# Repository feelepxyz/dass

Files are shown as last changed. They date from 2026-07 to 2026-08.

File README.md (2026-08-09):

# DASS

## A small outdoor toilet, drawn from a parametric model

[Open the interactive cut guide and model](https://feelep.xyz/dass)

| Attribution | Detail |
| --- | --- |
| Design source | Hannes Söderquist's outdoor toilet design |
| CAD | CadQuery and Python |
| Text-to-CAD reference | [earthtojake/text-to-cad](https://github.com/earthtojake/text-to-cad) |
| Current material | 45 × 45 mm beams and 120 × 23 mm Råspont (matchboard/V-groove cladding) |

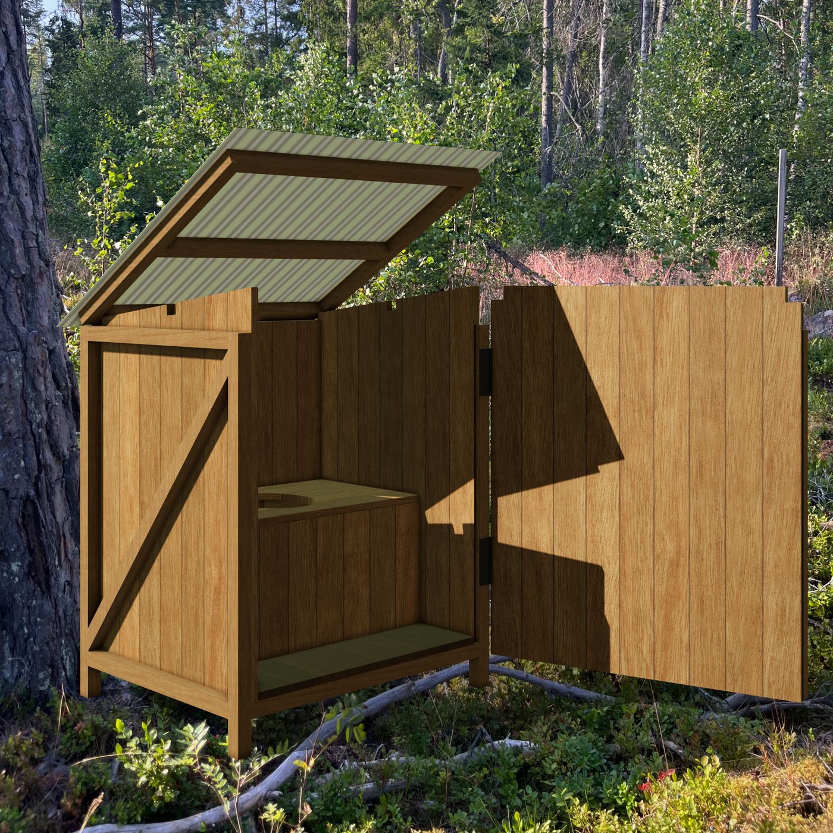
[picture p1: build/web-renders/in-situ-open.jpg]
Open in-situ render


This repository contains the parametric model, the browser cut guide, and the
source material for a small outdoor toilet. The live guide shows the open and
closed model, the unit drawings, and the workshop cut sequence.

## Current release

Version `0.1.8` clears the Hold boxes off the working drawing, so each unit
sheet runs from its general arrangement straight into its first numbered step.
Read the [full changelog](CHANGELOG.md).

## Run the guide

```sh
uv sync
uv run serve-guide
```

This builds the cut schedules, the guide and progress pages, the GLB models the
viewer loads, and the browser assets, then serves them and opens
<http://localhost:8000/cut-guide.html>. It uses HTTP because the guide loads ES
modules, the GLB models, and its textures, which a `file://` page cannot read.
It installs the renderer's Node dependencies the first time, and it moves to the
next free port if 8000 is taken.

Leave it running. When you save a source file it rebuilds the parts of the guide
that read it and the open page reloads itself.

| Option | Effect |
| --- | --- |
| `--port 8080` | Prefer this port instead of 8000 |
| `--renders` | Re-photograph the model first; minutes of headless Chromium |
| `--page how-its-going.html` | Open a different page |
| `--page how-it-started.html` | Open the project history page |
| `--no-open` | Leave the browser alone |

The photorealistic images are the one thing a save does not rebuild. Make them
when the model changes:

```sh
uv run render-photo
```

Each step also runs on its own; `AGENTS.md` lists them.

The deploy command rebuilds the guide and publishes the Worker:

```sh
./scripts/deploy-cut-guide.sh
```

The main Python commands accept parameter overrides. For example:

```sh
uv run dass --set width=1050 --set seat_depth=550
uv run render-photo --views open-hero --skip-build
```

## Git hooks

`prek` checks each commit and runs the tests before each push:

```sh
prek install          # once, after cloning
prek run --all-files  # run every hook now
```

The commit hooks run `ruff format`, `ruff check`, and `ty`, and they cover shell
scripts, file hygiene, and YAML, JSON, and TOML syntax. The push hook runs the
`pytest` suite, which takes about half a minute. They skip `.agents/`, `build/`,
and `.cache/`, which hold vendored and generated files. Bypass them with
`git commit --no-verify` when you must.

GitHub Actions runs the same four checks on every push and pull request, on
Python 3.11 and 3.14.

## Worktrees

`wta <branch>` opens a worktree with the agent and the guide server already
running, from the hooks in `.config/wt.toml`:

```sh
wta fix-seat        # new worktree off the default branch
wt list             # what is checked out where
wt remove           # tear the worktree and its panes down
```

The guide pane runs `serve-guide --no-open`. It takes the next free port, so
several worktrees can serve their own guide at the same time.

## Model

The current design has a 990 × 815 mm outside envelope. It uses 45 × 45 mm
frame stock and 120 × 23 mm interleaved Råspont (matchboard/V-groove cladding). Each board has 110 mm of
effective cover and a 10 mm trim allowance.

The door is nine covers wide. Each side is seven covers deep. The rear wall,
floor, seat top, and seat front use the fitted spans from the frame. The roof
uses a 1050 × 1085 mm metal sheet over a hinged 45 mm timber frame.

The model is the dimensional source of truth. The cut-list generator derives
the piece schedules and the stop-block sequence from that model. It reserves a
kerf for each released piece and keeps equal-length cuts together.

The guide treats the roof, door, side walls, back wall, floor, and seat as
separate units. This keeps the drawings, part codes, and workshop order tied to
the geometry.

## Unit drawings

These images show the guide's line finish. They show the frame and model edges,
without the photoreal material finish or assembly instructions.

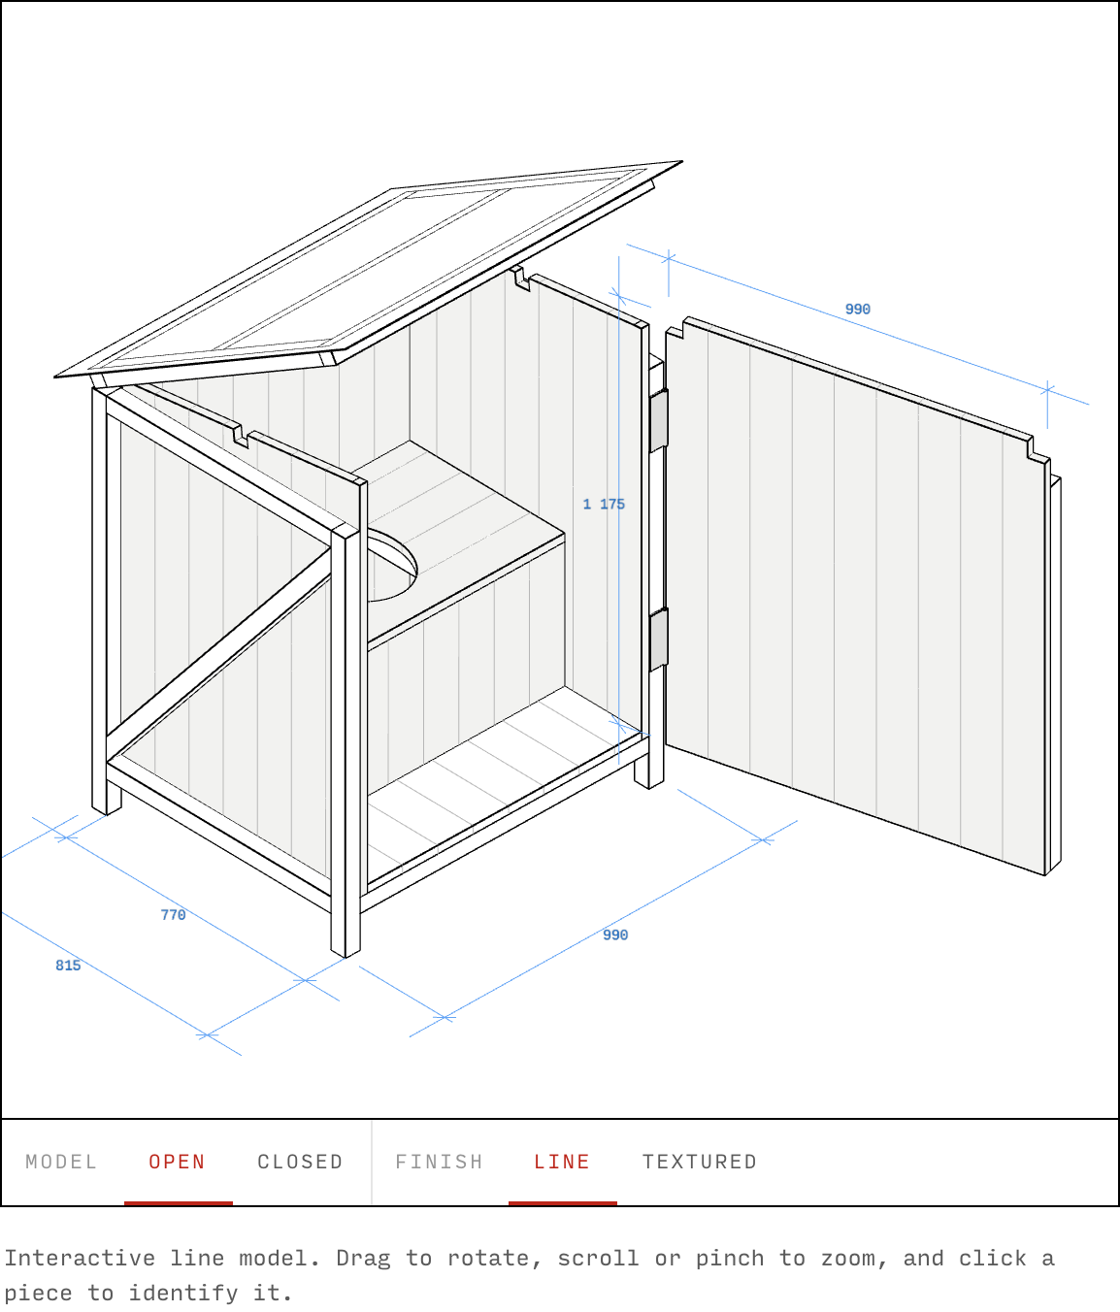
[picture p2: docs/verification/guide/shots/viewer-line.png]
Open frame model


The open frame model shows the roof, door, left and right side units, back wall,
floor deck, and seat box as separate pieces around the same model datum.

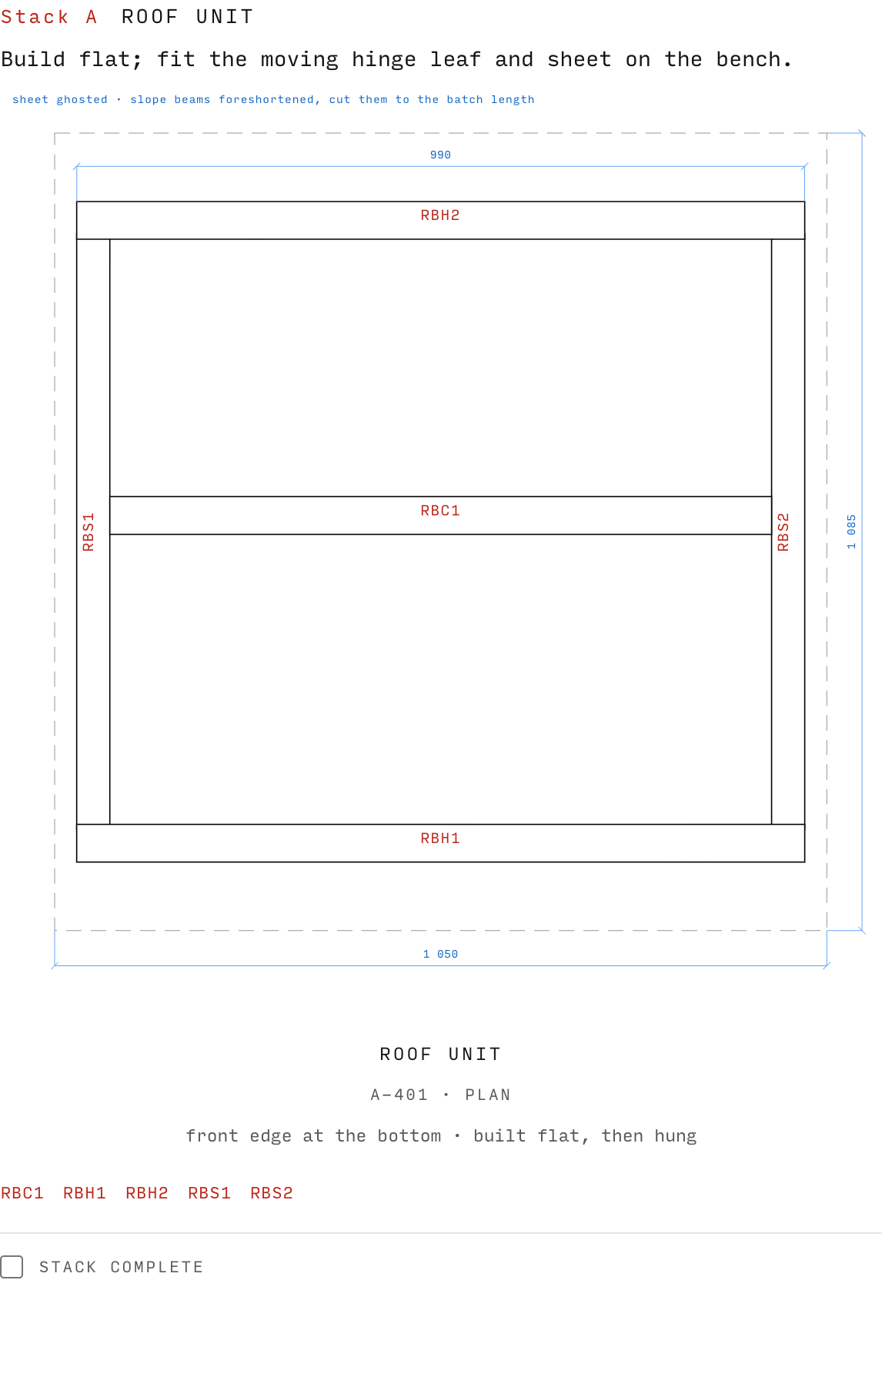
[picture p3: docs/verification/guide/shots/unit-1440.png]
Roof unit drawing


The roof unit is a hinged rectangular frame with two slope beams, two cross
beams, and one middle connector.

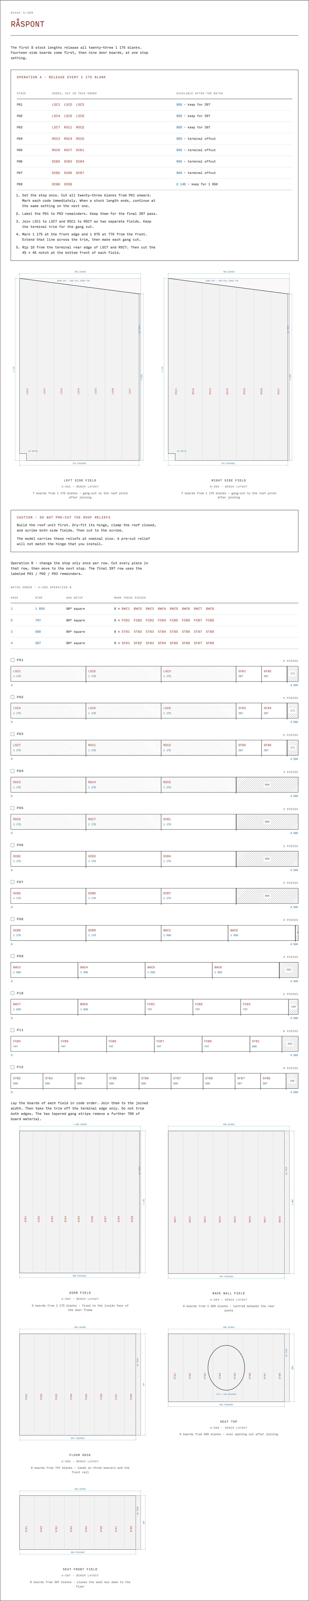
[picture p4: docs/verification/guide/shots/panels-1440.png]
Panel unit drawings


The panel sheet shows the door field, both side fields, the back field, floor
deck, seat top, and seat front. The fields are fitted to their frames in the
CAD model and receive their final trim on the unit.

- Roof: hinged timber frame with a middle connector and metal sheet.
- Door: full-height frame with a diagonal brace and notched top corners.
- Side walls: left and right sloped frames with gang-cut cladding fields.
- Back wall: fitted frame and cladding field between the side skins.
- Floor: front-to-back deck with two edge bearers.
- Seat: box, opening, rails, and supports around the oval seat hole.

## Evolution

The project started with [Hannes Söderquist](https://www.instagram.com/hannes.soderquist/)'s
design for an outdoor toilet. The original drawing uses 50 × 50 mm beams and
120 × 25 mm cladding.

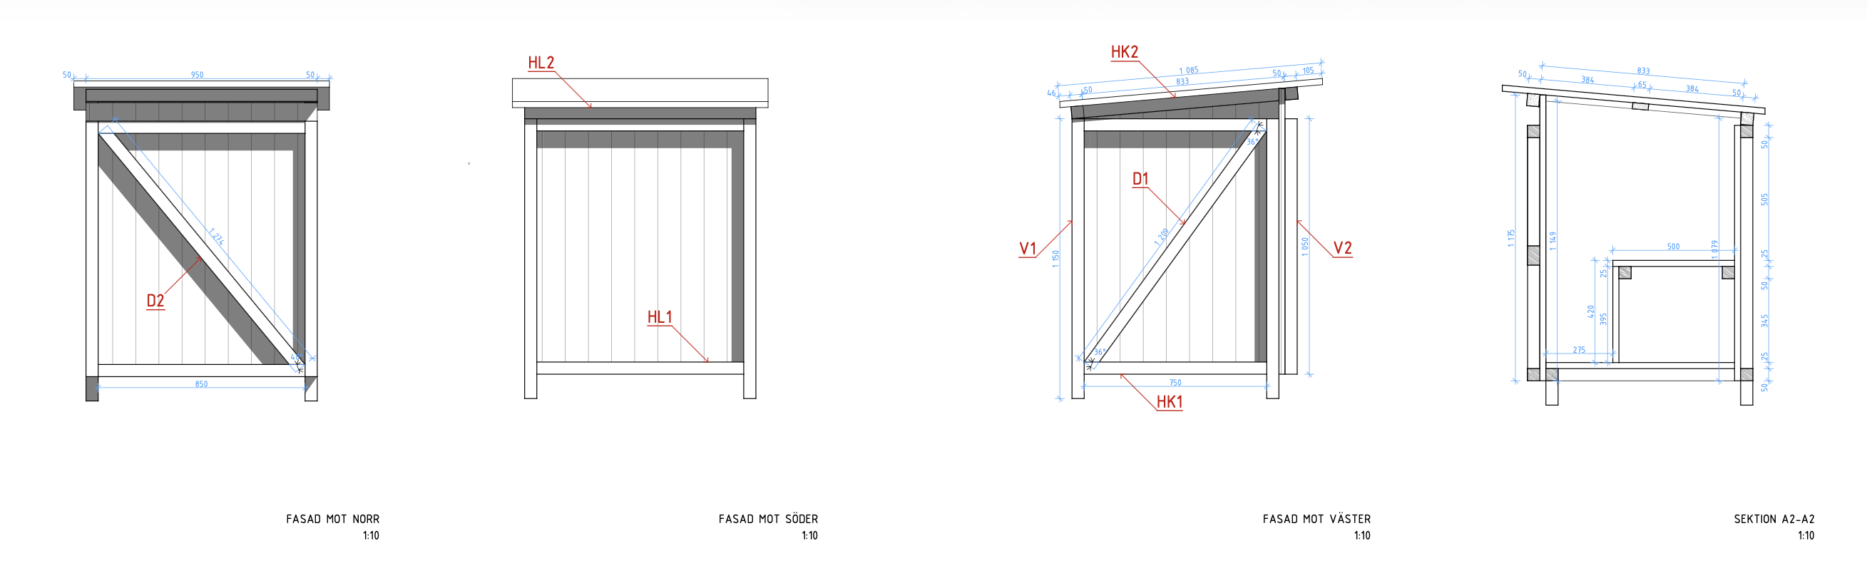
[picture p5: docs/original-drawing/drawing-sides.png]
Original side drawing


I asked Claude and Codex to build a CAD model with CadQuery and build123d. The
first generated versions had several geometry problems and did not match the
source design. I did not edit any of the CAD drawings directly. Instead, I gave
Codex the goal of continuing until the model aligned with the measurements in
the drawing, and supplied measurements from the drawing as model specifications,
such as how long each beam should be. I had to do a lot of nudging to make sure
no material clipped into another part and created impossible cuts.

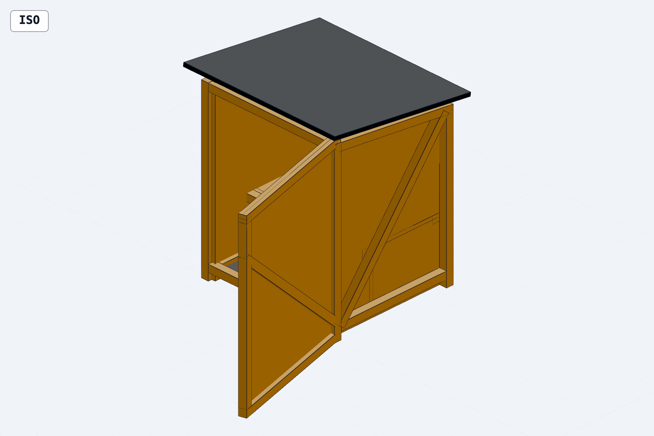
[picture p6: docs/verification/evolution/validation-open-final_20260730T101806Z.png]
Early open-model validation


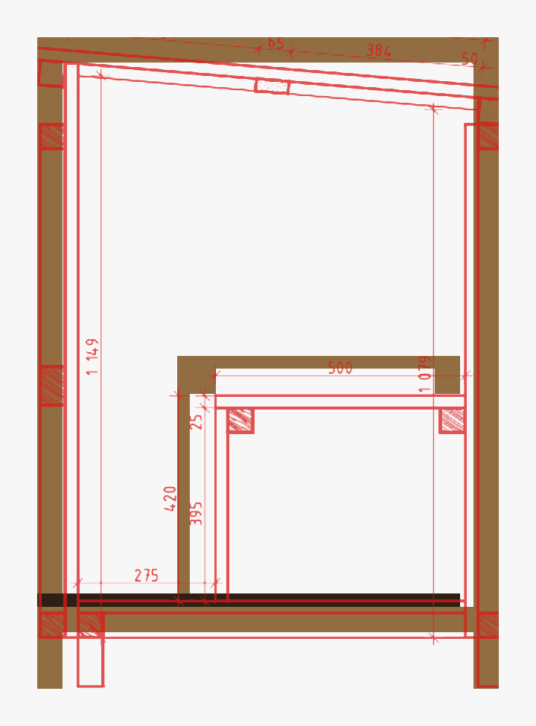
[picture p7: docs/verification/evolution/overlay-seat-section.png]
Seat-section comparison


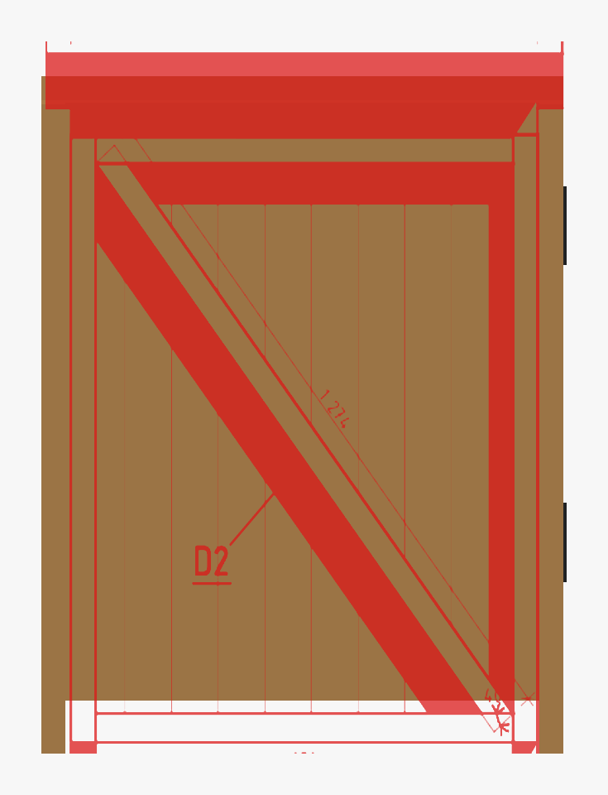
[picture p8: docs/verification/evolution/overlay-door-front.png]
Door-front comparison


One cool side-effect of the CAD model was that Codex could run some basic
structural analysis on the original drawing. It found that the floor boards did
not have enough support, so we added support beams.

The next step was to adapt the design to material available in the local shop:
45 × 45 mm beams and 120 × 23 mm Råspont (matchboard/V-groove cladding). I also changed the shape slightly
so that each interleaved cladding board has at least 10 mm of trim. The board
ends therefore do not leave a lip outside the frame.

From there, the cut schedules follow the material lengths in the shop. The
optimizer groups equal-length cuts so that they can run in sequence with a
stop block on the saw. This uses more material than a fully nested plan, but it
avoids repeated measuring and small length differences between equal pieces.

The same model then generates assembly instructions that treat the door, roof,
side walls, back wall, floor, and seat as individual pieces.

## Assembly hardware

Use these fasteners for the timber assembly:

| Use | Fastener |
| --- | --- |
| Frame beams and braces | 6 × 120 mm sunk wood screws |
| Beam-to-beam support joints, for example floor supports | 6 × 90 mm sunk wood screws |
| Råspont (matchboard/V-groove cladding) to beams | 2.8 × 60 mm nails or 6 × 60 mm sunk wood screws |

Do not use the cladding fasteners for beam joints.

## Geometry notes

The design reconciles the supplied drawing with the material change in a few
important ways:

- The earlier 950 × 850 mm reference envelope becomes 990 × 815 mm outside the
  45 mm frame, so the exposed cladding fields fit 110 mm cover modules.
- The side fields fall 100 mm over 800 mm. The roof falls 125 mm over its clear
  833 mm run. The side fields are relieved around the roof frame after fixing.
- The back field fits between the side skins. The side skins therefore close the
  rear corners instead of leaving a cladding overlap behind them.
- The braces use one angled cut at each end. Their long-point lengths come from
  the exact corner-to-corner geometry. Their mitred ends stop at the inner
  faces of the vertical members, and the fastening audit checks the modeled
  screw paths.
- The floor has two edge bearers. The seat opening has a support bearer on each
  side, between the seat rails.

The tests check the default model, the wider design variant, the 45 × 45 mm
material variant, clearances, hinge movement, brace geometry, board fields, and
cut-plan capacity.

## Web media and renders

Source web media lives in `web/media/`. This includes the Input Mono font, the
wood texture maps, and `background.jpg`, which is the forest clearing used by
the in-situ render.

The photoreal renderer writes its generated images and GLB variants to
`build/renders/`. The web asset step converts those images to the files served
from `build/web-renders/` and stages the browser textures, font, vendor modules,
and model files beside the guide.

The progress page uses the local browser-ready MP4 by default. To use a
Cloudflare Stream upload instead, export the Stream customer code and video UID
before building or deploying:

    DASS_CLOUDFLARE_STREAM_CUSTOMER_CODE=... \
    DASS_CLOUDFLARE_STREAM_VIDEO_ID=... \
    ./scripts/deploy-cut-guide.sh

When both values are set, the page uses Cloudflare's responsive Stream Player
iframe and the local video pair is not staged for deployment.

Use `docs/original-drawing/` for supplied drawings and render targets. Use
`docs/verification/` for retained geometry checks, drawing comparisons, guide
screenshots, inspection records, and evolution images.

## Model changelog

Version 0.1.8 (2026-08-09) takes the Hold boxes off the unit sheets, leaving
each unit's general arrangement and its numbered steps. Read the
[full changelog](CHANGELOG.md) for the dated model history.

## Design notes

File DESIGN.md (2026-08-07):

---
name: DASS Drawing Set
description: A construction drawing set for building the parametric outdoor toilet.
colors:
  sheet: "#ffffff"
  field: "#f2f2f0"
  ink: "#151515"
  line: "#000000"
  timber: "#7f7f7f"
  grey-dark: "#5a5a5a"
  grey-mid: "#959595"
  grey-light: "#b7b7b7"
  grey-pale: "#e6e6e6"
  code: "#bb261a"
  code-deep: "#8f1c13"
  dim: "#63a4f5"
  dim-ink: "#1668c4"
typography:
  lettering:
    fontFamily: "InputMono, ui-monospace, SFMono-Regular, Consolas, monospace"
    fontSize: "0.72rem"
    fontWeight: 400
    lineHeight: 1.2
    letterSpacing: "0.08em"
    textTransform: "uppercase"
  sheet-title:
    fontFamily: "InputMono, ui-monospace, SFMono-Regular, Consolas, monospace"
    fontSize: "clamp(1.5rem, 3.2vw, 2.6rem)"
    fontWeight: 400
    lineHeight: 1.1
    letterSpacing: "0.02em"
    textTransform: "uppercase"
  note:
    fontFamily: "InputMono, ui-monospace, SFMono-Regular, Consolas, monospace"
    fontSize: "0.83rem"
    fontWeight: 400
    lineHeight: 1.65
    letterSpacing: "0"
  caption:
    fontFamily: "InputMono, ui-monospace, SFMono-Regular, Consolas, monospace"
    fontSize: "0.7rem"
    fontWeight: 400
    letterSpacing: "0.14em"
    textTransform: "uppercase"
  fine:
    fontFamily: "InputMono, ui-monospace, SFMono-Regular, Consolas, monospace"
    fontSize: "0.62rem"
    fontWeight: 400
    letterSpacing: "0.14em"
    textTransform: "uppercase"
  mark:
    fontFamily: "InputMono, ui-monospace, SFMono-Regular, Consolas, monospace"
    fontSize: "0.76rem"
    fontWeight: 400
    letterSpacing: "0.06em"
  doc-title:
    fontFamily: "InputMono, ui-monospace, SFMono-Regular, Consolas, monospace"
    fontSize: "clamp(1.7rem, 4.2vw, 3rem)"
    fontWeight: 400
    letterSpacing: "0.01em"
    textTransform: "uppercase"
  drawing-mark:
    fontFamily: "InputMono, ui-monospace, SFMono-Regular, Consolas, monospace"
    fontSize: "16px"
    fontWeight: 400
    letterSpacing: "0.08em"
  drawing-detail:
    fontFamily: "InputMono, ui-monospace, SFMono-Regular, Consolas, monospace"
    fontSize: "13px"
    fontWeight: 400
    letterSpacing: "0.06em"
  drawing-dimension:
    fontFamily: "InputMono, ui-monospace, SFMono-Regular, Consolas, monospace"
    fontSize: "12px"
    fontWeight: 400
    letterSpacing: "0.04em"
strokes:
  hairline: "0.5px"
  object: "0.8px"
  section: "1.4px"
  border: "1px"
spacing:
  tick: "4px"
  unit: "8px"
  field: "20px"
  sheet: "40px"
  gap: "72px"
components:
  code-mark:
    textColor: "{colors.code}"
    textDecoration: "underline"
  dimension:
    lineColor: "{colors.dim}"
    textColor: "{colors.dim-ink}"
---

# Design System: DASS Drawing Set

## Overview

**Creative North Star: "The Drawing Set"**

The guide is a construction drawing set, in the convention of the Swedish
`arbetsritning` that `drawing-sides.png` comes from. White sheets carry thin
black line work, grey cut timber, red part codes on leader lines, and blue
dimension chains. Every figure is a numbered drawing with a centred uppercase
caption beneath it. Tables and stock diagrams are sheet content drawn to the
same line weights, not web components wearing a new skin.

The document does not decorate itself. It has the authority of a drawing that
someone builds from.

## Colors

The sheet is white. Line work and lettering are black. Cut timber reads as flat
grey. Two inks carry meaning and nothing else carries them:

- **Red `#bb261a`** is part codes, and only part codes. A code is red wherever
  it appears: on a leader, in a table, on a stock bar, in the register.
- **Blue** is dimensions and measured detail, and only those. Lines take
  `#63a4f5`, faithful to the reference. Numerals take `#1668c4`.

The blue split is deliberate. The reference blue is a print ink at drawing
scale; at screen text sizes it holds about 2.4:1, so numerals darken to reach
4.5:1 while the lines keep the reference value. Never set body or numeral text
in `#63a4f5`.

Dark red `#8f1c13` sets sheet titles. Greys run `#5a5a5a` `#7f7f7f` `#959595`
`#b7b7b7` `#e6e6e6` for timber fill, hatching, rules, and inactive states.

## Typography

Input Mono Regular is the only face, at one weight. This is correct for the
world: drawing lettering is monoline, and a set has no bold. Hierarchy comes
from size, color, case, letterspacing, and rules.

Uppercase with open tracking carries all lettering: sheet titles, drawing
captions, table headers, codes, dimensions, title blocks, controls, labels.

Instruction prose stays sentence case in the same face. Drawing sets letter
their labels in capitals and set their specification notes in sentence case,
and a workshop instruction has to survive one read with gloves on. Never set a
paragraph in capitals.

The font has 210 glyphs and no `→`. Sequences use `·` between terms.

The page letters at four steps plus two display steps: `0.62rem` fine,
`0.7rem` caption, `0.76rem` mark, `0.83rem` note, then the sheet title and the
document title, both fluid. Mobile shifts the four lettering steps down one
notch by redefining the tokens, never by restyling a rule.

Inside a drawing the steps sit close on purpose — `16px` for a code, `13px` for
a detail note, `12px` for a dimension, all in the plate's 1000-unit space. CAD
lettering is near-uniform by convention; rank inside a drawing comes from ink
colour and from what the text is attached to, not from size. Do not open these
steps up to satisfy a contrast ratio meant for page type.

A step plate carries a fraction of what a general arrangement carries and is
drawn at roughly half its width, so it letters larger inside the same
1000-unit space: `24px` for a code, `23px` for the operation, `17px` for a
dimension, a datum or a detail note, `16px` for a board code, `18px` for the
hardware call. These are the same ranks at the same finished size, not a
second ramp; print raises the code to `27px` so no code on paper prints
smaller than the ones on the general arrangements.

## Layout

One sheet per phase, separated by generous quiet. Each sheet opens with a rule,
its number, its title, and one title block. Drawings sit inside the sheet with
their own caption and drawing number beneath, centred.

Title blocks are per sheet, never per figure. A set repeats its project stamp
once per sheet and numbers the drawings inside it; repeating the stamp under
every figure would print the same four facts sixteen times.

Text never touches a rule. Minimum 20px between any lettering and the line
below it, 40px above a sheet title. More space above a heading than below it.

## Elevation & Depth

The system is flat. There are no shadows, no fills that are not a material, and
no rounded corners. Depth is line weight: hairline for dimensions, thin for
objects, thicker for what the section plane cuts.

## Shapes

Every corner is square. Dashed lines mean an object that belongs to another
drawing, a cut not yet made, or a part travelling to its seat. Cut timber is
solid grey. Joined cladding is a pale tint with its board joints ruled across
it. A field that is present only because this step has not reached it yet is
filled with no edge of its own, so nothing implies a cut that has not happened.

## Line weights

Four tiers, `vector-effect: non-scaling-stroke` throughout:

| Tier | Width | Carries |
|---|---|---|
| Hairline | 0.5px | dimensions, leaders, board joints, hatching |
| Object | 0.8px | member outlines, field edges, blanks |
| Section | 1.4px | the cut plane, gang cuts, openings |
| Border | 1px | sheet rules, table rules, title blocks |

## Components

**Code mark.** Red, uppercase, underlined when it sits on a leader — the
reference underlines every code. Leaders are hairline red with a small dot at
the target.

**Dimension.** Blue chain with tick serifs, the numeral centred and clear of
the line. Values are measured off the model, never typed. Thousands are spaced
(`1 085`), matching the reference.

**Stock bar.** A scaled diagram of one stock length: pieces drawn in place with
their code and length, saw ticks at each cut, the terminal offcut hatched.

**Title block.** One per sheet. Project, sheet number, issue date, units.

**Operation stamp.** One band under every step drawing, ruled off it in plate
space reserved below the dimension gutter so it can never land on a dimension
run. The operation at the left, and the fastener or tool it takes boxed at the
right. It reads before the caption does, which is why it is drawn at all.

**Travel track.** Hairline dashed, with an open arrowhead at the seat, from a
member drawn off its seat to the ghost of where it goes. Only an assembly step
carries one.

**Datum.** A solid triangle whose apex touches the edge a step works from — a
guide edge, a landing mark, a level — with its lettering clear of the geometry.
The edge is named once, on the step that uses it.

**Set-out line.** A cut marked and not yet made: section weight, dashed. It
becomes solid at the step that makes it, and the waste beside it is hatched.

## Do's and Don'ts

### Do:

- **Do** put a dimension on the drawing it belongs to, and write it once.
- **Do** keep red for codes and blue for dimensions, with no exceptions.
- **Do** letter in capitals and write instructions in sentence case.
- **Do** keep every drawing legible in black and white.

### Don't:

- **Don't** print the same number in two places on one sheet.
- **Don't** use a weight axis; the face has one weight and needs none.
- **Don't** add fills, shadows, rounded corners, or accent colors.
- **Don't** put a title block under every figure.

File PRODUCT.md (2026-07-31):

# Product

<!-- impeccable:product-schema 1 -->

## Platform

web

## Users

The primary user is the owner-builder fabricating a small outdoor toilet from
standard timber and Råspont (matchboard/V-groove cladding) stock. The guide is used in a workshop while
measuring, cutting, marking, stacking, and later assembling parts.

## Product Purpose

Turn the parametric CAD model into an exact, printable stock-cut and assembly
guide. Success means every blank can be cut once, marked with a unique short
code, and stacked by build unit. Final cladding edges are cut on the fixed unit.

## Positioning

The guide keeps stock planning, physical cut order, part marking, and
modular construction instructions tied to one parametric dimensional source of
truth.

## Operating Context

- Metric workshop measurements in millimetres.
- 45 × 45 × 4200 mm structural timber.
- 120 × 23 × 4500 mm Råspont (matchboard/V-groove cladding) with 110 mm effective cover.
- 2.8 mm saw kerf.
- All 1175 mm side and door blanks are cut at one stop setting before the
  smaller batches. Side boards are fixed to their frames before their slope
  and terminal edges are cut.
- The final guide must work on screen and as a printed shop-floor packet.

## Capabilities and Constraints

- The CAD `Design` defaults and generated model are the dimensional authority.
- Every timber and cladding piece needs a stable, logical uppercase code.
- Stock plans must include kerf and prove that no stock length is exceeded.
- The cladding plan must fit the available twelve stock lengths; three labeled
  early remainders return only for the final 397 mm batch.
- Roof, door, both side walls, back wall, and floor should be buildable as
  standalone units where the geometry permits. The seat box is installed after
  the shell is assembled.
- The 1050 × 1085 mm metal roof sheet and hardware are identified separately
  from the timber stock optimization.

## Assembly hardware

| Use | Fastener |
| --- | --- |
| Frame beams and braces | 6 × 120 mm sunk wood screws |
| Beam-to-beam support joints, for example floor supports | 6 × 90 mm sunk wood screws |
| Råspont (matchboard/V-groove cladding) to beams | 2.8 × 60 mm nails or 6 × 60 mm sunk wood screws |

## Evidence on Hand

- Parametric CAD source: `src/dass/model.py`.
- Cut-list source and optimizer: `src/dass/cutlists.py`.
- Existing generated STEP, GLB, PNG, and CSV artifacts under `build/`.
- Reconciled source notes and fit rules: `README.md`.
- Reference drawings: `docs/original-drawing/`.

## Product Principles

- Model-derived dimensions beat copied dimensions.
- A cut is not complete until the piece is coded and assigned to a stack.
- The physical cutting sequence matters as much as theoretical nesting.
- Reusable offcuts stay visible and traceable.
- Construction is organized around stable standalone modules.

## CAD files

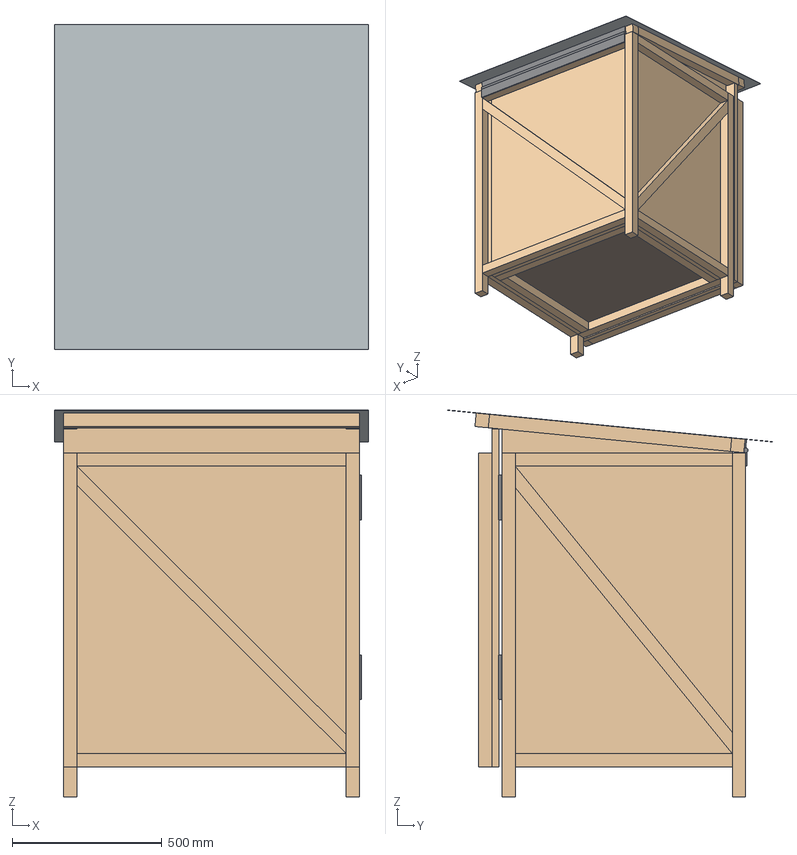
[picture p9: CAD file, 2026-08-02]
build/dass-closed.step
1050.0 x 1085.0 x 1292.9 mm
front_post_left
back_post_left
front_post_right
back_post_right
front_bottom
back_bottom
left_bottom
left_top
right_bottom
right_top
back_top
roof_front
roof_back
roof_left
roof_right
roof_middle
left_wall
right_wall
back_wall
floor
floor_back_support
floor_left_support
floor_right_support
seat_box_support_front
seat_box_support_rear
seat_floor_support
seat_front
seat_top
seat_rail_1
seat_rail_2
seat_support_left
seat_support_right
seat_support_outer_left
seat_support_outer_right
left_brace
right_brace
back_brace
roof
roof_hinge_fixed
roof_hinge_moving
roof_hinge_pin
door_panel
door_left
door_right
door_bottom
door_top
door_brace
hinge_fixed_1
hinge_door_1
door_hinge_1
hinge_fixed_2
hinge_door_2
door_hinge_2

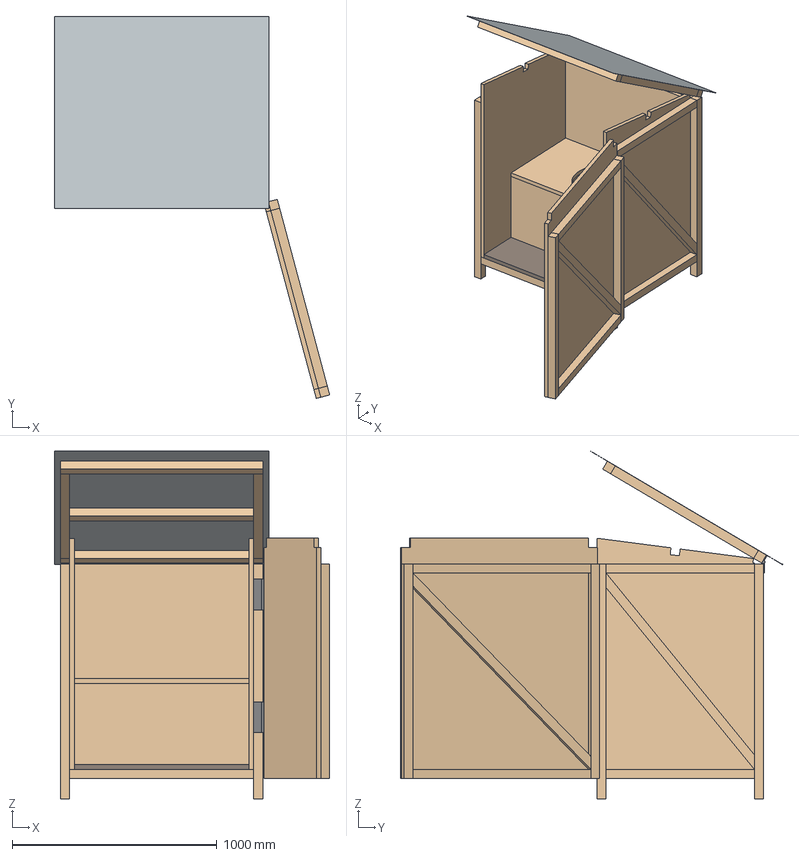
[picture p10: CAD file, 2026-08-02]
build/dass-open.step
1346.7 x 1867.9 x 1701.1 mm
front_post_left
back_post_left
front_post_right
back_post_right
front_bottom
back_bottom
left_bottom
left_top
right_bottom
right_top
back_top
roof_front
roof_back
roof_left
roof_right
roof_middle
left_wall
right_wall
back_wall
floor
floor_back_support
floor_left_support
floor_right_support
seat_box_support_front
seat_box_support_rear
seat_floor_support
seat_front
seat_top
seat_rail_1
seat_rail_2
seat_support_left
seat_support_right
seat_support_outer_left
seat_support_outer_right
left_brace
right_brace
back_brace
roof
roof_hinge_fixed
roof_hinge_moving
roof_hinge_pin
door_panel
door_left
door_right
door_bottom
door_top
door_brace
hinge_fixed_1
hinge_door_1
door_hinge_1
hinge_fixed_2
hinge_door_2
door_hinge_2

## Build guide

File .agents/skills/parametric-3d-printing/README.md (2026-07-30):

# CAD Skill for Claude Code

A [Claude Code](https://docs.anthropic.com/en/docs/claude-code) skill for generating parametric 3D-printable models using [CadQuery](https://cadquery.readthedocs.io/). Describe a physical object, and Claude will write a parametric script, export STL, render previews, and iterate with you until it's right.

<p align="center">
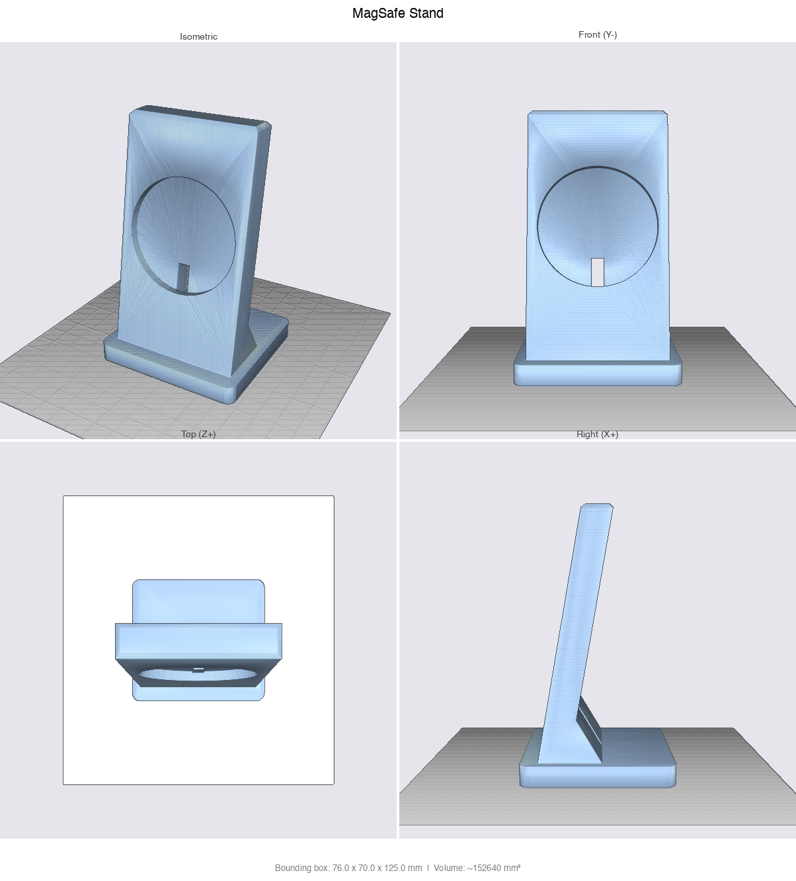
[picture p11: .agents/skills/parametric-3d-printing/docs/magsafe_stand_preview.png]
MagSafe stand preview, 4 views
  
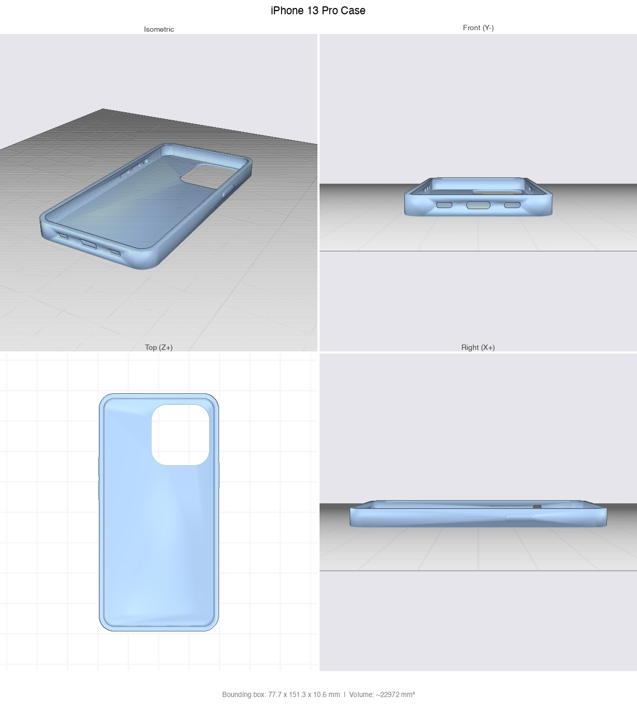
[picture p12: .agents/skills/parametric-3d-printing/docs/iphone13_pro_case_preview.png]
iPhone 13 Pro case preview, 4 views
  
</p>

Read the full write-up: [I Taught Claude to Design 3D-Printable Parts. Here's How](https://medium.com/@nchourrout/i-taught-claude-to-design-3d-printable-parts-heres-how-675f644af78a)

## More examples

Published on [MakerWorld](https://makerworld.com/en/@sercanto).

<p align="center">
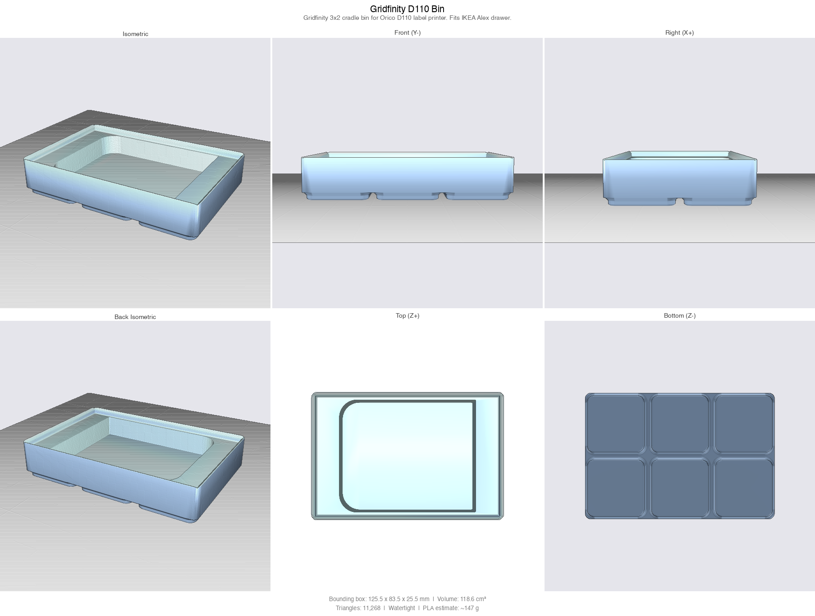
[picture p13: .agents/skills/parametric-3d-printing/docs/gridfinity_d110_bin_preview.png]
Gridfinity 3x2 bin for Orico D110 label printer
  
</p>

<p align="center">
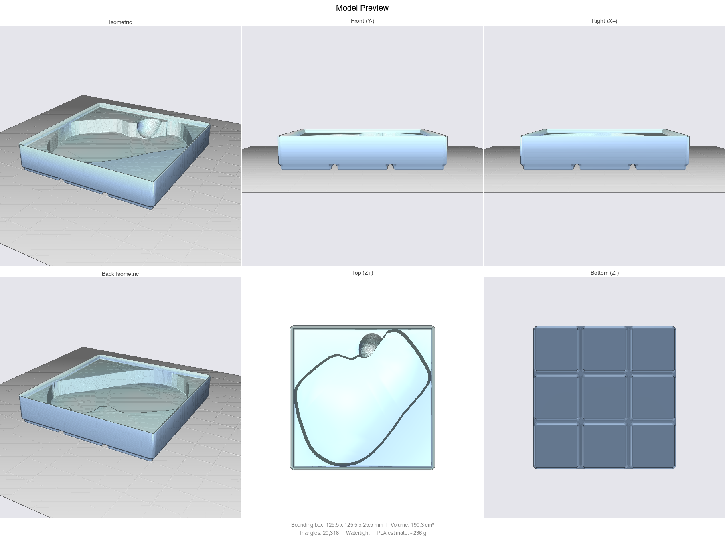
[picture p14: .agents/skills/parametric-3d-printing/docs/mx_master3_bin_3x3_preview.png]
Gridfinity 3x3 bin for Logitech MX Master 3, pocket traced from a 3D scan
  
</p>

The MX Master 3 bin above ([examples/mx_master3_bin_3x3.py](examples/mx_master3_bin_3x3.py), [printed and published on MakerWorld](https://makerworld.com/en/models/3049470-gridfinity-bin-for-logitech-mx-master-3-3x3)) shows the scan-to-pocket pipeline: `outline_from_scan.py` traces the mouse's real footprint from a 3D scan, the outline is rotated to the angle that minimizes its bounding square so the bin fits a 3x3 grid instead of 4x3, and a tilted thumb scoop ramps under the thumb rest to lift the mouse out.

<p align="center">
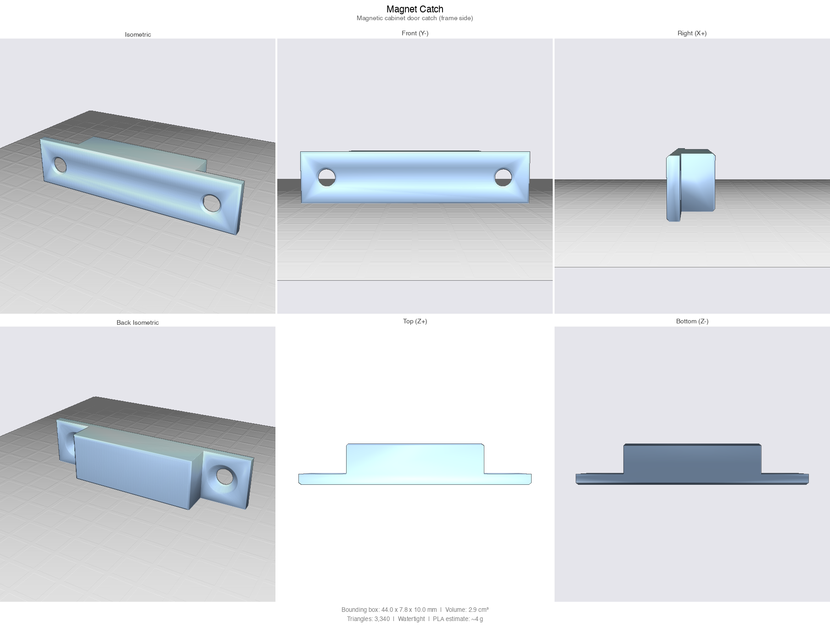
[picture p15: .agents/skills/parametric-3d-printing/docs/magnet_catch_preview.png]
Magnetic door catch (frame side)
  
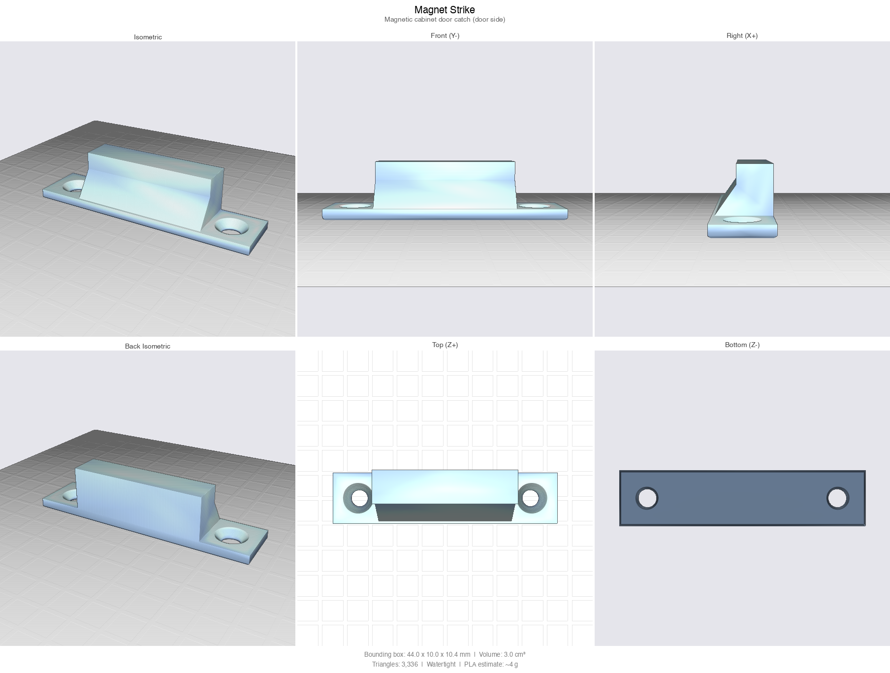
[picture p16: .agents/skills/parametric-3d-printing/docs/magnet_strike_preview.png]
Magnetic door catch (door side)
  
</p>

## Installation

```bash
mkdir -p ~/.claude/skills
git clone https://github.com/flowful-ai/cad-skill ~/.claude/skills/parametric-3d-printing
```

## Usage

Once installed, the skill activates in two ways inside Claude Code:

- **Auto-trigger.** Describe a part you want to print ("design a wall mount for an Arduino Uno", "I need a snap-fit lid for this box") and Claude picks up the skill from its trigger keywords (3D print, STL, CadQuery, enclosure, bracket, and so on).
- **Explicit slash command.** Type `/parametric-3d-printing` to invoke it directly, useful when your request does not contain the obvious keywords.

Claude will then walk you through requirements, build the model in phases (base shape, features, finish), and deliver an STL plus a rendered preview.

## Dependencies

Requires **Python 3.10-3.12** (CadQuery's OCC kernel does not have wheels for 3.13+):

```bash
python3.12 -m venv .venv && source .venv/bin/activate
pip install -r requirements.txt
```

## Files

| File | Purpose |
|---|---|
| `SKILL.md` | Skill definition and workflow instructions for Claude |
| `gridfinity.py` | Tested Gridfinity bin generator (base profile, stacking lip, magnets, compartments, custom pockets). Vendored next to generated scripts. |
| `outline_from_scan.py` | Extracts a pocket outline from a 3D scan of an object (align, scale, slice, union), ready for `add_polygon_pocket`. |
| `examples/` | Model scripts built on the gridfinity module (D110 cradle, MX Master 3 diagonal bin). |
| `preview.py` | Headless STL to 6-view PNG renderer (trimesh + pyrender). Use `--strict` to fail on non-watertight meshes. |
| `run_cadquery_model.py` | Subprocess wrapper that runs a CadQuery script, captures errors, optionally renders the preview, and emits a JSON result so Claude can self-correct in a loop. |
| `mesh_io.py` | STL loading with validation (no pyrender dependency). Used by the wrapper and converter. |
| `stl_to_3mf.py` | Standalone STL to 3MF converter for Bambu Studio / PrusaSlicer. |
| `design-review.md` | Visual inspection checklist and printability analysis |
| `requirements.txt` | Pinned dependency versions |

## License

The skill and scripts are licensed under the [PolyForm Noncommercial License 1.0.0](LICENSE). Free to use, modify, and distribute for noncommercial purposes.

---

Created by [Nicolas Chourrout](https://github.com/nchourrout) from [Flowful.ai](https://flowful.ai)

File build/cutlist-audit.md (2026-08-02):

# Cut-list audit

| Part | reconciled cut list | reconciled drawing | generated CAD | Result |
|---|---|---|---|---|
| V1 | 4 × 1150 | 4 × 1150 | 4 parts: 1150.0, 1150.0, 1150.0, 1150.0 | match |
| V2 | 2 × 1050 | 2 × 1050 | 2 parts: 1050.0, 1050.0 | match |
| D1 | 2 × 1209 | 2 × 1209 | 2 parts: 1203.0, 1203.0 | ERROR |
| D2 | 1 × 1274.8 | 1 × 1274.8 | 2 parts: 1315.9, 1315.9 | ERROR |
| HK1 | 4 × 750 | 4 × 750 | 4 parts: 725.0, 725.0, 725.0, 725.0 | ERROR |
| HK2 | 2 × 833 | 2 × 833 | 2 parts: 812.7, 812.7 | ERROR |
| HL1 | 5 × 850 | 5 × 850 | 4 parts: 852.0, 852.0, 900.0, 900.0 | ERROR |
| HL2 | 2 × 950 | 2 × 950 | 4 parts: 900.0, 900.0, 990.0, 990.0 | ERROR |

## Notes

- The source image specifies 50×50 stock for every row.
- User reconciliation assigns V1 to four structural uprights, V2 to two door uprights, and D2 to the single door diagonal.
- The image specifies −36° cuts at both D1 ends and −40° cuts at both D2 ends.
- CAD quantities are derived from the model, not copied from either reference table.
- Exact 850 × 950 mm door opening geometry gives D2 = 1274.8 mm and a 41.8° cut.

## Errors

- D1: image=2 × 1209, drawing=2 × 1209, CAD=2 parts: 1203.0, 1203.0
- D2: image=1 × 1274.8, drawing=1 × 1274.8, CAD=2 parts: 1315.9, 1315.9
- HK1: image=4 × 750, drawing=4 × 750, CAD=4 parts: 725.0, 725.0, 725.0, 725.0
- HK2: image=2 × 833, drawing=2 × 833, CAD=2 parts: 812.7, 812.7
- HL1: image=5 × 850, drawing=5 × 850, CAD=4 parts: 852.0, 852.0, 900.0, 900.0
- HL2: image=2 × 950, drawing=2 × 950, CAD=4 parts: 900.0, 900.0, 990.0, 990.0

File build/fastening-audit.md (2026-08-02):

# Frame fastening audit

This is a beam screw-layout and collision check, not a structural screw-sizing calculation.
Cladding is excluded because its fasteners are listed separately.

## Assembly hardware

| Use | Fastener |
|---|---|
| Frame beams and braces | 6 × 120 mm sunk wood screws |
| Beam-to-beam support joints, for example floor supports | 6 × 90 mm sunk wood screws |
| Råspont (matchboard/V-groove cladding) to beams | 2.8 × 60 mm nails or 6 × 60 mm sunk wood screws |

- Beam-to-beam connections: 53
- Nominal screw marks: 82
- Screw-mark overlaps: 0
- Screw-path collisions: 0
- Result: PASS

## Angle checks

| Check | Use | Drawing guide | Model guide | Run × rise |
|---|---|---:|---:|---:|
| SIDE-PITCH | finished side-frame pitch | 7.4° | 7.4° | 770 × 100 mm |
| ROOF-PITCH | finished roof-beam pitch | 8.8° | 8.8° | 803 × 125 mm |
| D1 | side diagonal saw cut | 36.0° | 34.9° | 725 × 960 mm |
| D2 | back and door diagonal saw cut | 40.0° | 41.2° | 900 × 960 mm |

## Screw marks

| Mark | From beam | Into beam | Face | Source station | Target station / end | Lane / position |
|---|---|---|---|---:|---:|---:|
| F01-1 | LSV1 (front_post_left) | FBH1 (front_bottom) | front | 45.0 mm | 122.5 mm | 12.0 mm |
| F01-2 | LSV1 (front_post_left) | FBH1 (front_bottom) | front | 45.0 mm | 122.5 mm | 33.0 mm |
| F02-1 | RSV1 (front_post_right) | FBH1 (front_bottom) | front | 45.0 mm | 122.5 mm | 12.0 mm |
| F02-2 | RSV1 (front_post_right) | FBH1 (front_bottom) | front | 45.0 mm | 122.5 mm | 33.0 mm |
| F03-1 | LSV2 (back_post_left) | BWH1 (back_bottom) | rear | 45.0 mm | 122.5 mm | 12.0 mm |
| F03-2 | LSV2 (back_post_left) | BWH1 (back_bottom) | rear | 45.0 mm | 122.5 mm | 33.0 mm |
| F04-1 | RSV2 (back_post_right) | BWH1 (back_bottom) | rear | 45.0 mm | 122.5 mm | 12.0 mm |
| F04-2 | RSV2 (back_post_right) | BWH1 (back_bottom) | rear | 45.0 mm | 122.5 mm | 33.0 mm |
| F05-1 | LSV2 (back_post_left) | BWH2 (back_top) | rear | 45.0 mm | 1127.5 mm | 12.0 mm |
| F05-2 | LSV2 (back_post_left) | BWH2 (back_top) | rear | 45.0 mm | 1127.5 mm | 33.0 mm |
| F06-1 | RSV2 (back_post_right) | BWH2 (back_top) | rear | 45.0 mm | 1127.5 mm | 12.0 mm |
| F06-2 | RSV2 (back_post_right) | BWH2 (back_top) | rear | 45.0 mm | 1127.5 mm | 33.0 mm |
| F07-1 | LSV1 (front_post_left) | LSH1 (left_bottom) | side | 45.0 mm | 122.5 mm | 12.0 mm |
| F07-2 | LSV1 (front_post_left) | LSH1 (left_bottom) | side | 45.0 mm | 122.5 mm | 33.0 mm |
| F08-1 | LSV2 (back_post_left) | LSH1 (left_bottom) | side | 45.0 mm | 122.5 mm | 12.0 mm |
| F08-2 | LSV2 (back_post_left) | LSH1 (left_bottom) | side | 45.0 mm | 122.5 mm | 33.0 mm |
| F09-1 | LSV1 (front_post_left) | LSH2 (left_top) | side | 45.0 mm | 1127.5 mm | 12.0 mm |
| F09-2 | LSV1 (front_post_left) | LSH2 (left_top) | side | 45.0 mm | 1127.5 mm | 33.0 mm |
| F10-1 | LSV2 (back_post_left) | LSH2 (left_top) | side | 45.0 mm | 1127.5 mm | 12.0 mm |
| F10-2 | LSV2 (back_post_left) | LSH2 (left_top) | side | 45.0 mm | 1127.5 mm | 33.0 mm |
| F11-1 | RSV1 (front_post_right) | RSH1 (right_bottom) | side | 45.0 mm | 122.5 mm | 12.0 mm |
| F11-2 | RSV1 (front_post_right) | RSH1 (right_bottom) | side | 45.0 mm | 122.5 mm | 33.0 mm |
| F12-1 | RSV2 (back_post_right) | RSH1 (right_bottom) | side | 45.0 mm | 122.5 mm | 12.0 mm |
| F12-2 | RSV2 (back_post_right) | RSH1 (right_bottom) | side | 45.0 mm | 122.5 mm | 33.0 mm |
| F13-1 | RSV1 (front_post_right) | RSH2 (right_top) | side | 45.0 mm | 1127.5 mm | 12.0 mm |
| F13-2 | RSV1 (front_post_right) | RSH2 (right_top) | side | 45.0 mm | 1127.5 mm | 33.0 mm |
| F14-1 | RSV2 (back_post_right) | RSH2 (right_top) | side | 45.0 mm | 1127.5 mm | 12.0 mm |
| F14-2 | RSV2 (back_post_right) | RSH2 (right_top) | side | 45.0 mm | 1127.5 mm | 33.0 mm |
| F15-1 | LSV1 (front_post_left) | LSD1 (left_brace) | side | 45.0 mm | 1105.0 mm | 12.0 mm |
| F15-2 | LSV1 (front_post_left) | LSD1 (left_brace) | side | 45.0 mm | 1105.0 mm | 33.0 mm |
| F16-1 | LSV2 (back_post_left) | LSD1 (left_brace) | side | 45.0 mm | 145.0 mm | 12.0 mm |
| F16-2 | LSV2 (back_post_left) | LSD1 (left_brace) | side | 45.0 mm | 145.0 mm | 33.0 mm |
| F17-1 | RSV1 (front_post_right) | RSD1 (right_brace) | side | 45.0 mm | 1105.0 mm | 12.0 mm |
| F17-2 | RSV1 (front_post_right) | RSD1 (right_brace) | side | 45.0 mm | 1105.0 mm | 33.0 mm |
| F18-1 | RSV2 (back_post_right) | RSD1 (right_brace) | side | 45.0 mm | 145.0 mm | 12.0 mm |
| F18-2 | RSV2 (back_post_right) | RSD1 (right_brace) | side | 45.0 mm | 145.0 mm | 33.0 mm |
| F19-1 | LSV2 (back_post_left) | BWD1 (back_brace) | rear | 45.0 mm | 145.0 mm | 12.0 mm |
| F19-2 | LSV2 (back_post_left) | BWD1 (back_brace) | rear | 45.0 mm | 145.0 mm | 33.0 mm |
| F20-1 | RSV2 (back_post_right) | BWD1 (back_brace) | rear | 45.0 mm | 1105.0 mm | 12.0 mm |
| F20-2 | RSV2 (back_post_right) | BWD1 (back_brace) | rear | 45.0 mm | 1105.0 mm | 33.0 mm |
| F21-1 | FBB1 (floor_back_support) | BWH1 (back_bottom) | inside-back | 45.0 mm | 168.0 mm | 22.5 mm |
| F21-2 | FBB1 (floor_back_support) | BWH1 (back_bottom) | inside-back | 45.0 mm | 822.0 mm | 22.5 mm |
| F22-1 | FBS2 (floor_right_support) | RSH1 (right_bottom) | inside-side | 45.0 mm | 145.0 mm | 22.5 mm |
| F22-2 | FBS2 (floor_right_support) | RSH1 (right_bottom) | inside-side | 45.0 mm | 602.0 mm | 22.5 mm |
| F23-1 | FBS1 (floor_left_support) | LSH1 (left_bottom) | inside-side | 45.0 mm | 145.0 mm | 22.5 mm |
| F23-2 | FBS1 (floor_left_support) | LSH1 (left_bottom) | inside-side | 45.0 mm | 602.0 mm | 22.5 mm |
| F24-1 | LSH1 (left_bottom) | FBH1 (front_bottom) | outside-side | 45.0 mm | beam end centre | beam centre |
| F25-1 | RSH1 (right_bottom) | FBH1 (front_bottom) | outside-side | 45.0 mm | beam end centre | beam centre |
| F26-1 | RBH1 (roof_front) | RBS1 (roof_left) | slope-front | 45.0 mm | beam end centre | beam centre |
| F27-1 | RBH1 (roof_front) | RBS2 (roof_right) | slope-front | 45.0 mm | beam end centre | beam centre |
| F28-1 | RBH2 (roof_back) | RBS1 (roof_left) | slope-rear | 45.0 mm | beam end centre | beam centre |
| F29-1 | RBH2 (roof_back) | RBS2 (roof_right) | slope-rear | 45.0 mm | beam end centre | beam centre |
| F30-1 | RBS1 (roof_left) | RBC1 (roof_middle) | slope-middle | 45.0 mm | beam end centre | beam centre |
| F31-1 | RBS2 (roof_right) | RBC1 (roof_middle) | slope-middle | 45.0 mm | beam end centre | beam centre |
| F32-1 | FBB1 (floor_back_support) | FBS2 (floor_right_support) | top | 45.0 mm | beam end centre | beam centre |
| F33-1 | FBB1 (floor_back_support) | FBS1 (floor_left_support) | top | 45.0 mm | beam end centre | beam centre |
| F34-1 | SBH2 (seat_rail_2) | SBS1 (seat_support_left) | underside | 45.0 mm | beam end centre | beam centre |
| F35-1 | SBH2 (seat_rail_2) | SBS2 (seat_support_right) | underside | 45.0 mm | beam end centre | beam centre |
| F36-1 | SBH1 (seat_rail_1) | SBS1 (seat_support_left) | underside | 45.0 mm | beam end centre | beam centre |
| F37-1 | SBH1 (seat_rail_1) | SBS2 (seat_support_right) | underside | 45.0 mm | beam end centre | beam centre |
| F38-1 | SBH1 (seat_rail_1) | SBS3 (seat_support_outer_left) | underside | 45.0 mm | beam end centre | beam centre |
| F39-1 | SBH2 (seat_rail_2) | SBS3 (seat_support_outer_left) | underside | 45.0 mm | beam end centre | beam centre |
| F40-1 | SBH1 (seat_rail_1) | SBS4 (seat_support_outer_right) | underside | 45.0 mm | beam end centre | beam centre |
| F41-1 | SBH2 (seat_rail_2) | SBS4 (seat_support_outer_right) | underside | 45.0 mm | beam end centre | beam centre |
| F42-1 | left_wall (left_wall) | SBB1 (seat_box_support_front) | outside-side | 45.0 mm | beam end centre | beam centre |
| F43-1 | right_wall (right_wall) | SBB1 (seat_box_support_front) | outside-side | 45.0 mm | beam end centre | beam centre |
| F44-1 | left_wall (left_wall) | SBB2 (seat_box_support_rear) | outside-side | 45.0 mm | beam end centre | beam centre |
| F45-1 | right_wall (right_wall) | SBB2 (seat_box_support_rear) | outside-side | 45.0 mm | beam end centre | beam centre |
| F46-1 | left_wall (left_wall) | SBF1 (seat_floor_support) | outside-side | 45.0 mm | beam end centre | beam centre |
| F47-1 | right_wall (right_wall) | SBF1 (seat_floor_support) | outside-side | 45.0 mm | beam end centre | beam centre |
| F48-1 | DBV1 (door_left) | DBH1 (door_bottom) | door | 45.0 mm | 122.5 mm | 12.0 mm |
| F48-2 | DBV1 (door_left) | DBH1 (door_bottom) | door | 45.0 mm | 122.5 mm | 33.0 mm |
| F49-1 | DBV2 (door_right) | DBH1 (door_bottom) | door | 45.0 mm | 122.5 mm | 12.0 mm |
| F49-2 | DBV2 (door_right) | DBH1 (door_bottom) | door | 45.0 mm | 122.5 mm | 33.0 mm |
| F50-1 | DBV1 (door_left) | DBH2 (door_top) | door | 45.0 mm | 1127.5 mm | 12.0 mm |
| F50-2 | DBV1 (door_left) | DBH2 (door_top) | door | 45.0 mm | 1127.5 mm | 33.0 mm |
| F51-1 | DBV2 (door_right) | DBH2 (door_top) | door | 45.0 mm | 1127.5 mm | 12.0 mm |
| F51-2 | DBV2 (door_right) | DBH2 (door_top) | door | 45.0 mm | 1127.5 mm | 33.0 mm |
| F52-1 | DBV1 (door_left) | DBD1 (door_brace) | door | 45.0 mm | 1105.0 mm | 12.0 mm |
| F52-2 | DBV1 (door_left) | DBD1 (door_brace) | door | 45.0 mm | 1105.0 mm | 33.0 mm |
| F53-1 | DBV2 (door_right) | DBD1 (door_brace) | door | 45.0 mm | 145.0 mm | 12.0 mm |
| F53-2 | DBV2 (door_right) | DBD1 (door_brace) | door | 45.0 mm | 145.0 mm | 33.0 mm |

## Workshop notes

- Fit every diagonal corner to corner and trim its ends flush with the receiving member faces.
- Drive the 6 × 120 mm diagonal screws from the vertical members at a slight angle.
- Measure the finished frame before final fastening and use the measured angle for the scribe.
- Do not use the cladding fastener pattern for beam screws.
- Measure the finished frame side and roof pitch with a bevel gauge; record the actual value before final screws.

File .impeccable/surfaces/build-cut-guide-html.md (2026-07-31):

---
version: 1
slug: "build-cut-guide-html"
primary_target: "build/cut-guide.html"
related_targets: ["src/dass/build_guide.py","web/render/materials.mjs"]
---

Scope: `build/cut-guide.html` and `build/how-its-going.html`, an offline screen
and print drawing set plus its companion field-notes page, generated by
`src/dass/build_guide.py`.

Mode: Operate first, Read second. The owner-builder must cut, mark, stack, and
assemble without returning to the CAD model.

Audience and task: one workshop user working in millimetres with 45 x 45 x 4200
framing, 120 x 23 x 4500 raspont, and a 2.8 mm kerf.

Proof and content: model-derived part dimensions, exact stock-count proof,
unique part codes, stock diagrams, and numbered unit drawings. The header
contains the renders and model. Each cladded unit shows its on-frame trim and
assembly steps. Sheets run A-200 timber, A-300 raspont, and A-400 units. The
companion page carries supplied workshop photos in build order, beginning with
the saw setup for beam cuts.

Direction: the Swedish construction drawing set that `docs/original-drawing/drawing-sides.png` comes
from, pinned by the user. White sheets on a grey ground, Input Mono at one
weight, four black line weights, red for part codes, blue for dimensions,
hatching for material the section plane cuts. Every figure is a numbered
drawing captioned beneath it; the title block appears once, on the masthead.
The memorable moment is the single-stop 1175 mm batch. The side fields are
fixed before their gang cut, terminal trim, and 45 mm notch.

Each number is written once in a table and once on the drawing it belongs to.
There is no part register: the stock bars carry the codes in cut order, the unit
drawings carry them on the geometry, and the model names any piece on click.

The model viewer opens line-shaded to match the sheets, with a TEXTURED toggle
that lazily loads the real timber. Both finishes run the same pipeline as the
photoreal renderer, shared through `web/render/materials.mjs`.

Constraints: every detail survives black-and-white printing; no required
information is hover-only; individual stock bars and wide tables may scroll
sideways but the document never does, at any width. The field-notes page keeps
the same drawing-set layout, omits the masthead metadata table, and serves
responsive optimized copies of its photos.

Unresolved: roof relief notches are deliberately scribed from the real completed
roof unit during dry fit instead of factory-cut from nominal CAD dimensions.

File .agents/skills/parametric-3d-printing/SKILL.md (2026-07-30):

---
name: parametric-3d-printing
description: "Use this skill when the user wants to design a 3D-printable physical object they intend to manufacture. Triggers: any mention of '3D print', 'STL', 'parametric model', 'Gridfinity', 'enclosure', 'bracket', 'mount', 'case', 'housing', 'CadQuery', 'OpenSCAD', or a specific FDM printer (Bambu Lab, Prusa, Ender); questions about print-friendly design, snap-fits, tolerances, or wall thickness; and requests for functional parts like Arduino enclosures, cable organizers, wall mounts, adapters, or mechanical components. Also fires when the user describes a real physical object to make, provided the goal is to manufacture it. Do NOT use for: 3D rendering, animation, game assets, digital-only art, photogrammetry, sculpting, editing an existing STL file the user already has, or any 3D work that is not heading toward a printer."
---

# Parametric 3D Printing with CadQuery

## Overview

This skill generates parametric 3D models using **CadQuery** (Python) and exports them as STL files ready for slicing. CadQuery is preferred because it installs via pip, has a Pythonic API, and handles complex geometry (fillets, chamfers, booleans, assemblies) better than alternatives.

## Setup

```bash
# CadQuery requires Python 3.10-3.12 (OCC kernel lacks 3.13+ wheels)
python3.12 -m venv .venv && source .venv/bin/activate

# Install CadQuery and preview dependencies
pip install cadquery trimesh pyrender Pillow numpy lxml
```

CadQuery uses the OpenCASCADE kernel under the hood. trimesh, pyrender, Pillow, and numpy are used for the preview-analyze-iterate loop; lxml is required by the 3MF writer (`stl_to_3mf.py`). No display server is needed; everything renders headlessly via pyrender's offscreen backend.

**If CadQuery fails to install** (OCC kernel build errors), try:
```bash
# Option 1: Use conda (CadQuery's officially recommended method)
conda install -c cadquery -c conda-forge cadquery

# Option 2: Use the pre-built wheels
pip install cadquery --find-links https://github.com/CadQuery/CadQuery/releases
```

## Real-World Dimension Research

When designing objects that interface with real products (phones, chargers, PCBs, connectors, etc.), **use web search to find accurate dimensions** before writing any geometry code. Don't guess or use approximate values. Even 1-2mm off can make a part unusable.

**What to research:**
- Connector/port dimensions (USB-C: 8.4 x 2.6mm opening, Lightning, barrel jacks)
- Device dimensions (phone width/thickness, PCB footprints, charger puck diameters)
- Mounting hole patterns and screw sizes (M2.5, M3, etc.)
- Standard component specs (MagSafe puck: 56mm diameter, 5.6mm thick)
- Cable bend radii and strain relief requirements

**How to use it:**
1. Search for "[product] dimensions mm" or "[component] datasheet"
2. Cross-reference at least 2 sources when precision matters
3. Add the sourced dimensions as comments in the PARAMETERS section:
   ```python
   # MagSafe puck dimensions (source: Apple spec + iFixit teardown)
   puck_diameter = 56.0    # mm
   puck_thickness = 5.6    # mm
   ```
4. When in doubt, add 0.3-0.5mm clearance to external dimensions

This is especially important for: phone cases/stands, charger mounts, PCB enclosures, cable management, adapter fittings, and anything that clips onto or wraps around an existing product.

## Core Workflow

1. **Gather requirements** (see Requirements Gathering below)
2. **Research dimensions** of any real-world products involved (see above)
3. **Phase 1, Base shape**: Build outer shell, preview, get user feedback
4. **Phase 2, Features**: Add functional details, preview, get user feedback
5. **Phase 3, Final delivery**: Fillets, cleanup, final preview + STL + print recommendations
6. **Offer parameter tweaks** after delivery

This is a **collaborative, show-as-you-go** process. Do NOT disappear and come back with a finished model. Show the user your progress at each phase and incorporate their feedback before moving on.

## Requirements Gathering

Before writing any code, walk through these topics with the user **conversationally**. Don't dump all questions at once. Ask the most important ones first, then follow up based on answers. Use reasonable defaults when the user doesn't specify.

**What is it?**
Object type, purpose, what it holds/protects/attaches to. Get a clear mental model of the object before anything else.

**Critical dimensions**
Must-fit measurements, like PCB size, phone width, screw spacing, diameter of the thing it wraps around, etc. These are non-negotiable and drive everything else.

**Mounting & attachment**
How does it connect to things? Screws (what size?), snap-fit, adhesive tape, magnets, freestanding on a desk? This affects wall thickness, boss placement, and overall structure.

**Printer & material**
What printer do they have? (Bambu, Prusa, Ender, etc.) Nozzle size? Material (PLA, PETG, TPU)? This directly affects tolerances, minimum feature sizes, and design constraints. Defaults: 0.4mm nozzle, PLA, 0.2mm layer height.

**Functional needs**
Ventilation/airflow, water resistance, cable routing, access panels, visibility windows, stacking, weight limits. Ask only what's relevant to the object.

**Aesthetic preferences**
Rounded vs sharp edges, minimal vs industrial look, color considerations (affects visibility of layer lines). Ask briefly. Most users care more about function than form.

Start with the first two (what + dimensions), then ask about mounting and material if relevant. Only ask about aesthetics if the user seems to care or if it affects structural choices.

## Progressive Preview Workflow

Build the model in phases. At each phase, export an STL, render a preview, self-review it, then **show it to the user and ask for feedback** before proceeding. This catches problems early and keeps the user involved.

### Preview recipe (use at every phase)

**One-shot (run script + render + parse result as JSON):**
```bash
python3 run_cadquery_model.py model.py --preview --strict
```
This executes `model.py`, finds the STL it wrote, renders the multi-view preview, and emits a JSON result with `success`, `stdout`, `stderr`, `stl`, `preview`, and `watertight`. With `--strict`, a non-watertight mesh is a hard failure. Use this as the default loop: if `success` is false, read the `stderr` field to fix the CadQuery script, then re-run.

**Rendering only (when the STL already exists):**
```bash
python3 preview.py model.stl preview.png --views multi
```

Then view the preview image, self-review it against the checklist in `design-review.md`, and fix any issues you spot **before** showing it to the user.

---

### Phase 1: Base Shape

Build the basic outer form: overall dimensions, shell/walls, bottom plate. No cutouts, no fillets, no details yet.

1. Write the script with parameters and basic geometry
2. Export STL and render preview
3. Self-review: Does the shape and size look right? Is the bottom flat for printing?
4. **Show the preview to the user**: "Here's the basic shape. Does this look right before I add details?" Include key dimensions.
5. Wait for feedback. If the user wants changes, iterate here before moving on.

### Phase 2: Features

Add functional details: holes, cutouts, mounting bosses, cable slots, ventilation, snap-fits, internal structures.

1. Add features to the script
2. Export STL and render preview
3. Self-review: Are all features visible? Do booleans look clean? Are holes in the right positions?
4. **Show the preview to the user**: "I've added [list features]. Anything to change before I finalize?"
5. Wait for feedback. Iterate if needed.

### Phase 3: Final Delivery

Apply finishing touches: fillets, chamfers, edge cleanup. Do a full printability review.

1. Add fillets/chamfers (largest radius first, apply after shell)
2. Export final STL and render preview
3. **Full self-review** using the complete checklist from `design-review.md`: visual inspection, dimensional verification, printability analysis
4. Fix any issues found, re-export if needed
5. **Deliver to the user**: final STL + preview image + print recommendations (orientation, supports, infill, material notes)

---

**Important:** Do NOT skip phases or combine them unless the model is very simple (e.g., a flat bracket with two holes). For anything with enclosed geometry, multiple features, or tight tolerances, follow all three phases.

Read `design-review.md` for the full visual inspection checklist, dimensional verification code, and printability analysis helpers.

### Print Recommendations (final delivery)

When you deliver the final STL, always include a one-line slicer recipe plus a short rationale. Bambu Studio, PrusaSlicer, and OrcaSlicer already set sensible defaults from their filament + process presets, so **do not restate every slicer option**. Only tell the user what matters for *this* model: material, layer height, walls, infill, supports, and orientation. Tweak from the baseline below only when the model needs it.

**Baseline recipe (0.4mm nozzle, typical FDM):**
> PLA, 0.2mm layer, 2 walls, 15% gyroid infill, no supports, orientation: flat side on bed.

**When to deviate from the baseline:**
- **Load-bearing brackets / hooks / hinges**: bump infill to 25-40%, 3-4 walls, consider PETG over PLA for toughness.
- **Thin decorative walls or vases**: 0 infill, vase mode or 1 wall.
- **Tall narrow parts**: add a brim for bed adhesion.
- **Flexible parts (gaskets, grips)**: TPU 95A, 0.2mm layer, slower speed, no supports.
- **Functional overhangs the geometry can't avoid**: tree supports, or call them out so the user knows.
- **Outdoor / hot environments**: PETG or ASA, not PLA.
- **Food / skin contact**: call out that FDM parts are not food-safe and recommend a food-safe coating.

**Format at delivery time:**
```
Print settings: PLA, 0.2mm layer, 2 walls, 15% gyroid infill, no supports.
Orientation: place flat back side on the bed (front face up).
Why: the case has no overhangs above 45°, and 15% infill is plenty for a
TPU-adjacent protective shell.
```

Keep it to ~3 lines. Never dump every slicer setting; the slicer already knows.

## Script Template

ALWAYS structure scripts like this:

```python
import cadquery as cq

# ============================================================
# PARAMETERS - Edit these to customize the model
# ============================================================
# Overall dimensions
width = 60.0        # mm - outer width
depth = 40.0        # mm - outer depth  
height = 25.0       # mm - outer height

# Wall and structural
wall = 2.0          # mm - wall thickness (min 1.2 for FDM)
corner_r = 2.0      # mm - corner fillet radius

# Tolerances
fit_clearance = 0.3 # mm - clearance for press-fit (adjust per printer)

# ============================================================
# MODEL
# ============================================================
result = (
    cq.Workplane("XY")
    .box(width, depth, height, centered=(True, True, False))
    # ... build geometry using parameters above (bottom at Z=0)
)

# ============================================================
# EXPORT
# ============================================================
# Use tolerance=0.01, angularTolerance=0.1 for consistent tessellation
# across models. Defaults give coarser, wildly variable STL sizes.
cq.exporters.export(result, "output.stl",
                    tolerance=0.01, angularTolerance=0.1)
print(f"Exported: {width}x{depth}x{height}mm")
```

## Key Rules

### Parameters First
- ALL dimensions go in the PARAMETERS section at the top
- Use descriptive names: `screw_hole_d`, not `d1`
- Add units in comments (always mm)
- Group related parameters with blank lines and section comments

### Print-Friendly Defaults
Key FDM design defaults:

| Property | Minimum | Recommended |
|---|---|---|
| Wall thickness | 1.2mm | 2.0mm |
| Layer height | 0.08mm | 0.2mm |
| Hole clearance | 0.2mm | 0.3mm |
| Press-fit interference | 0.1mm | 0.15mm |
| Min feature size | 0.4mm (nozzle) | 0.8mm |
| Fillet radius (bottom) | 0.5mm | 1.0mm |
| Bridge span | - | < 20mm unsupported |
| Overhang angle | - | < 45 degrees from vertical |

**Material-specific adjustments:** TPU needs larger clearances (~0.5mm) due to flex. PETG is stickier, so add +0.1mm to fit clearances. ABS shrinks ~0.5-0.7%, so scale critical dimensions up slightly. When in doubt, print a small test piece first.

### Orientation Awareness
- Design with print orientation in mind
- Flat bottom surfaces print best
- Avoid supports when possible by designing around overhangs
- Add chamfers to bottom edges instead of fillets (fillets need supports)
- Comment the intended print orientation in the script

### CadQuery Patterns

Common patterns to know:

**Hollow enclosure (boolean subtraction, preferred):**
```python
outer = (
    cq.Workplane("XY")
    .box(width, depth, height, centered=(True, True, False))
    .edges("|Z").fillet(corner_r)
)
inner = (
    cq.Workplane("XY")
    .workplane(offset=floor_t)
    .box(width - 2*wall, depth - 2*wall, height, centered=(True, True, False))
    .edges("|Z").fillet(max(0.1, corner_r - wall))
)
result = outer.cut(inner)
```

**Screw boss:**
```python
.pushPoints([(x, y)])
.circle(boss_od / 2).extrude(boss_h)
.pushPoints([(x, y)])
.hole(screw_d + fit_clearance)
```

**Snap-fit clip:**
```python
# Cantilever beam with overhang hook
.workplane(offset=wall)
.moveTo(x, y).rect(clip_w, clip_l).extrude(clip_h)
# Add hook at tip with a small overhang (< 45 deg)
```

**Ventilation grid:**
```python
.pushPoints(vent_positions)
.slot2D(slot_l, slot_w).cutThruAll()
```

Other patterns: mounting brackets, cable routing channels, text/labels (`.text()`), multi-part assemblies with alignment pins.

### Common Pitfalls

- **Hollowing: prefer boolean subtraction over `.shell()`**. `.shell()` is fragile. It fails on tapered bodies, lofted shapes, unions of multiple primitives, and anything with many fillets. The reliable pattern is:
  ```python
  outer = cq.Workplane("XY").box(w, d, h, centered=(True, True, False)).edges("|Z").fillet(corner_r)
  inner = (
      cq.Workplane("XY")
      .workplane(offset=floor_t)
      .box(w - 2*wall, d - 2*wall, h, centered=(True, True, False))
      .edges("|Z").fillet(max(0.1, corner_r - wall))
  )
  result = outer.cut(inner)
  ```
  Only reach for `.shell()` when the body is a single simple primitive (one `.box()` or `.cylinder()`) with a uniform wall thickness on all sides. If in doubt, use boolean subtraction.
- **Build order: fillet → cut, not cut → fillet**. Apply fillets while the geometry is still a clean primitive. Once you have cut holes/slots/pockets into a body, filleting the resulting edges often fails or produces bad geometry. Same rule for chamfers.
- **Fillet failures**: Apply fillets from largest to smallest radius. **Do not wrap fillets in `try/except` to silently shrink the radius.** A fillet failure means the geometry or the radius is wrong; find the root cause (too-large radius, wall thinner than radius, adjacent faces that the fillet would degenerate) and fix that.
- **Zero-thickness geometry**: Ensure boolean operations don't create infinitely thin walls. Add a small epsilon (0.01mm) when cutting bodies that are meant to pass just through a surface.
- **Coordinate system**: CadQuery centers geometry at origin by default. Use `centered=(True, True, False)` on `.box()` to place the bottom at Z=0 so `.faces("<Z")` is always the print bed.
- **Hole direction**: `.hole()` cuts through the entire part by default. Use `.cboreHole()` or `.cskHole()` for counterbore/countersink.
- **Taper direction**: In `.extrude(taper=angle)`, a **positive** taper angle narrows the shape (draft inward), **negative** flares it outward. This is opposite to what many people expect.
- **Loft is fragile**: `.loft()` fails on many cross-section combinations. Prefer `.extrude(taper=angle)` when transitioning between a shape and a scaled version of itself. Only use `.loft()` when you need to transition between genuinely different profiles (e.g., circle to rectangle).
- **Export errors / non-watertight STL**: If export fails or the preview reports a non-watertight mesh, the geometry is invalid (usually self-intersecting booleans or zero-thickness faces). Fix the cause, don't paper over it. Run `python3 preview.py model.stl --strict` to fail loudly on non-watertight output.

## Export

```python
# STL (for slicing) - always set tolerance + angularTolerance for
# consistent tessellation. Defaults produce variable file sizes and
# over-tessellated glyphs on text features.
cq.exporters.export(result, "model.stl",
                    tolerance=0.01, angularTolerance=0.1)

# STEP (for further CAD editing)
cq.exporters.export(result, "model.step")
```

Always export STL for printing. Optionally export STEP if the user might want to edit in Fusion 360 or similar.

## Multi-Part Models

For models with multiple parts (e.g., enclosure + lid):

```python
# Export each part separately
cq.exporters.export(body, "enclosure_body.stl")
cq.exporters.export(lid, "enclosure_lid.stl")
```

Name files descriptively so the user knows which part is which.

## Gridfinity Bins

For any Gridfinity request (bins, inserts, cradles for the 42mm modular grid system), **use the bundled `gridfinity.py` module; never hand-roll the base profile**. The module is tested, spec-compatible (base profile, stacking lip, 6x2mm magnet bores, M3 screw holes on the 26mm square), and validates parameters with actionable errors.

**Workflow:**
1. Copy `gridfinity.py` from this skill's directory next to the model script (it is a vendored module; generated scripts must stay runnable standalone).
2. Build with the `GridfinityBin` API:

```python
import cadquery as cq
from gridfinity import GridfinityBin

bin = GridfinityBin(grid_x=3, grid_y=2, height_units=3,
                    stacking_lip=True, magnets=False)
bin.add_pocket(length=88.6, width=72.6, corner_r=(12.0, 1.0))  # cradle
# or: bin.add_compartments(cols=3, rows=2, scoop_r=6, label_tab=True)
# or: bin.add_polygon_pocket(points, depth=15, clearance=0.3)
# or: bin.add_cylinder_pocket(diameter=22, center=(42, 27),  # finger well; overlapping pockets merge
#         tilt=35, tilt_dir=(-1, 0), round_bottom=True)      # smooth angled thumb scoop
# or: bin.add_finger_notch(side="+Y", width=20, offset=40)   # offset slides it along the wall
result = bin.build()
cq.exporters.export(result, "my_bin.stl", tolerance=0.01, angularTolerance=0.1)
print(bin.summary())
```

**Cheat sheet:**
- Spec constants: grid pitch 42mm, height unit 7mm. Every derived number (footprint, lip height, floor Z, usable cavity depth) is exposed on the builder: `bin.outer_w`, `bin.outer_d`, `bin.total_h`, `bin.floor_z`, `bin.max_depth`, and `bin.summary()` prints them all. Read those instead of recomputing.
- Sizing an object pocket: add 0.3mm per side fit clearance, plus ~1mm per side if the object must drop in and out easily.
- Pocket matching a real object's shape: `outline_from_scan.py` extracts the max cross-section outline from an STL scan of the object (align, scale to spec dims, slice, union), ready for `add_polygon_pocket`.
- Height choice: whatever holds the contents; the contents may protrude above the rim (see `examples/gridfinity_d110_bin.py`).
- `magnets=True` needs a magnetic baseplate; skip it for drawer bins.

The builder raises `GridfinityError` with a specific message when a pocket is too big, a wall too thin, or the floor too shallow for screws (a few checks fire in the `add_*` calls, the rest in `build()`). Fix the parameters; do not bypass the validation.

If the user asks for something the module does not cover (baseplates, odd lips), fall back to custom geometry but keep the spec constants from `gridfinity.py` as the source of truth. When delivering a release, ship `gridfinity.py` alongside the model script.

## Parameter Adjustment Offer

After delivering the final model, **always present the key parameters as a summary table** and offer to tweak them. This lets the user fine-tune without re-explaining the whole design.

Example:
```
Here's your final model! Current parameters:

| Parameter       | Value  |
|----------------|--------|
| Width          | 90 mm  |
| Depth          | 65 mm  |
| Height         | 30 mm  |
| Wall thickness | 4 mm   |
| Cable slot     | 18 mm  |
| Corner radius  | 3 mm   |
| Fit clearance  | 0.3 mm |

Want me to adjust anything? Just say e.g. "make it 5mm taller" or "wider cable slot."
```

Only include parameters the user would plausibly want to change. Skip internal constants like `eps` or `nozzle_d`. Group them logically (dimensions first, then structural, then tolerances).

## Output Checklist

Before delivering a model, verify:
- [ ] All dimensions are parameterized (no magic numbers in geometry code)
- [ ] Wall thickness >= 1.2mm
- [ ] Designed for printability (minimal overhangs/supports)
- [ ] Print orientation noted in comments
- [ ] STL exported and file size is reasonable (not 0 bytes)
- [ ] Clear parameter names with units
- [ ] Script runs without errors
- [ ] **Multi-view preview generated and visually inspected**
- [ ] **Preview shows correct shape, features, and proportions**
- [ ] **Bounding box dimensions match requirements**
- [ ] Both STL and preview PNG delivered to user

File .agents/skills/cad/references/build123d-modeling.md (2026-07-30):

# build123d modeling patterns

Read this file when writing or repairing build123d Python source.

## Modeling objective

Create a valid STEP-ready BREP model, not a visual mesh. Prefer closed solids, explicit labels, and stable parametric dimensions. Define `gen_step()` returning the STEP-ready shape or labeled compound; the CLI owns output paths (see `step-generation.md`).

## Design strategy

Decide how the part is constructed before writing geometry code:

- **Choose the construction that makes the spec's dimensions direct parameters.** Profile-driven shapes get one closed sketch plus `extrude`/`revolve`/`sweep`/`loft`; block-and-feature parts get a base solid plus subtractive features. Prefer whichever construction lets the user's controlling dimensions appear as named parameters instead of derived values.
- **Decide part vs assembly before modeling.** Bodies that are separately manufactured, purchased, or movable belong in a labeled assembly (see `positioning.md`); monolithic manufacturing intent gets a single fused solid. Avoid unlabeled compounds of solids — multi-body output without occurrence labels loses traceability in inspection and viewer review.
- **Pick the origin and orientation from the functional datum before sculpting.** Model on the mating interface, mounting plane, or symmetry axis; see `positioning.md` for part-type origin defaults.
- **Order operations so fragile steps come last and failures localize.** Base solid → major additions → subtractive features → shell → through-wall holes → fillets and chamfers last. Fillets are the most failure-prone operation and every boolean invalidates selectors, so postpone them. Structure the source so each feature is a named step — a per-feature function or a distinct intermediate variable — so a failed operation points at exactly one feature and a parameter change touches one obvious place.
- **Overshoot boolean tools.** Extend cutting tools past the faces they enter and exit; for through-cuts, go roughly 1 mm beyond both faces. Coincident or coplanar tool/target faces are a classic kernel failure. Cut repeated or patterned features in one combined operation.
- **Sanity-check proportions before generating.** Compare the expected bounding box against the real-world object, wall thickness against overall size, and feature positions against edges and neighboring features. Order-of-magnitude and collision errors pass geometric validation but fail visual review.

## Topology stack

Think in this order:

```text
Vertex → Edge → Wire → Face → Shell → Solid → Compound
```

For assemblies, use these repo topology terms consistently:

- **Occurrence**: a placed node in the assembly tree. An occurrence has a parent, transform, path, and user-facing role such as `lid` or `m3_screw:front_left`.
- **Shape**: an exported geometry/body inside an occurrence. Shape rows own topology; faces and edges belong to a shape, and the shape belongs to an occurrence.
- **Face/edge**: selectable topology owned by a shape. Do not assume arbitrary faces or edges have persistent intent labels; inspect them by occurrence, shape, ordinal, surface/curve type, and measured geometry.

When inspecting topology, follow `assembly occurrence -> shape/body -> faces -> edges`. Every face/edge row should be traceable through both `occurrenceId` and `shapeId`.

For normal STEP output, return one of:

- a valid `Solid`
- a compound of valid solids
- a labeled assembly compound

Avoid returning loose wires, open faces, or construction surfaces unless the user explicitly requested them.

## Parameters first

Put meaningful dimensions in named variables:

```python
width = 80.0
depth = 50.0
thickness = 6.0
hole_diameter = 4.5
hole_offset_x = 30.0
hole_offset_y = 17.5
```

Avoid burying important numbers inside geometry calls.

## Coordinate system

Declare or comment the convention:

```text
Origin: center of primary part or chosen mating datum
XY: main base/sketch plane
+Z: up/extrusion direction
```

Use `Location`, `Plane`, and `Axis` intentionally. For positioning-sensitive tasks and source-level assembly relationships, read `positioning.md`.

## Builder contexts

Use the context that matches the geometry:

```python
with BuildLine() as path:
    ...

with BuildSketch() as profile:
    ...

with BuildPart() as part:
    ...
```

Typical flow:

```text
curves/paths → sketches/profiles → solids/features → labels → STEP
```

## Selection practices

Avoid fragile topology order when possible. Select by:

- axis or normal
- location or bounding position
- plane grouping
- feature intent
- stable construction plane
- inspected local selector ref for downstream validation

For source operations, prefer robust selectors such as top/bottom by axis or position rather than arbitrary list indexes.

## Assemblies and positioning

For assemblies, keep this file focused on BREP modeling patterns and labels. Use `positioning.md` as the single source of truth for:

- part-local coordinate conventions
- when to use `cadpy.assembly.AssemblyHelper`, build123d joints, or explicit `Location` transforms
- `connect_to()` behavior
- CLI `inspect align` as read-only selector-pair alignment validation
- frame, measure, and positioning report expectations

## Labels and assemblies

Label every exported part and assembly child with native build123d labels. Prefer concise intent labels through `cadpy.assembly` helpers:

```python
from cadpy.assembly import AssemblyHelper, label_shape

asm = AssemblyHelper("electronics_enclosure")
base = asm.add(make_base(), "base")
lid = asm.add(make_lid(), "lid")

boss = label_shape(Cylinder(radius=3.0, height=12.0), "m3_boss", "front_left")
```

Do not prefix labels with topology categories like assembly, component, feature, datum, mate, or hardware. The assembly tree and topology inspection already expose those structural categories. Use labels for the intent topology cannot reliably infer: role, placement, interface, repetition, or mating purpose. Feature labels survive STEP export best when the feature remains a labeled child shape in a `Compound`; boolean-subtracted or fused feature history should be represented by source parameters, named datums, and validation refs instead of assumed persistent feature labels.

Label for inspection:

- Label the root assembly.
- Label every exported part, subassembly/module, and repeated component occurrence.
- Use occurrence labels for assembly role and placement, especially repeated parts: `m3_screw:front_left`, `m3_screw:rear_right`.
- Use shape labels for retained exported geometry/body roles where useful.
- Use feature/datum labels only when that geometry remains exported as a child shape.
- Use named mate datums for source-level positioning intent, then validate the exported STEP topology and occurrence frames.

Occurrence and shape labels are exported through STEP names and surfaced in `STEP_topology` when available. The viewer uses occurrence labels for assembly/tree references and shape labels for shape references. Faces and edges inherit their context from `occurrenceId` and `shapeId`; do not promise persistent face/edge intent labels unless explicit tested support exists.

For repeated parts, keep occurrence labels, transforms, or joint connections explicit and inspect frames/positioning after generation.

## Common failure modes

- Fillet radius larger than local edge geometry.
- Open sketch profile produces invalid or missing face.
- Face selector changes after a boolean or fillet.
- Part origin is arbitrary and later alignment checks become ambiguous.
- Source-level joints are treated as if they were persistent STEP constraints rather than one-time source placement operations.
- Joint labels are missing, duplicated, or attached to the wrong local datum.
- `.connect_to()` fixes the wrong side of the relationship, moving the part intended to remain fixed.

Use `repair-loop.md` when generation or validation fails.

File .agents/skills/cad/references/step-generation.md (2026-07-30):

# STEP generation

Read this file when generating or regenerating STEP/STP artifacts from build123d Python source or from direct STEP/STP targets.

## Tool

The launcher lives in the CAD skill directory:

```bash
python scripts/step [--kind {part|assembly}] targets... [flags]
```

Use explicit target paths only; target paths resolve from the command cwd unless absolute. Do not rely on directory-wide generation.

Plain generated Python targets write sibling `.step` outputs. Use `-o`/`--output` only with one plain generated Python target, or use `SOURCE.py=OUTPUT.step` positional pairs for per-target custom outputs. Paired output paths resolve from the command cwd and are valid only for generated Python sources, not direct STEP/STP inputs. Do not put output paths in the `gen_step()` return value; the CLI owns output paths.

## Generated Python source

This is the default path when designing from scratch or modifying a generated model. Generated build123d sources define:

```python
def gen_step():
    ...
    return step_ready_shape_or_labeled_compound
```

Generated Python targets infer their kind from the source metadata and `gen_step()` return value; pass the source path directly:

```bash
python scripts/step path/to/part.py
python scripts/step path/to/part.py -o path/to/custom.step
python scripts/step path/to/a.py=out/a.step path/to/b.py=out/b.step
python scripts/step path/to/assembly.py
```

Passing a generated assembly `.step` directly treats it as imported native STEP and loses source-level assembly composition; pass the `.py` assembly source. For generated build123d assemblies, prefer `cadpy.assembly.AssemblyHelper` in the Python source so native labels, named mate frames, and source-level relationships are preserved before STEP export (see `positioning.md`).

## Direct STEP/STP imports

Use a direct STEP/STP target when no generator exists (imported or downloaded STEP) or the user explicitly identifies a STEP/STP file as the target. The GLB/topology artifacts are then generated from the STEP file itself:

```bash
python scripts/step --kind part path/to/imported.step
```

Direct targets support the same mesh sidecar flags as generator targets; read `supported-exports.md` for STL and 3MF sidecars.

## Viewer artifacts

Every `scripts/step` run also writes hidden adjacent GLB/topology artifacts as part of the normal build. They power CAD Viewer review, `$cad-viewer` workflows, and `scripts/inspect` refs, and are not optional in the STEP workflow.

## After generation

- Confirm the process succeeded and the STEP file exists and is non-empty.
- Run the baseline inspection and any spec-driven checks per `inspection-and-validation.md`:

```bash
python scripts/inspect refs path/to/model.step --facts --planes --positioning
```

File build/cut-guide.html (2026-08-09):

WORKING DRAWING

# Can AI build a toilet yet?

An experiment in re-drawing a technical drawing as an editable parametric CAD model with Claude and Codex.

Project

DASS

Issue

2026-07-30

Architect

@hannes.soderquist (https://www.instagram.com/hannes.soderquist/)

Code

@feelepxyz (https://x.com/feelepxyz)

Source

GitHub (https://github.com/feelepxyz/dass)

Units

Millimetres

Kerf

2.8 mm per cut

Sheets

A-200 to A-400



In situOpenClosed

The finished building rendered in the drawing-set palette

Loading the model…

Model Open Closed Finish Line Textured

Interactive line model. Drag to rotate, scroll or pinch to zoom, and click a piece to identify it.The finished building.

Sheet A-200

## Structural timber

### Material

Frame timber, 45 × 45 × 4 200 mm. Quantity: 9 lengths.

The 9 beam stock lengths below are named B01 to B09. Each cut diagram shows the marked beam pieces cut from that length.

Cut every piece at one stop setting before you change the stop. A batch that reaches the end of a stock length continues on the next length.

These sheets are exact only for this material size. One 2.8 mm kerf is used for every piece.

If your material ends are rough, shave a small amount off from each piece first.

B01 3 pieces

BWD11 315.9 mm

DBD11 315.9 mm

LSD11 203 mm

356.8 mm

B02 3 pieces

RSD11 203 mm

LSV11 150 mm

LSV21 150 mm

688.6 mm

B03 3 pieces

RSV11 150 mm

RSV21 150 mm

DBV11 050 mm

841.6 mm

B04 4 pieces

DBV21 050 mm

RBH1990 mm

RBH2990 mm

BWH1900 mm

258.8 mm

B05 4 pieces

BWH2900 mm

DBH1900 mm

DBH2900 mm

FBH1900 mm

588.8 mm

B06 4 pieces

RBC1900 mm

FBB1854 mm

SBB1854 mm

SBB2854 mm

726.8 mm

B07 5 pieces

SBF1854 mm

SBH1852 mm

SBH2852 mm

RBS1812.7 mm

RBS2812.7 mm

2.7 mm

B08 5 pieces

LSH1725 mm

LSH2725 mm

RSH1725 mm

RSH2725 mm

FBS1657 mm

629 mm

B09 5 pieces

FBS2657 mm

SBS1387 mm

SBS2387 mm

SBS3387 mm

SBS4387 mm

1 981 mm

Sheet A-300

## Råspont (matchboard/V-groove cladding)

### Material

Råspont (matchboard/V-groove cladding), 120 × 23 × 4 500 mm. Quantity: 12 lengths.

The 12 cladding stock lengths below are named P01 to P12. Each cut diagram shows the marked boards cut from that length.

The first 8 stock lengths release all twenty-three 1 175 blanks. Label the P01 to P03 remainders. Keep them for the final 397 pass. Fourteen side boards come next, then nine door boards, at one stop setting.

These sheets are exact only for this material size. One 2.8 mm kerf is used for every piece.

If your material ends are rough, shave a small amount off from each piece first.

P01 5 pieces

LSC11 175 mm

LSC21 175 mm

LSC31 175 mm

SFB1397 mm

SFB2397 mm

167 mm

P02 5 pieces

LSC41 175 mm

LSC51 175 mm

LSC61 175 mm

SFB3397 mm

SFB4397 mm

167 mm

P03 5 pieces

LSC71 175 mm

RSC11 175 mm

RSC21 175 mm

SFB5397 mm

SFB6397 mm

167 mm

P04 3 pieces

RSC31 175 mm

RSC41 175 mm

RSC51 175 mm

966.6 mm

P05 3 pieces

RSC61 175 mm

RSC71 175 mm

DCB11 175 mm

966.6 mm

P06 3 pieces

DCB21 175 mm

DCB31 175 mm

DCB41 175 mm

966.6 mm

P07 3 pieces

DCB51 175 mm

DCB61 175 mm

DCB71 175 mm

966.6 mm

P08 4 pieces

DCB81 175 mm

DCB91 175 mm

BWC11 050 mm

BWC21 050 mm

38.8 mm

P09 4 pieces

BWC31 050 mm

BWC41 050 mm

BWC51 050 mm

BWC61 050 mm

288.8 mm

P10 5 pieces

BWC71 050 mm

BWC81 050 mm

STB1852 mm

STB2852 mm

SFB7397 mm

285 mm

P11 6 pieces

STB3852 mm

STB4852 mm

STB5852 mm

FCB1747 mm

FCB2747 mm

SFB8397 mm

36.2 mm

P12 6 pieces

FCB3747 mm

FCB4747 mm

FCB5747 mm

FCB6747 mm

FCB7747 mm

FCB8747 mm

1.2 mm

Gaps between boards change the joined width. Fix each board to its unit frame before you mark any final edge. Use the frame edge to set the circular-saw guide. Cut only after the boards are fixed. Sheet A-400 shows each estimated overhang and cut line.

Sheet A-400

## Unit drawings and assembly

Each unit opens with its general arrangement, dimensioned and coded off the model, then builds through its own numbered steps. A step draws one operation: work already done ghosts back, work this step touches goes solid, and the band under the drawing names the operation before the caption is read.

Black screw paths are measured 120 mm screws: each starts on the source beam and finishes in the centre of the receiving section. Diagonal paths follow the diagonal beam from its mitred end.

### Assembly hardware

Use these fasteners for the timber assembly.

Use | Fastener
Frame beams and braces | 6 × 120 mm sunk wood screws
Beam-to-beam support joints, for example floor supports | 6 × 90 mm sunk wood screws
Råspont (matchboard/V-groove cladding) to beams | 2.8 × 60 mm nails or 6 × 60 mm sunk wood screws

Stack A

### Roof unit

0 / 3

1. 1Lay the five roof beamsA-401.1
  Done
2. 2Screw the frame cornersA-401.2Match the frame diagonals before you drive a screw.
  Done
3. 3Centre the metal sheetA-401.3
  Done

Stack B

### Door unit

0 / 5

FrameCladding

DOOR UNITA-402 · FRONT ELEVATIONseen from outside the door · hatched edge is the estimated on-frame trim

1. 1Build the frame and fit DBD1A-402.1
  Done
2. 2Screw the door frameA-402.2Match the frame diagonals before you drive a screw.
  Done
3. 3Fix DCB1 to DCB9 on the inside faceA-402.3
  Done
4. 4Trim the right overhangA-402.4
  Done
5. 5Cut the two top reliefsA-402.5
  Done

Stack C

### Left side

0 / 7

FrameCladding

LEFT SIDE UNITA-403 · LEFT ELEVATIONfront edge to the right · 100 fall over 770 · 45 × 45 bottom-front notch

1. 1Build the side frameA-403.1
  Done
2. 2Screw the side frameA-403.2Match the frame diagonals before you drive a screw.
  Done
3. 3Fix LSC1 to LSC7, front to rearA-403.3
  Done
4. 4Mark the slope at front and rearA-403.4
  Done
5. 5One gang cut along the markA-403.5
  Done
6. 6Trim the rear overhangA-403.6
  Done
7. 7Cut the bottom-front notchA-403.7
  Done

Stack D

### Right side

0 / 7

FrameCladding

RIGHT SIDE UNITA-404 · RIGHT ELEVATIONfront edge to the left · 100 fall over 770 · 45 × 45 bottom-front notch

1. 1Build the side frameA-404.1
  Done
2. 2Screw the side frameA-404.2Match the frame diagonals before you drive a screw.
  Done
3. 3Fix RSC1 to RSC7, front to rearA-404.3
  Done
4. 4Mark the slope at front and rearA-404.4
  Done
5. 5One gang cut along the markA-404.5
  Done
6. 6Trim the rear overhangA-404.6
  Done
7. 7Cut the bottom-front notchA-404.7
  Done

Stack E

### Back unit

0 / 5

FrameCladding

1. 1Build the bare back frameA-405.1Hold it square while you clad it. Nothing screws it until the posts do.
  Done
2. 2Fix BWC1 to BWC8 to the landing marksA-405.2Clad and trim the back flat. Fitted first, the side skins foul this overhang.
  Done
3. 3Trim the right overhangA-405.3
  Done
4. 4Set it between the two side unitsA-405.4
  Done
5. 5Screw the rear posts into BWH1 and BWH2A-405.5
  Done

Stack F

### Shell joint

0 / 2

1. 1Fit FBB1, FBS1, FBS2 and FBH1A-406.1
  Done
2. 2Screw all four beams to the shellA-406.2
  Done

Stack G

### Floor deck

0 / 2

1. 1Trim the right overhangA-407.1
  Done
2. 2Fix FCB1 to FCB8 to the bearersA-407.2
  Done

Stack H

### Seat box

0 / 5

FrameCladding

1. 1Build the removable seat boxA-408.1
  Done
2. 2Screw the box frameA-408.2Match the frame diagonals before you drive a screw.
  Done
3. 3Fix STB1 to STB5 across the topA-408.3
  Done
4. 4Trim the front overhangA-408.4
  Done
5. 5Cut the seat openingA-408.5
  Done

Stack I

### Seat box supports

0 / 3

Right sideLeft side

1. 1Set both beam tops above the deckA-409.1
  Done
2. 2Drive one screw from each sideA-409.2
  Done
3. 3Lower the box onto SBB1 and SBB2A-409.3
  Done

Stack J

### Seat front cladding

0 / 3

1. 1Lay SFB1 to SFB8 in orderA-410.1
  Done
2. 2Trim the field to the opening widthA-410.2
  Done
3. 3Screw every board to SBF1 and SBB1A-410.3
  Done

The checks are saved in this browser. Print removes the controls and keeps every code and dimension.

Clear all checks

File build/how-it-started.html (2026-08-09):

PROJECT NOTES

# Can AI build a toilet yet?

Project notes 01

## How it started

I wanted to build a compact outdoor toilet for caravan living in the woods. My friend Hannes Söderquist (https://www.instagram.com/hannes.soderquist/) had drawings for one, but the original design uses 50 × 50 mm beams and 120 × 25 mm cladding, sizes that did not match the stock in the local shop.

Original side drawing

Original side drawing

I first asked Codex to copy the technical drawing into an editable, programmable parametric CAD model using CadQuery and related tools. All CAD edits were done from prompts only. The first generated versions had several geometry problems and did not match the source design, so I had to do a lot of nudging to keep material from clipping into other parts and creating impossible cuts.

Early open-model validation

Early open-model validation

Seat-section comparison

Seat-section comparison

Door-front comparison

Door-front comparison

I then had Codex and Claude add specifications from the technical drawing and make comparison cut lists from the dimensions it specified. We kept going until the editable model matched the drawing. This was less like asking for a finished model and more like correcting a transcription until the geometry, dimensions, and cut schedules agreed.

One cool side-effect of the CAD model was that Codex could run some basic structural analysis on the original drawing. It found that the floor boards did not have enough support, so we added support beams.

Once the model matched the drawing, I asked it to change the beam and cladding dimensions to the material available in the local shop: 45 × 45 mm beams and 120 × 23 mm Råspont (matchboard/V-groove cladding). I checked the shop supply and had it create detailed cut lists from the available stock. I also changed the shape slightly so that each interleaved cladding board has at least 10 mm of trim. The board ends therefore do not leave a lip outside the frame.

From there, the cut schedules follow the material lengths in the shop. The optimizer groups equal-length cuts so that they can run in sequence with a stop block on the saw. This uses more material than a fully nested plan, but it avoids repeated measuring and small length differences between equal pieces.

The same model then generates assembly instructions that treat the door, roof, side walls, back wall, floor, and seat as individual pieces.

The working drawing contains the detailed drawings and cut lists for the current material sizes.

A fastening review then found a join the drawings did not make explicit. A 120 mm screw from a vertical member into a rail can occupy the same corner as a screw driven from that rail into a diagonal. The door, side, and back diagonals now run corner to corner, with mitred ends stopped at the inner faces of the vertical members. The fastening audit models both screw paths and keeps this clearance as a regression check.

The starting point is recorded beside the working drawing and the field notes.

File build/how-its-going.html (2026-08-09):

FIELD NOTES

# Can AI build a toilet yet?

Field notes 01

## How it's going

Model 0.1.8 · the unit sheets carry their drawings and nothing else.

### Model changelog

- 2026-08-09 · 0.1.8 The unit sheets drop their Hold boxes, so a unit's general arrangement runs straight into its first numbered step.
- 2026-08-08 · 0.1.7 Both finishes are projected in parallel at the unit sheets' elevation, timber is white throughout, the linework is drawn at its stated weights and cut around a heavier silhouette, and the ground, side wall, and door carry dimensions measured off the model.
- 2026-08-07 · 0.1.5 Each unit builds through a numbered sequence of single-operation drawings, with the back panel clad and trimmed flat before it is set between the sides and the floor deck cut before it is fixed.
- 2026-08-02 · 0.1.4 Terminal-board cladding fixings are centred after trimming, and edge fixings clear the modeled beam-screw paths.
- 2026-08-02 · 0.1.3 The interactive line, textured, fallback, and print views share the in-situ render's perspective, scale, and position.
- 2026-08-02 · 0.1.2 Stack H carries all eight beam screws, and Stack J plus the final open SVG use the same model-aligned isometric projection.
- 2026-08-02 · 0.1.1 Seat-top boards run across the removable box, with outer supports and two additional frame screws, to improve integrity around the opening.
- 2026-08-02 · 0.1.1 The seat box is removable at 852 mm, with fixed shell supports, so the box remains serviceable while its front and rear edges stay supported.
- 2026-07-31 · 0.1.1 Diagonal brace ends and screw paths avoid the frame corners, so the fastening audit can report clear nominal paths.
- 2026-07-31 · 0.1.0 The model gained fastening and angle checks, so workshop assembly can be checked against the measured frame.

Saw setup for beam cuts

01 · Saw setup for beam cuts Set the stop before the first beam batch. The 45 × 45 stock stays on one setting while the blanks are cut to length.

Beam cuts

02 · Beam cuts Mark each piece as it leaves the saw. The cut parts are now ready to move into their lettered unit stacks.

Sorted beam cuts

03 · Sorted beam cuts The cut beams are grouped by mark before they move into their assembly stacks.

Download the workshop video

Workshop clip · Cutting the cladding batch A field recording from the first cladding-cutting session.

Assembling frames

04 · Assembling frames A clamp holds a frame joint square while the next frame is assembled.

Side panel assembled

05 · Side panel assembled A braced side panel, marked and ready to join to the rest of the shell.

Assembling the side

06 · Assembling the side The side frame and cladding come together around the diagonal brace.

Sides standing

07 · Sides standing Both side panels are standing while the floor frame is prepared below them.

Sides and floor

08 · Sides and floor The side panels meet the floor frame and the shell starts to read as one unit.

Shell assembled

09 · Shell assembled Sides, back, floor, and seat are joined and standing on site, with the roof still to go on.

Roof sheets laid on

10 · Roof sheets laid on The door is hung and the corrugated sheets rest on the rafters, weighted down until they are fixed.

Seat test

11 · Seat test The first sit-down proves the seat height and the depth of the shell against the drawing.

Progress follows the drawing. More field notes will be added as the build moves on.

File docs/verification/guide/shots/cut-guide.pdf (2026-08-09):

W O R K I N G D R A W I N G

# CAN AI BUILD A TOILET YET?

An experiment in re-drawing a technical drawing as an editable
parametric CAD model with Claude and Codex.
PROJECT | DASS
ISSUE | 2026-07-30
ARCHITECT | @HANNES.SODERQUIST (https://www.instagram.com/hannes.soderquist/)
CODE | @FEELEPXYZ (https://x.com/feelepxyz)
SOURCE | GITHUB (https://github.com/feelepxyz/dass)
UNITS | MILLIMETRES
KERF | 2.8 MM PER CUT
SHEETS | A-200 TO A-400

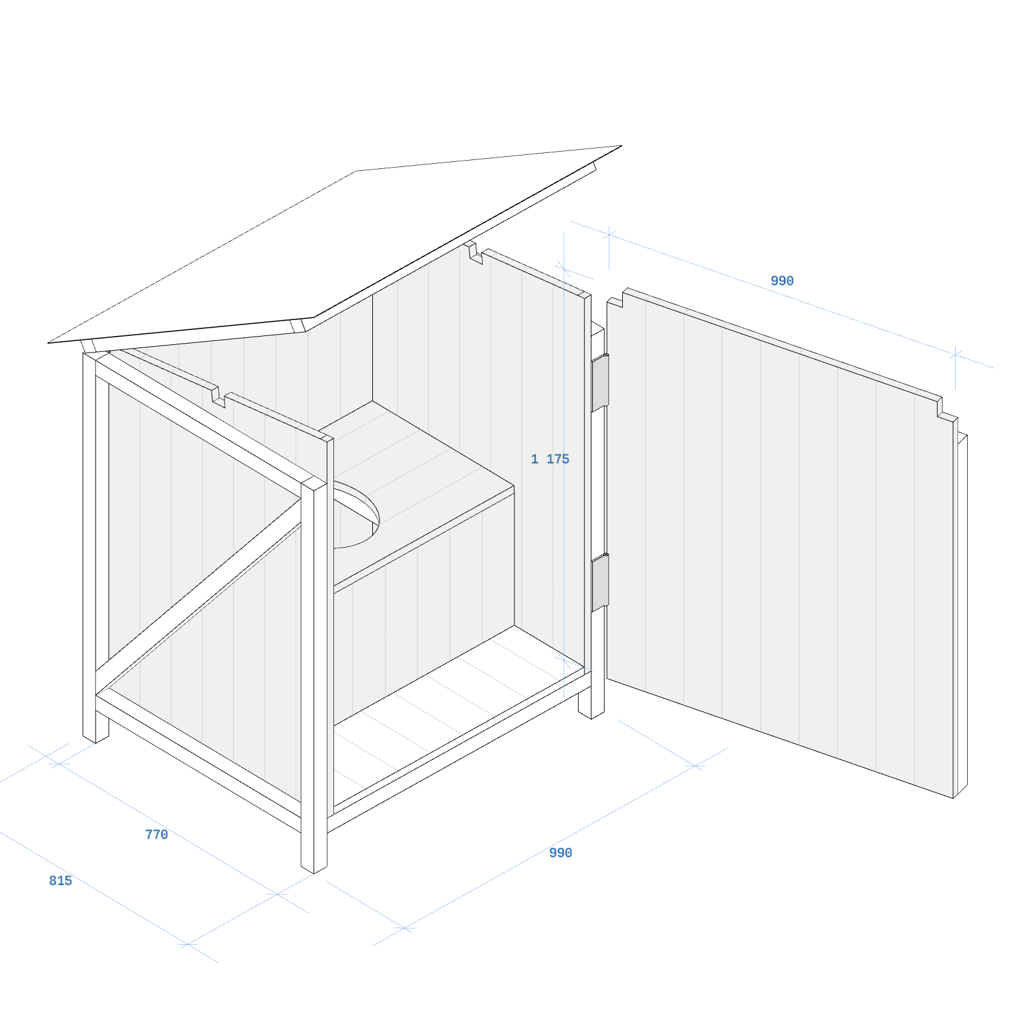
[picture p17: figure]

The finished building.

# STRUCTURAL TIMBER

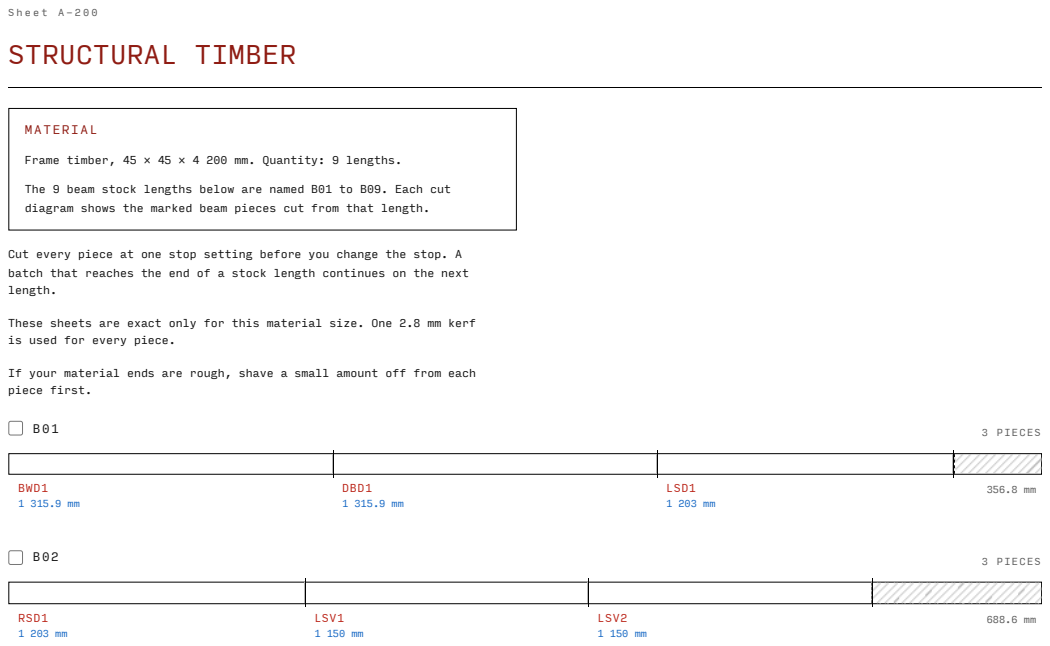
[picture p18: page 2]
MATERIAL; 3 PIECES; BWD1 1 315.9 mm; DBD1 1 315.9 mm; LSD1 1 203 mm; RSD1 1 203 mm; LSV1 1 150 mm; LSV2 1 150 mm

Frame timber, 45 × 45 × 4 200 mm. Quantity: 9 lengths.

The 9 beam stock lengths below are named B01 to B09. Each cut
diagram shows the marked beam pieces cut from that length.

Cut every piece at one stop setting before you change the stop. A
batch that reaches the end of a stock length continues on the next
length.

These sheets are exact only for this material size. One 2.8 mm kerf
is used for every piece.

If your material ends are rough, shave a small amount off from each
piece first.

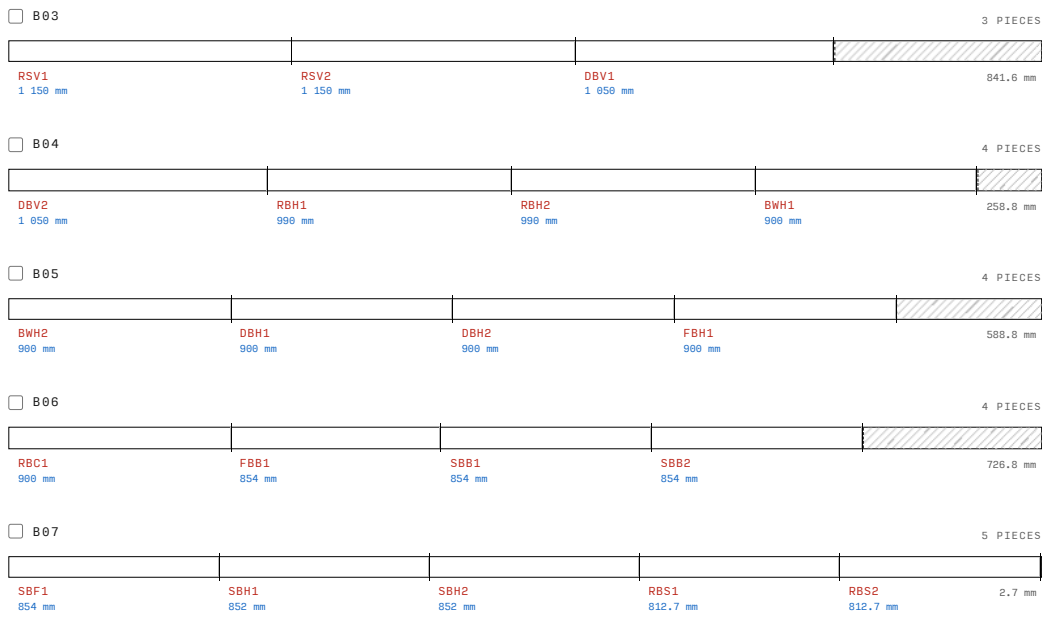
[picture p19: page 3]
3 PIECES; 4 PIECES; 5 PIECES; RSV1 1 150 mm; RSV2 1 150 mm; DBV1 1 050 mm; DBV2 1 050 mm; RBH1 990 mm; RBH2 990 mm; BWH1 900 mm; BWH2 900 mm; DBH1 900 mm; DBH2 900 mm; FBH1 900 mm; RBC1 900 mm; FBB1 854 mm; SBB1 854 mm; SBB2 854 mm; SBF1 854 mm; SBH1 852 mm; SBH2 852 mm; RBS1 812.7 mm; RBS2 812.7 mm

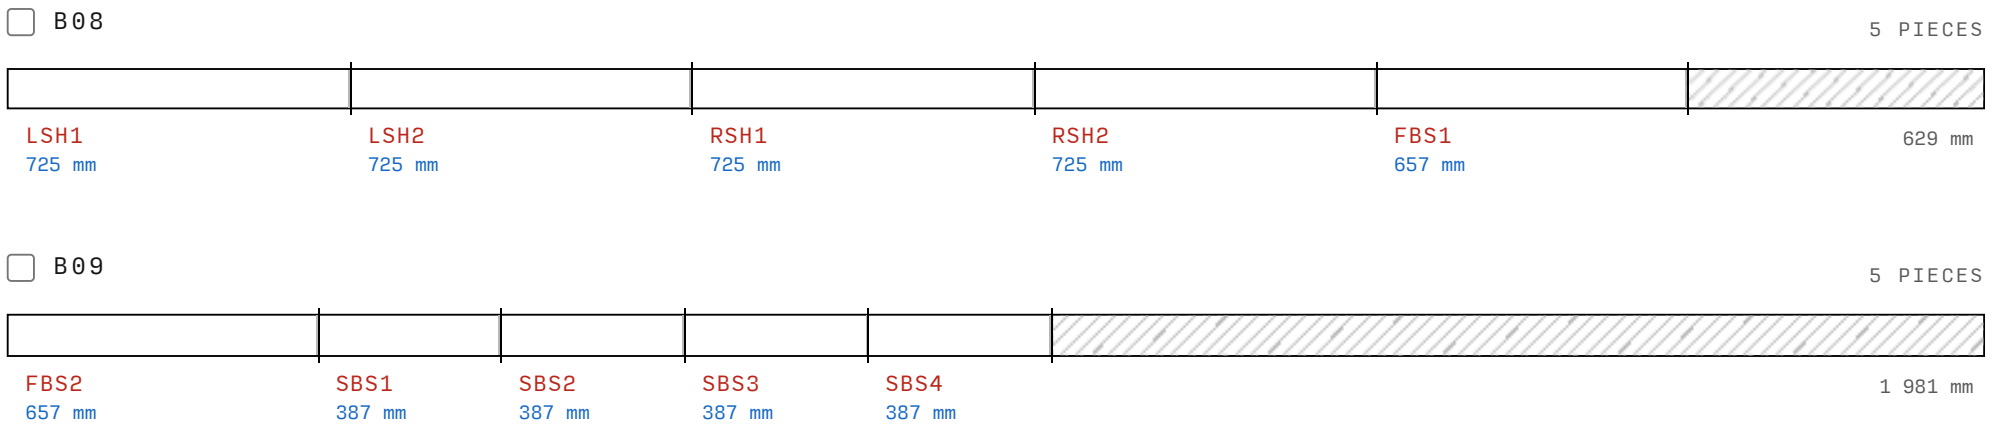
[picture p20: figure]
5 PIECES; LSH1 725 mm; LSH2 725 mm; RSH1 725 mm; RSH2 725 mm; FBS1 657 mm; FBS2 657 mm; SBS1 387 mm; SBS2 387 mm; SBS3 387 mm; SBS4 387 mm

# RÅSPONT (MATCHBOARD/V-GROOVE CLADDING)

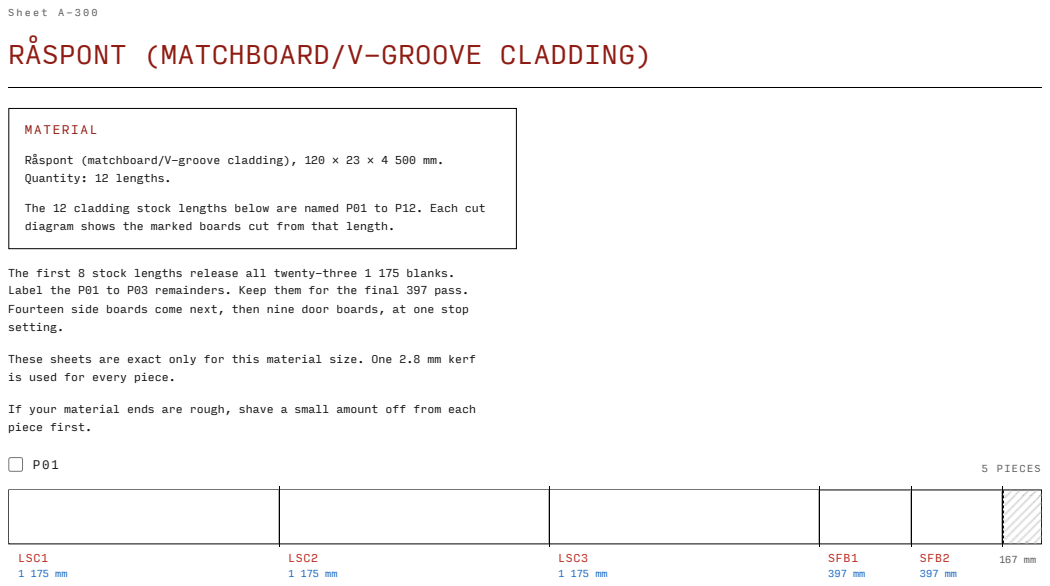
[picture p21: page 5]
MATERIAL; 5 PIECES; LSC1 1 175 mm; LSC2 1 175 mm; LSC3 1 175 mm; SFB1 397 mm; SFB2 397 mm

Råspont (matchboard/V-groove cladding), 120 × 23 × 4 500 mm.
Quantity: 12 lengths.

The 12 cladding stock lengths below are named P01 to P12. Each cut
diagram shows the marked boards cut from that length.

The first 8 stock lengths release all twenty-three 1 175 blanks.
Label the P01 to P03 remainders. Keep them for the final 397 pass.
Fourteen side boards come next, then nine door boards, at one stop
setting.

These sheets are exact only for this material size. One 2.8 mm kerf
is used for every piece.

If your material ends are rough, shave a small amount off from each
piece first.

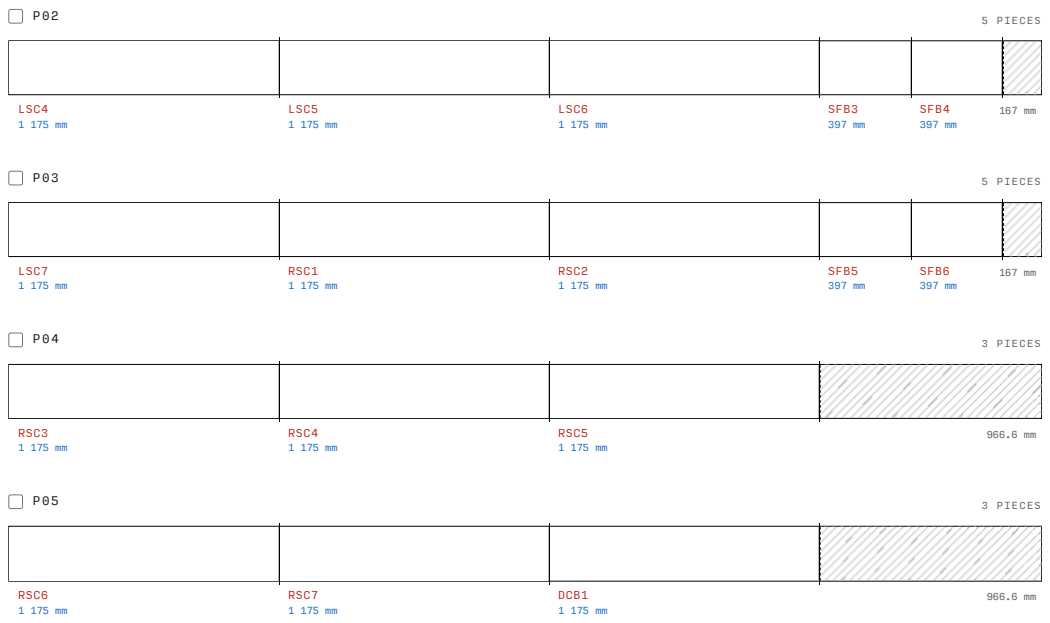
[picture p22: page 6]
5 PIECES; 3 PIECES; LSC4 1 175 mm; LSC5 1 175 mm; LSC6 1 175 mm; SFB3 397 mm; SFB4 397 mm; LSC7 1 175 mm; RSC1 1 175 mm; RSC2 1 175 mm; SFB5 397 mm; SFB6 397 mm; RSC3 1 175 mm; RSC4 1 175 mm; RSC5 1 175 mm; RSC6 1 175 mm; RSC7 1 175 mm; DCB1 1 175 mm

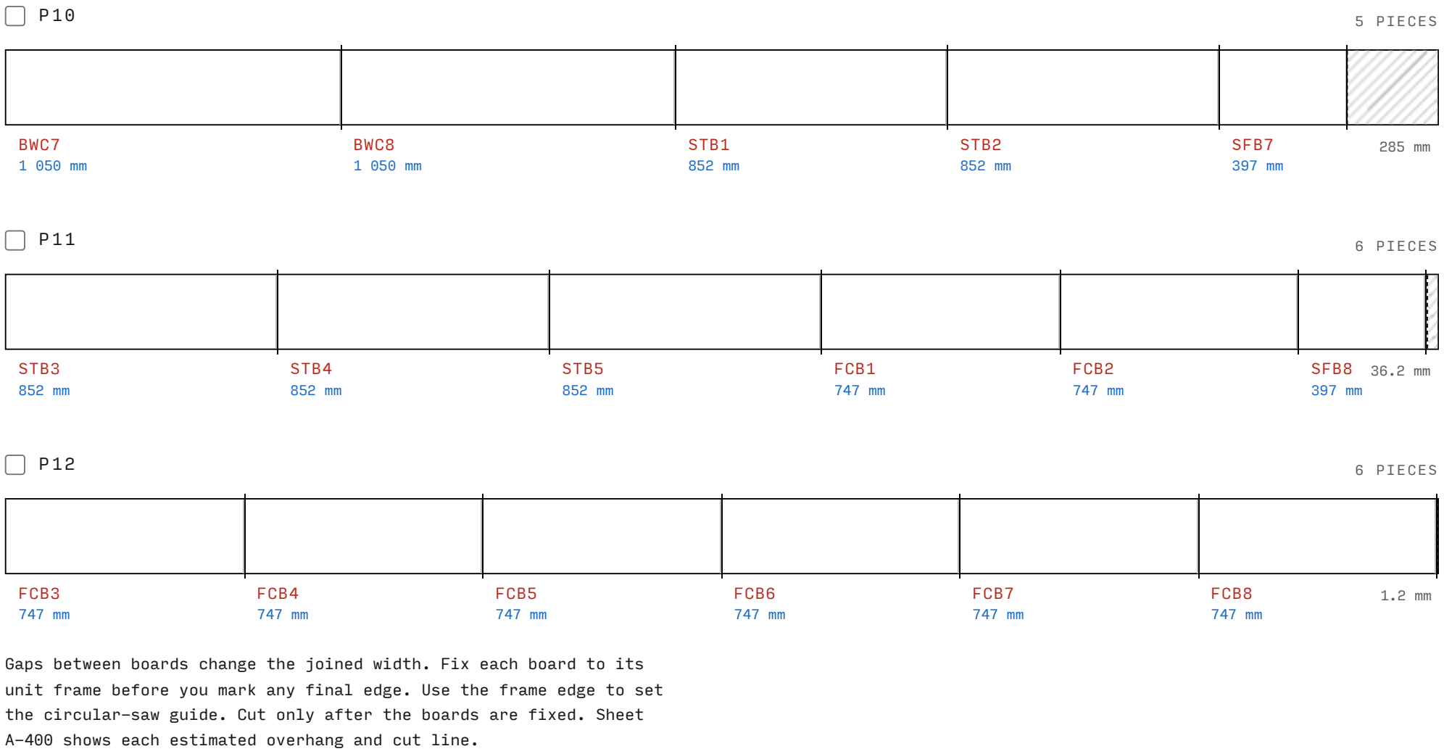
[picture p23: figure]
5 PIECES; 6 PIECES; BWC7 1 050 mm; BWC8 1 050 mm; STB1 852 mm; STB2 852 mm; SFB7 397 mm; STB3 852 mm; STB4 852 mm; STB5 852 mm; FCB1 747 mm; FCB2 747 mm; SFB8 397 mm; FCB3 747 mm; FCB4 747 mm; FCB5 747 mm; FCB6 747 mm; FCB7 747 mm; FCB8 747 mm

Gaps between boards change the joined width. Fix each board to its unit frame before you mark any final edge. Use the frame edge to set the circular-saw guide. Cut only after the boards are fixed. Sheet A-400 shows each estimated overhang and cut line.

S h e e t A - 4 0 0

# UNIT DRAWINGS AND ASSEMBLY

Each unit opens with its general arrangement, dimensioned and coded off the model, then builds through its own numbered steps. A step draws one operation: work already done ghosts back, work this step touches goes solid, and the band under the drawing names the operation before the caption is read.

Black screw paths are measured 120 mm screws: each starts on the source beam and finishes in the centre of the receiving section. Diagonal paths follow the diagonal beam from its mitred end.

ASSEMBLY HARDWARE

Use these fasteners for the timber assembly.

USE | FASTENER
Frame beams and braces | 6 × 120 mm sunk wood screws
Beam-to-beam support joints, for example floor supports | 6 × 90 mm sunk wood screws
Råspont (matchboard/V-groove cladding) to beams | 2.8 × 60 mm nails or 6 × 60 mm sunk wood screws

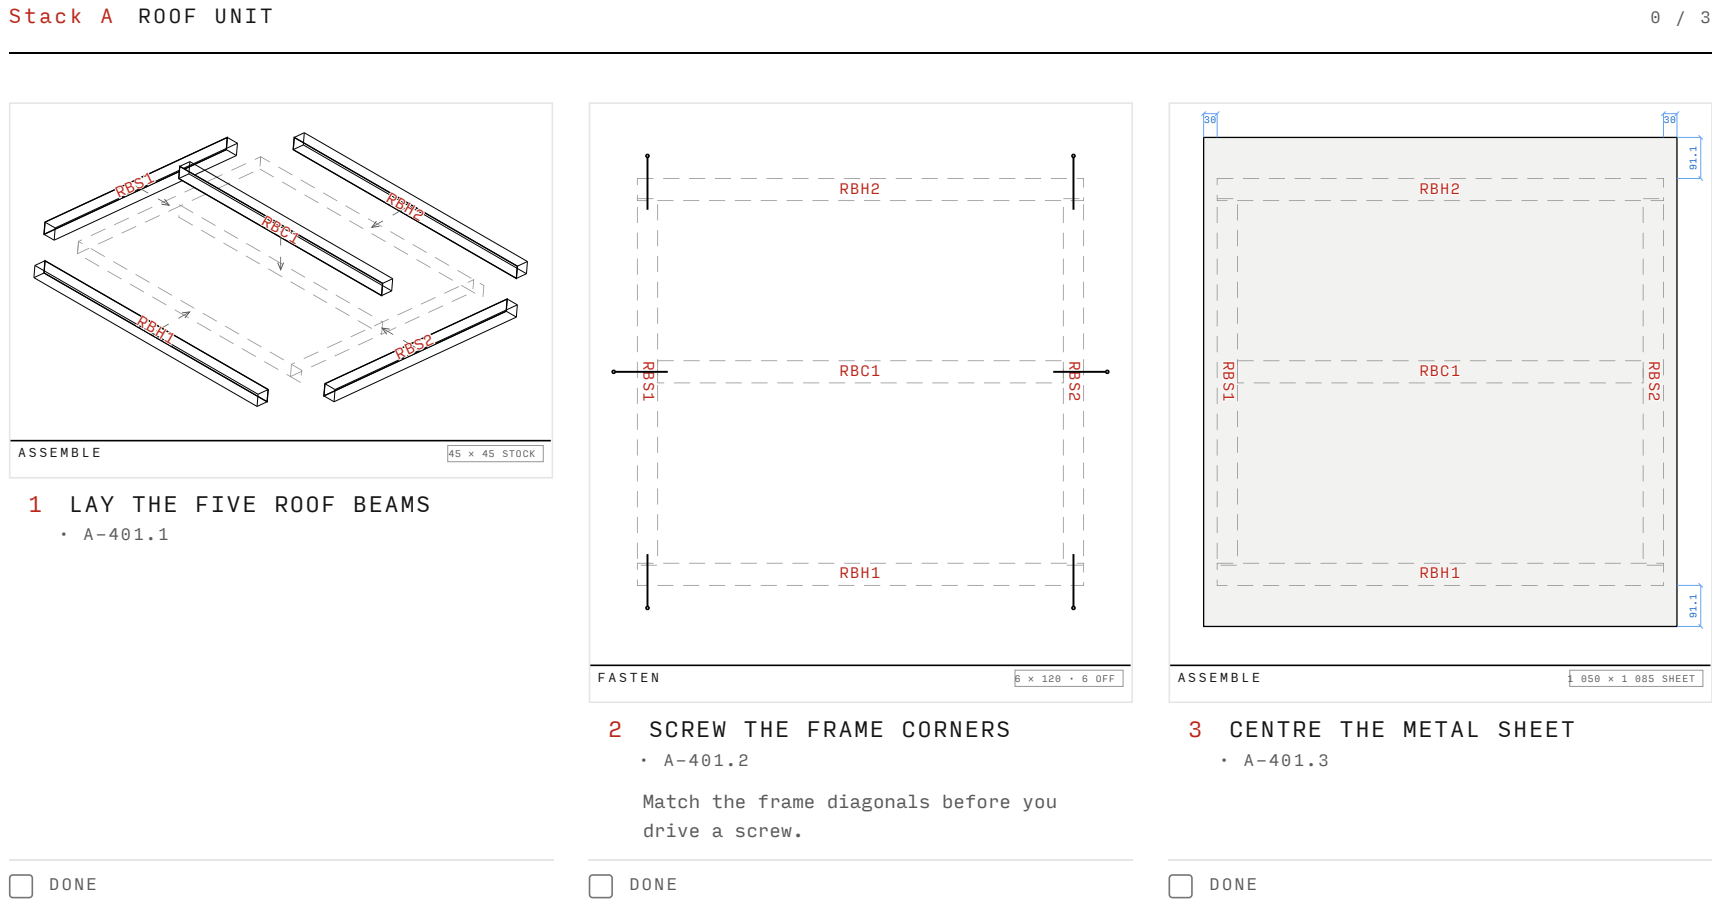
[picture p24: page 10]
Stack A ROOF UNIT; RBH1; RBH2; RBS1; RBS2; RBC1; 45 × 45 STOCK; DONE; 6 × 120 · 6 OFF; 1 050 × 1 085 SHEET

1 LAY THE FIVE ROOF BEAMS

2 SCREW THE FRAME CORNERS
Match the frame diagonals before you
drive a screw.

3 CENTRE THE METAL SHEET

seen from outside the door · hatched edge is the estimated

on-frame trim

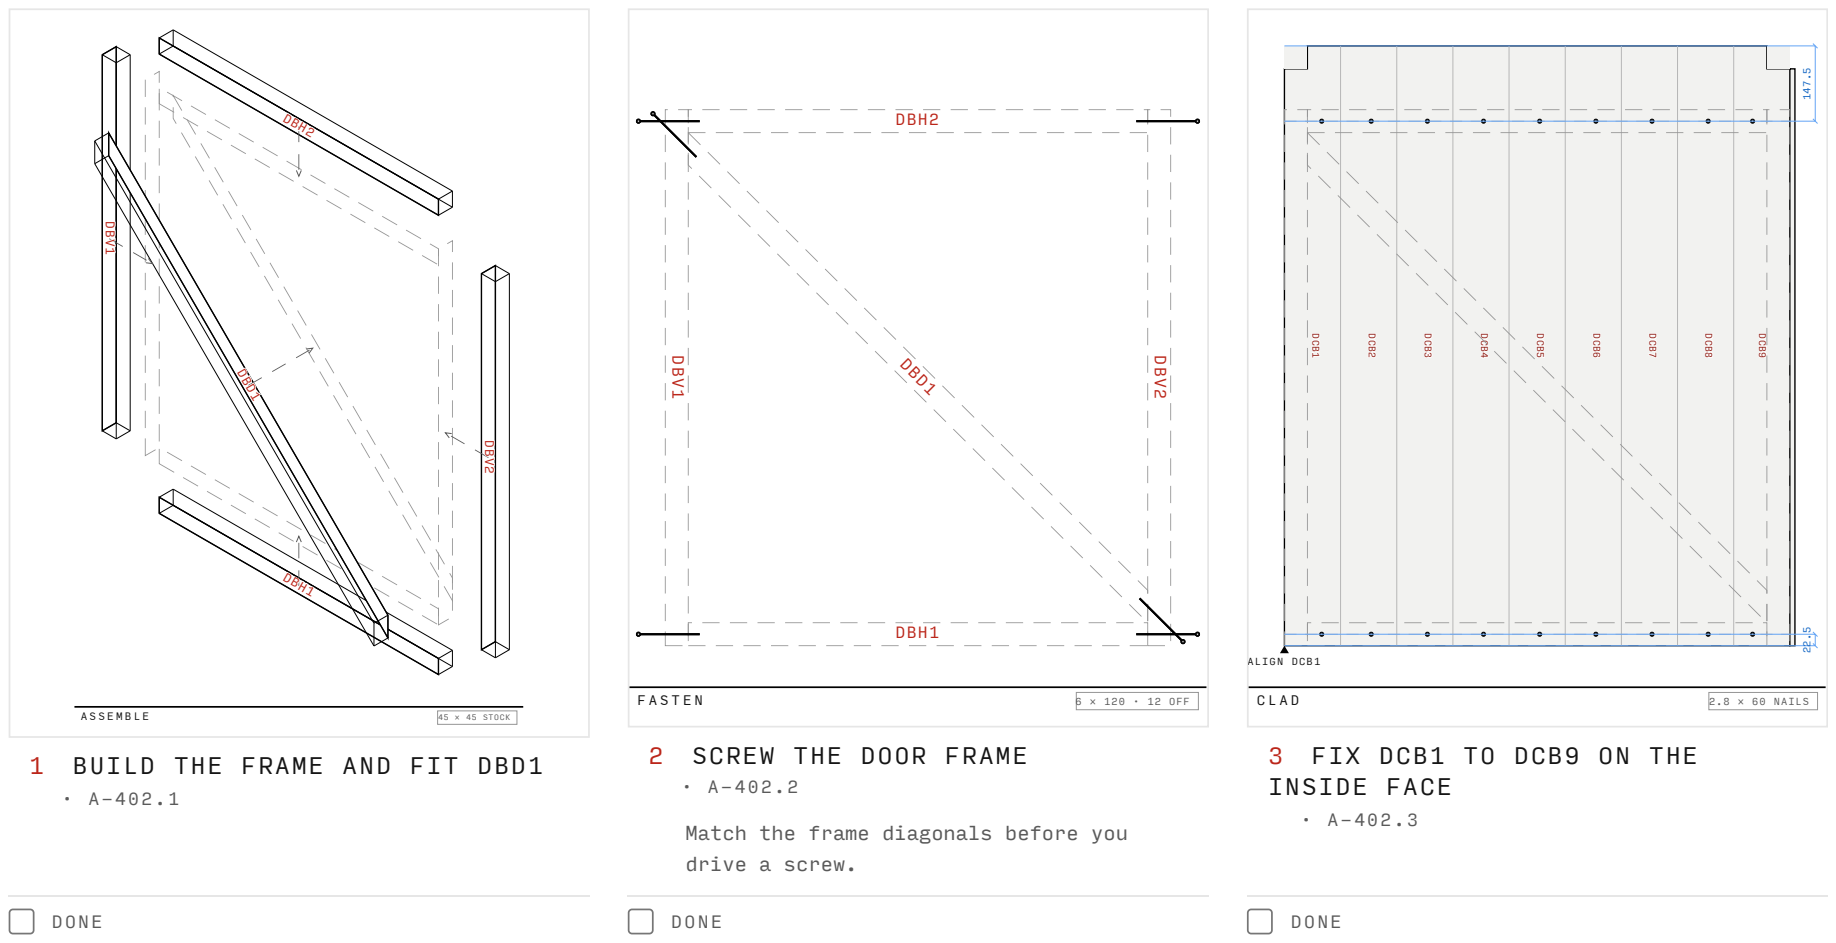
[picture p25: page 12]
DBV1; DBV2; DBH1; DBH2; DBD1; 45 × 45 STOCK; DONE; 6 × 120 · 12 OFF; DCB1; DCB2; DCB3; DCB4; DCB5; DCB6; DCB7; DCB8; DCB9; AALLIIGGNN DDCCBB11; 2.8 × 60 NAILS

2 SCREW THE DOOR FRAME

3 FIX DCB1 TO DCB9 ON THE
INSIDE FACE

1 BUILD THE FRAME AND FIT DBD1

Match the frame diagonals before you
drive a screw.

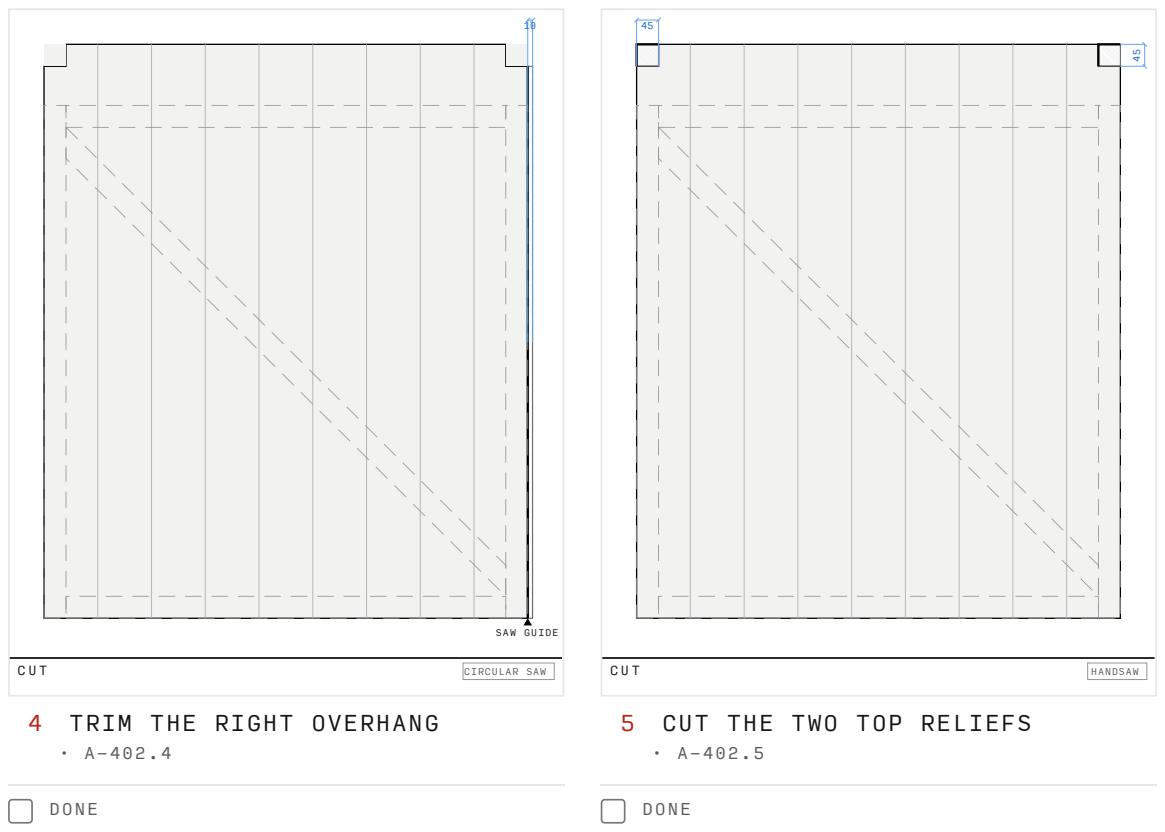
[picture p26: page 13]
SSAAWW GGUUIIDDEE; CIRCULAR SAW; DONE; HANDSAW

4 TRIM THE RIGHT OVERHANG

5 CUT THE TWO TOP RELIEFS

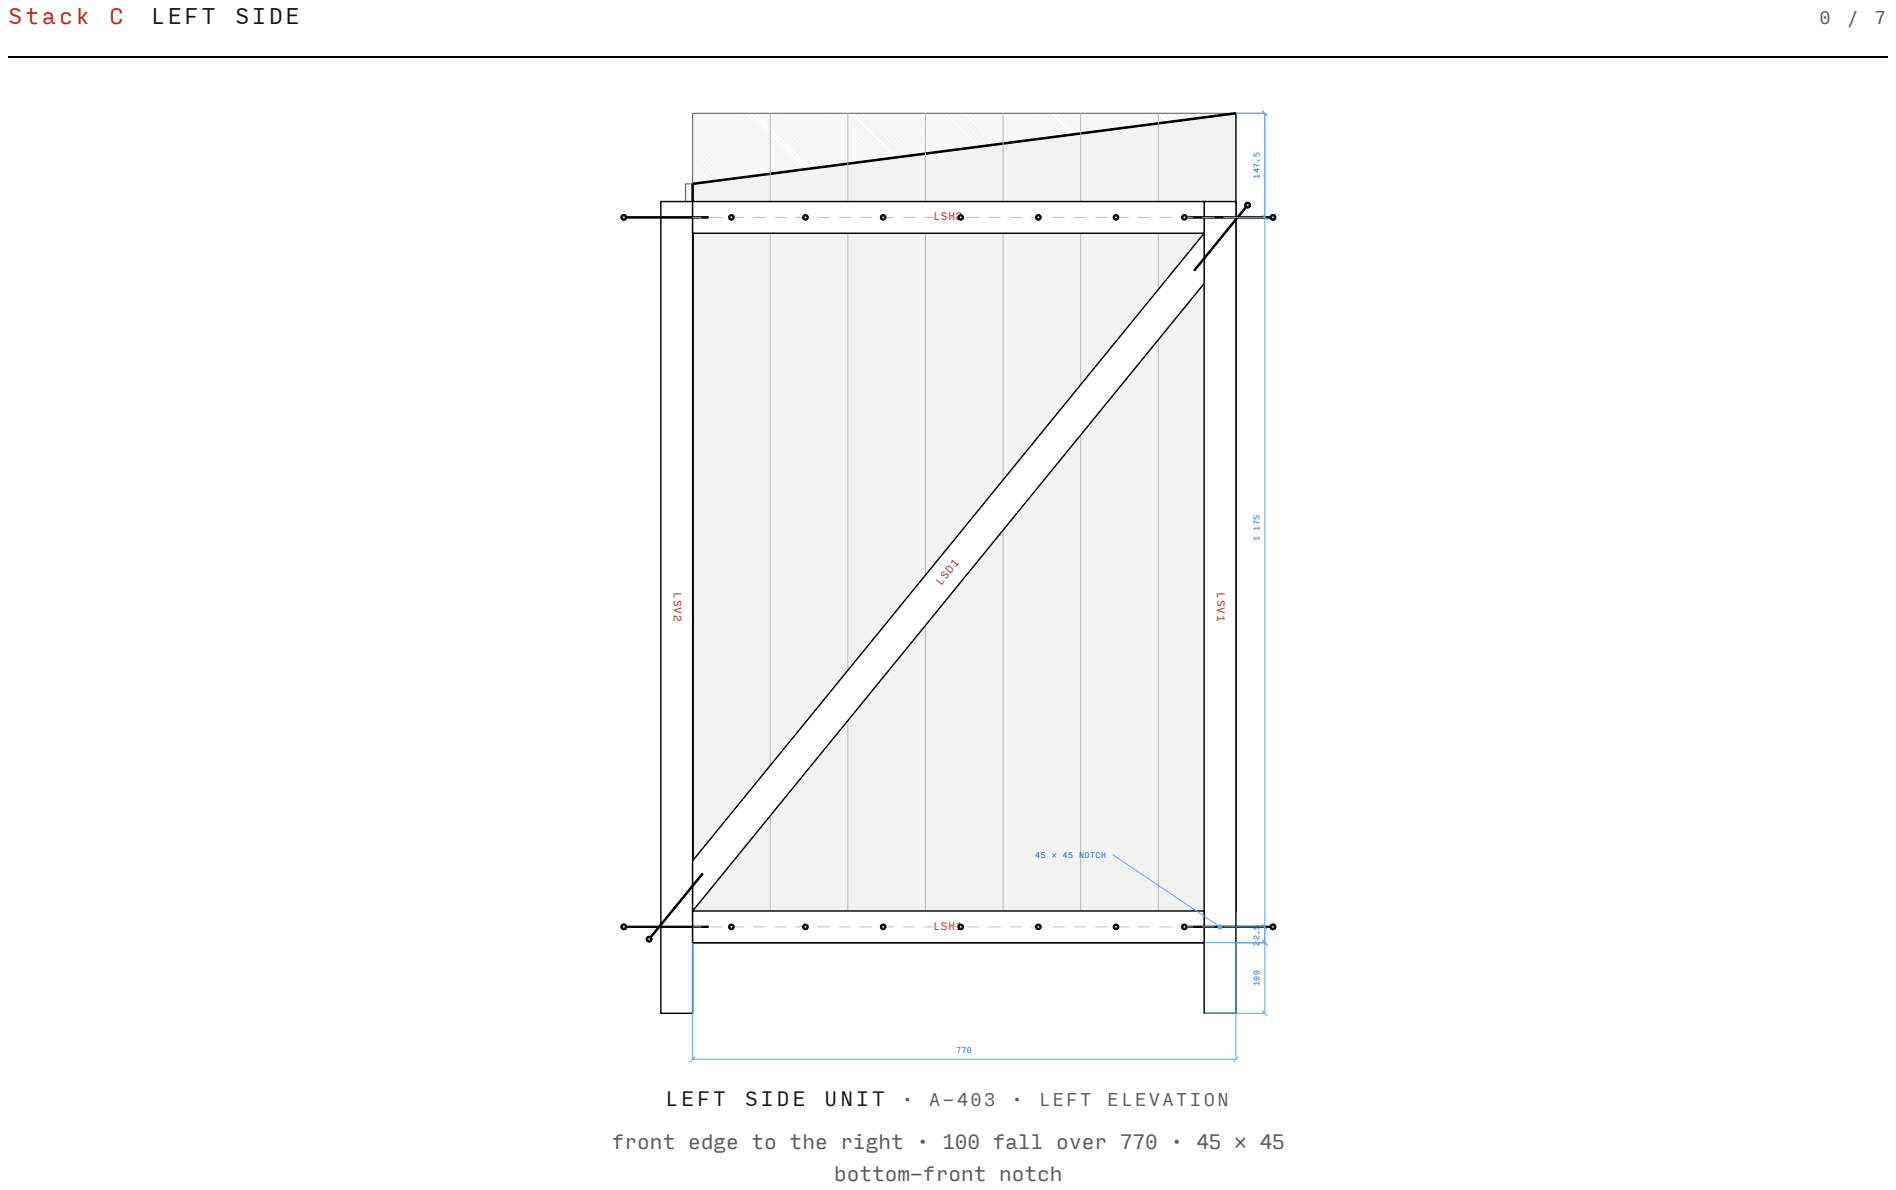
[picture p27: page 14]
Stack C LEFT SIDE; LSV1; LSV2; LSH1; LSH2; LSD1; NOTCH

L E F T S I D E U N I T · A-403 · LEFT ELEVATION
front edge to the right · 100 fall over 770 · 45 × 45

bottom-front notch

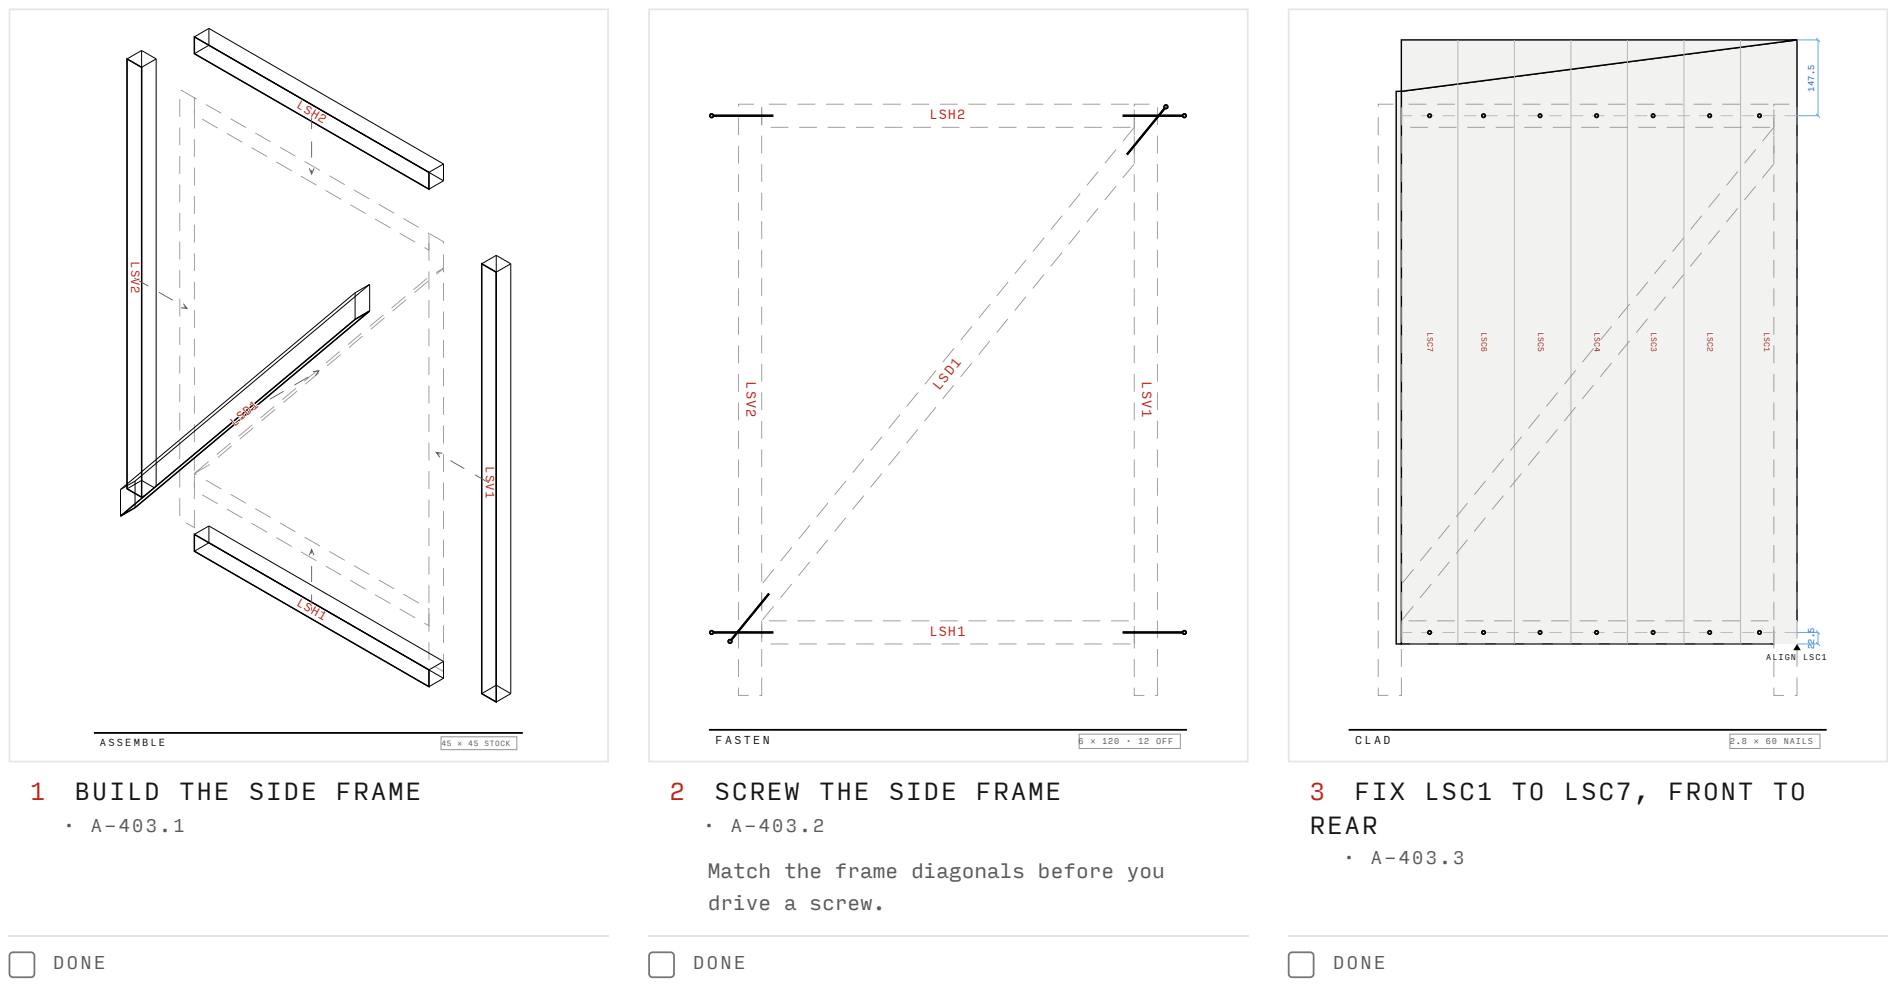
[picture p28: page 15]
LSV1; LSV2; LSH1; LSH2; LSD1; 45 × 45 STOCK; DONE; 6 × 120 · 12 OFF; LSC1; LSC2; LSC3; LSC4; LSC5; LSC6; LSC7; AALLIIGGNN; LLSSCC11; 2.8 × 60 NAILS

1 BUILD THE SIDE FRAME

2 SCREW THE SIDE FRAME
Match the frame diagonals before you
drive a screw.

3 FIX LSC1 TO LSC7, FRONT TO
REAR

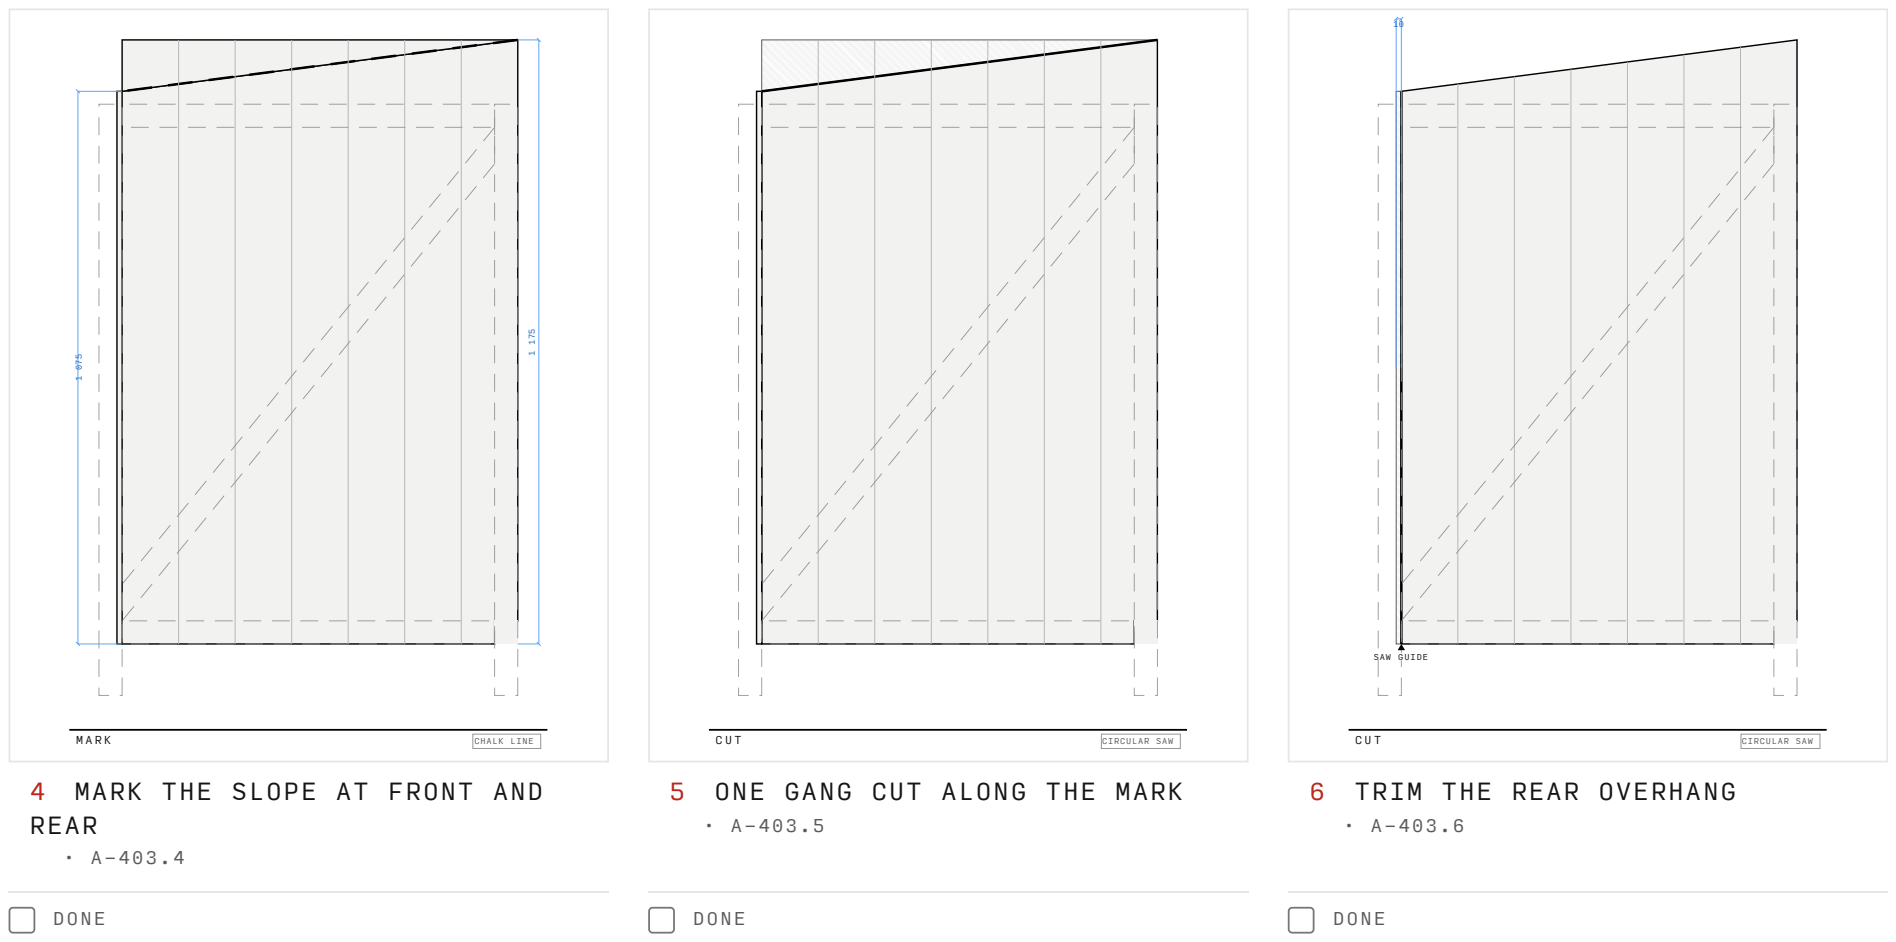
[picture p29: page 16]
CHALK LINE; DONE; CIRCULAR SAW; SSAAWW GGUUIIDDEE

4 MARK THE SLOPE AT FRONT AND
REAR

5 ONE GANG CUT ALONG THE MARK

6 TRIM THE REAR OVERHANG

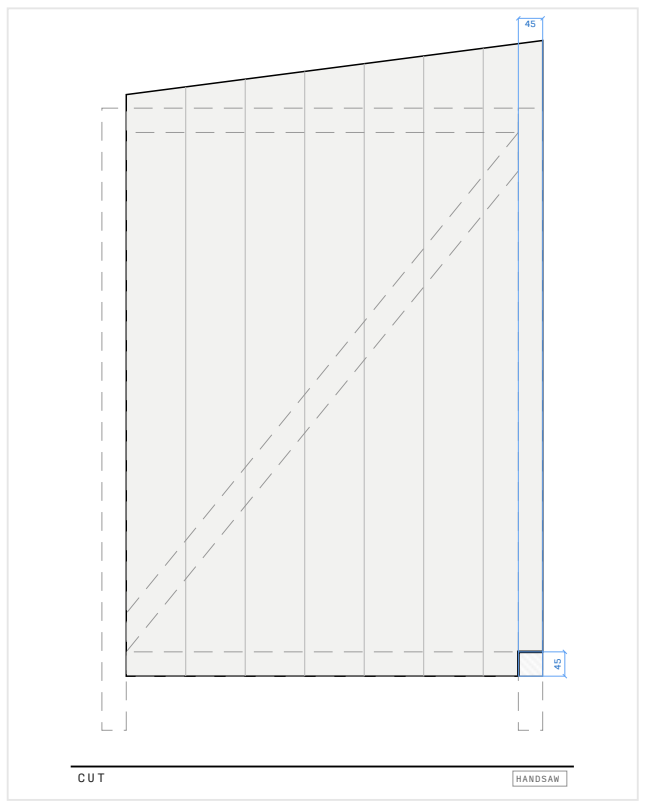
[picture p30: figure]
HANDSAW

### 7 CUT THE BOTTOM-FRONT NOTCH

- A-403.7

DONE

R I G H T S I D E U N I T · A-404 · RIGHT ELEVATION
front edge to the left · 100 fall over 770 · 45 × 45

bottom-front notch

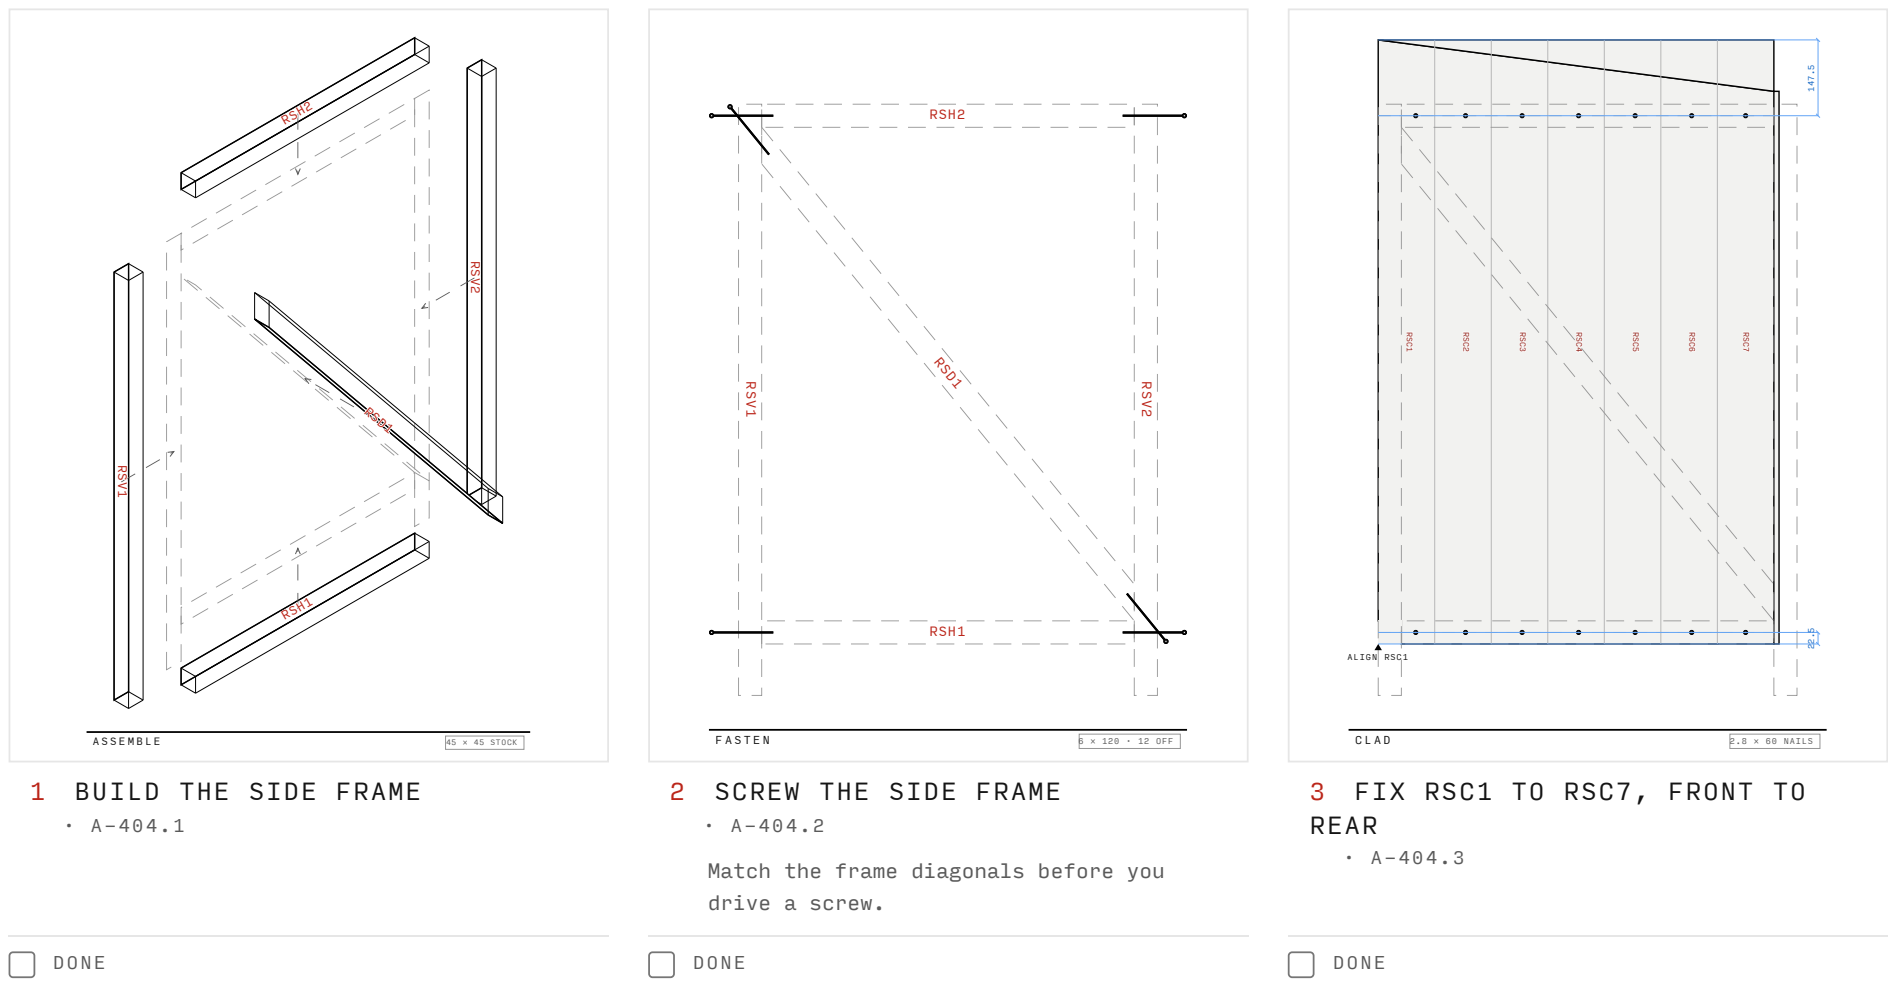
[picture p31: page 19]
RSV1; RSV2; RSH1; RSH2; RSD1; 45 × 45 STOCK; DONE; 6 × 120 · 12 OFF; RSC1; RSC2; RSC3; RSC4; RSC5; RSC6; RSC7; AALLIIGGNN; RRSSCC11; 2.8 × 60 NAILS

1 BUILD THE SIDE FRAME

2 SCREW THE SIDE FRAME
Match the frame diagonals before you
drive a screw.

3 FIX RSC1 TO RSC7, FRONT TO
REAR

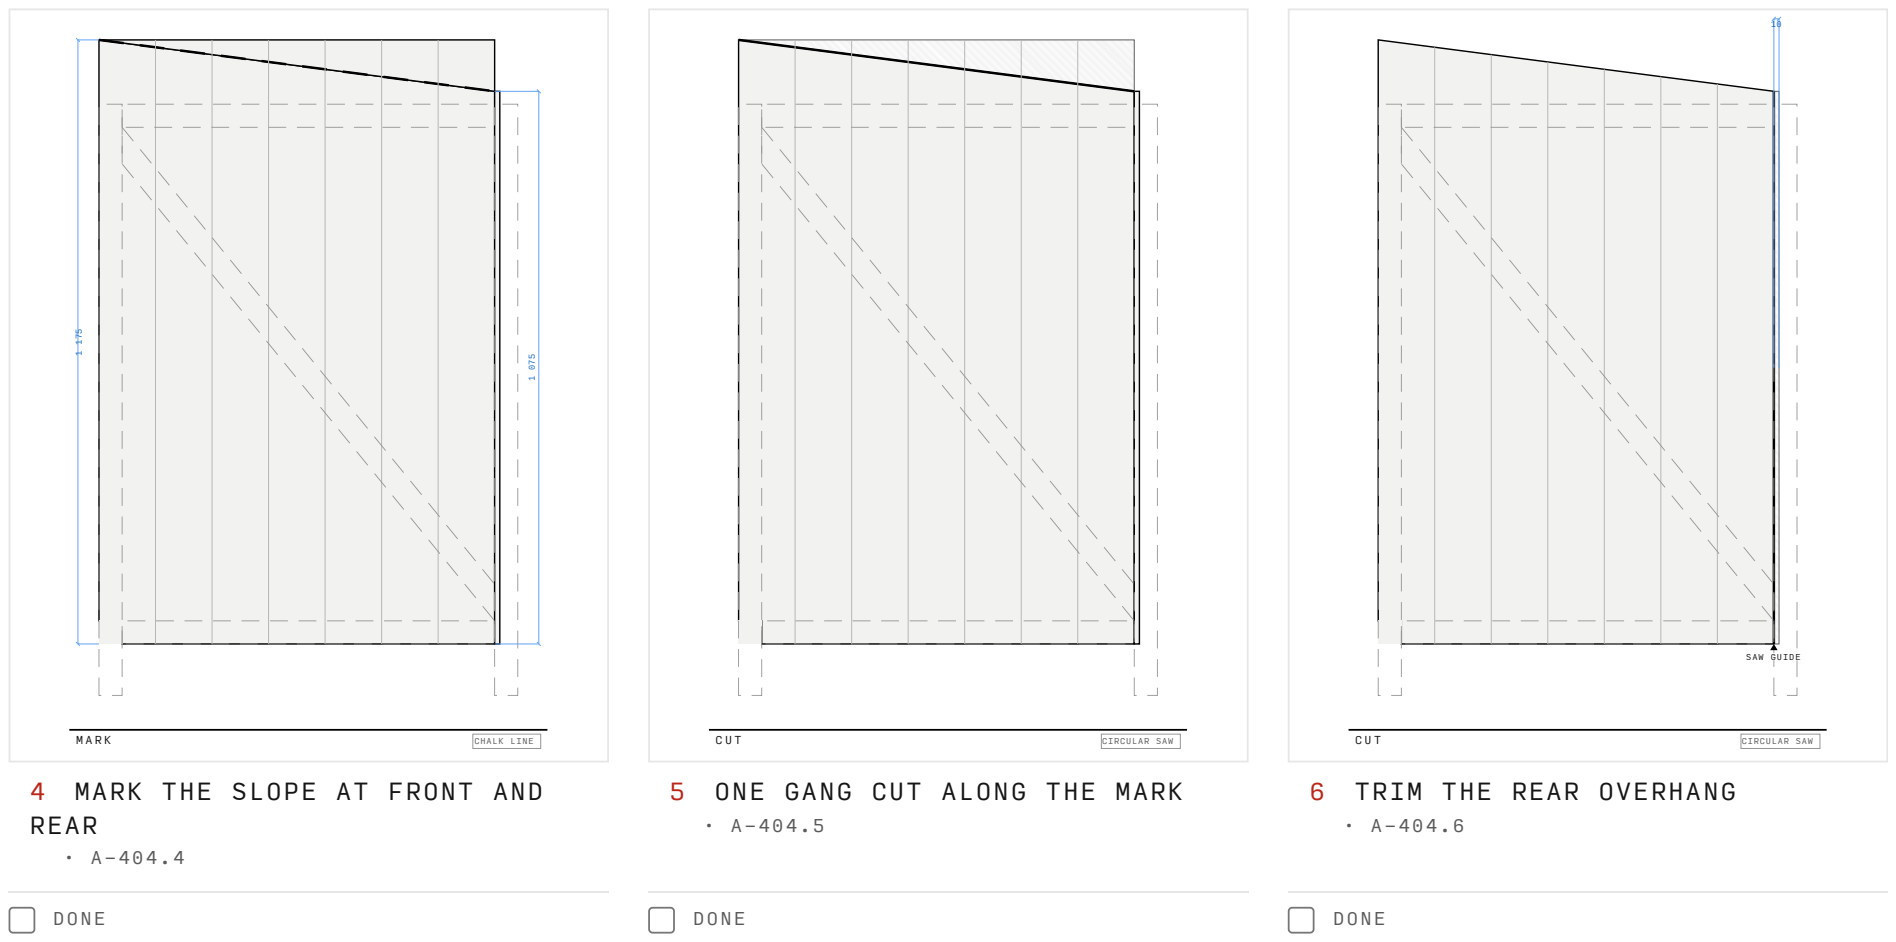
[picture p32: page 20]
CHALK LINE; DONE; CIRCULAR SAW; SSAAWW; GGUUIIDDEE

4 MARK THE SLOPE AT FRONT AND
REAR

5 ONE GANG CUT ALONG THE MARK

6 TRIM THE REAR OVERHANG

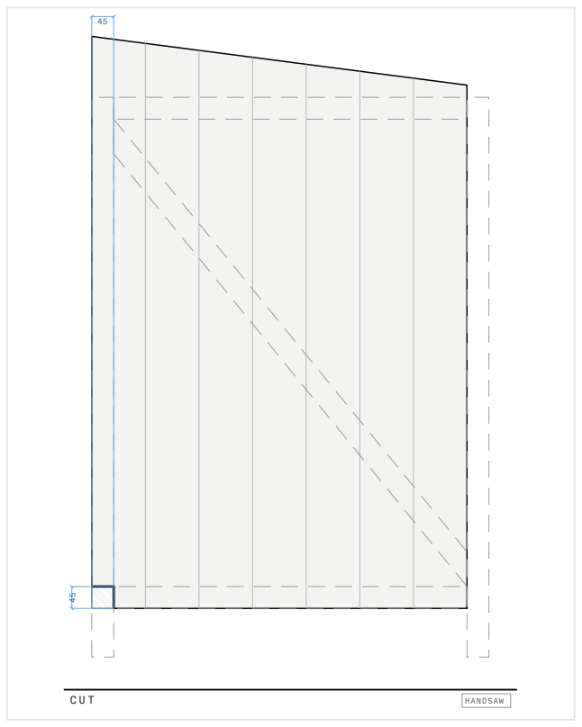
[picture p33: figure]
HANDSAW

### 7 CUT THE BOTTOM-FRONT NOTCH

- A-404.7

DONE

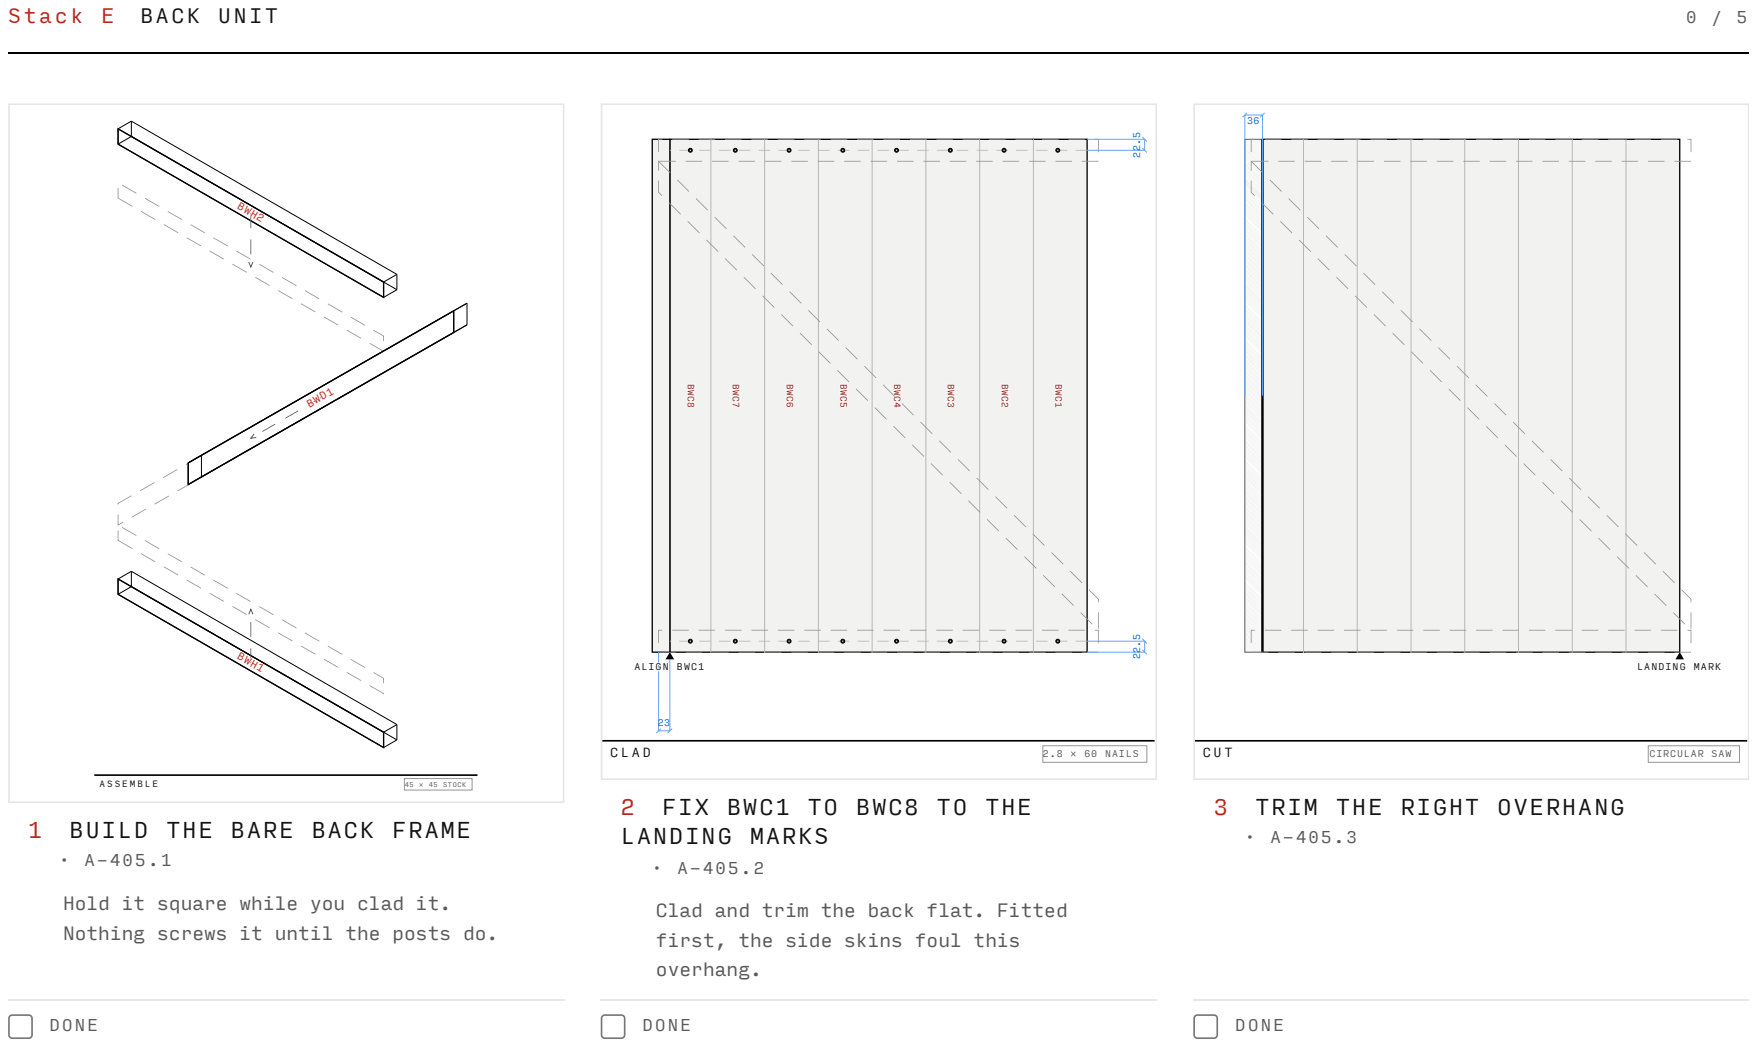
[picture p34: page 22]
Stack E BACK UNIT; BWH1; BWH2; BWD1; 45 × 45 STOCK; DONE; BWC1; BWC2; BWC3; BWC4; BWC5; BWC6; BWC7; BWC8; AALLIIGGNN; BBWWCC11; 2.8 × 60 NAILS; LLAANNDDIINNGG MMAARRKK; CIRCULAR SAW

2 FIX BWC1 TO BWC8 TO THE
LANDING MARKS
Clad and trim the back flat. Fitted
first, the side skins foul this
overhang.

3 TRIM THE RIGHT OVERHANG

1 BUILD THE BARE BACK FRAME

Hold it square while you clad it.
Nothing screws it until the posts do.

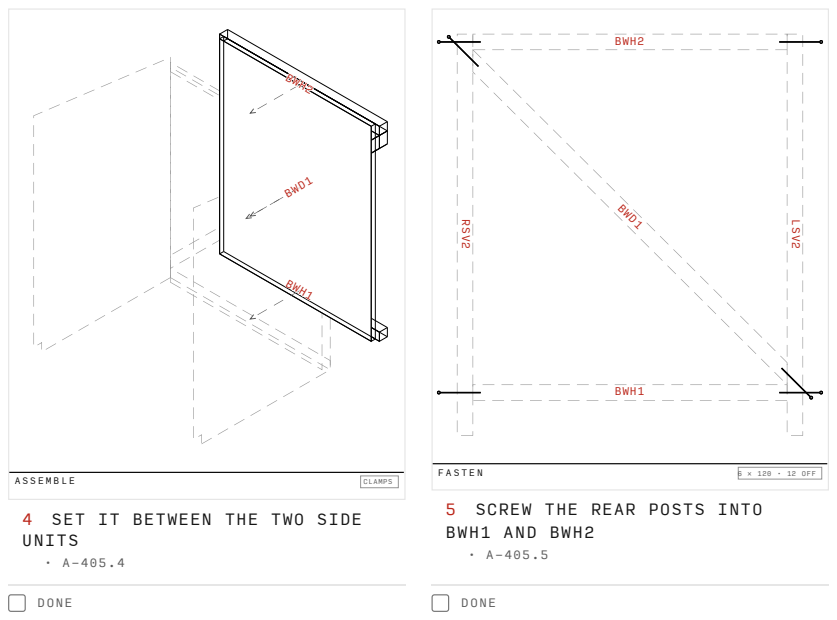
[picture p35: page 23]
BWH1; BWH2; BWD1; CLAMPS; DONE; 6 × 120 · 12 OFF

5 SCREW THE REAR POSTS INTO
BWH1 AND BWH2

4 SET IT BETWEEN THE TWO SIDE
UNITS

2 SCREW ALL FOUR BEAMS TO THE
SHELL

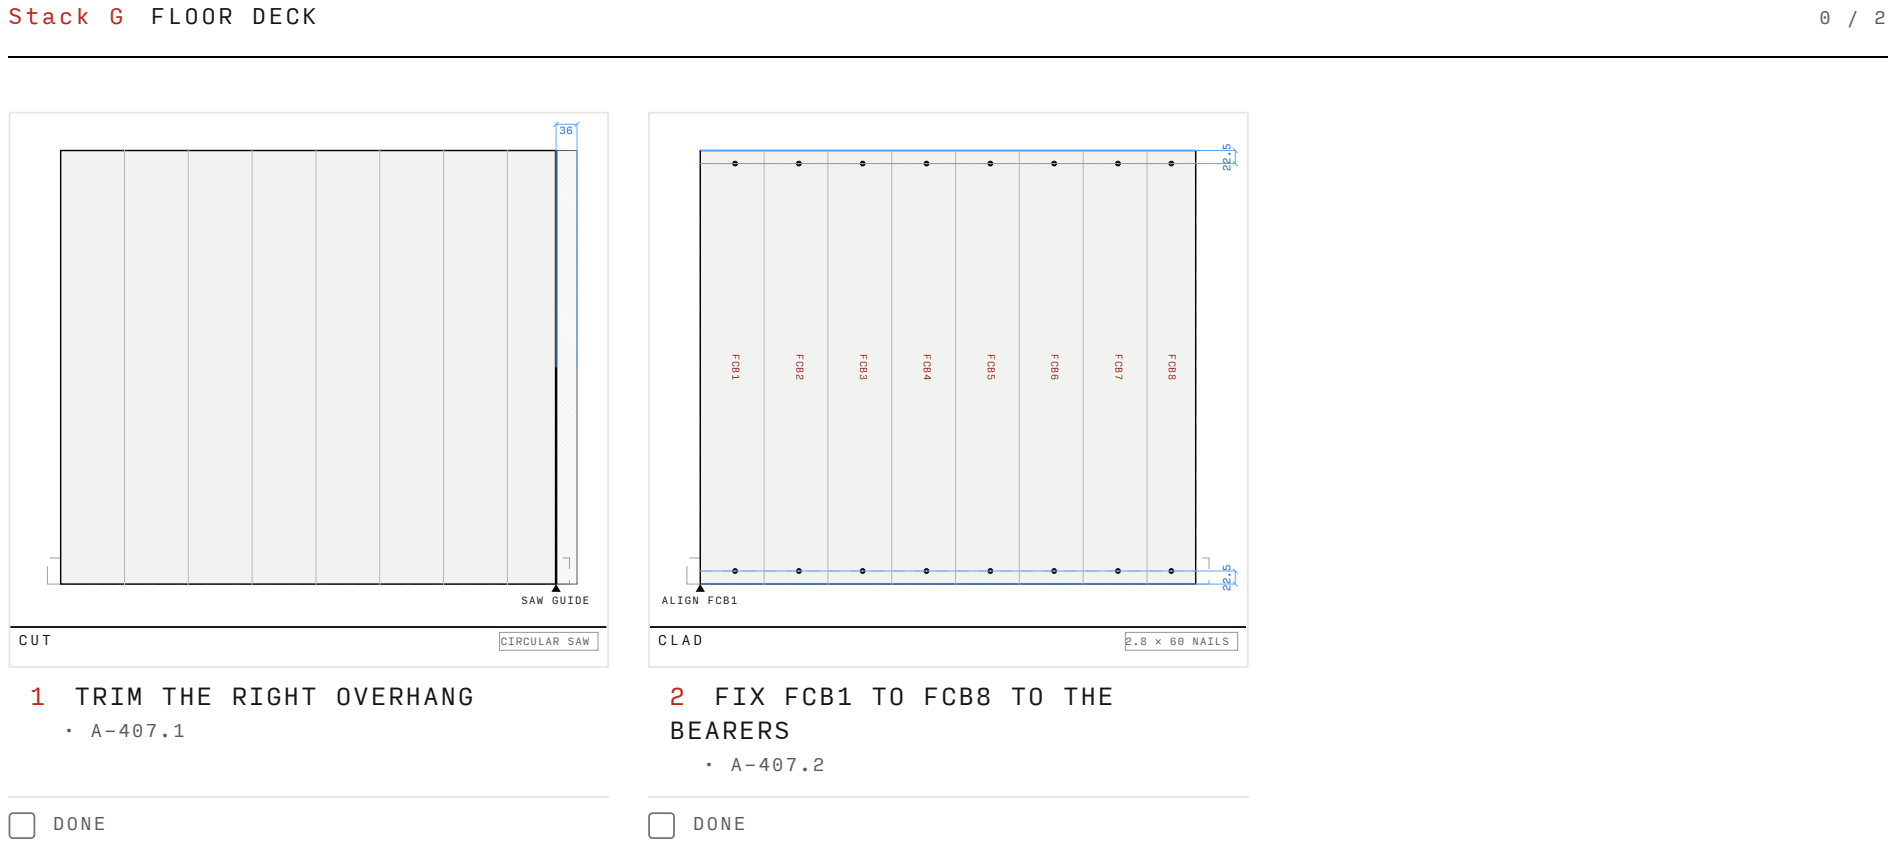
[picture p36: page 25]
Stack G FLOOR DECK; FBB1; FBS1; FBS2; FBH1; SSAAWW GGUUIIDDEE; CIRCULAR SAW; DONE; FCB1; FCB2; FCB3; FCB4; FCB5; FCB6; FCB7; FCB8; AALLIIGGNN FFCCBB11; 2.8 × 60 NAILS

1 TRIM THE RIGHT OVERHANG

2 FIX FCB1 TO FCB8 TO THE
BEARERS

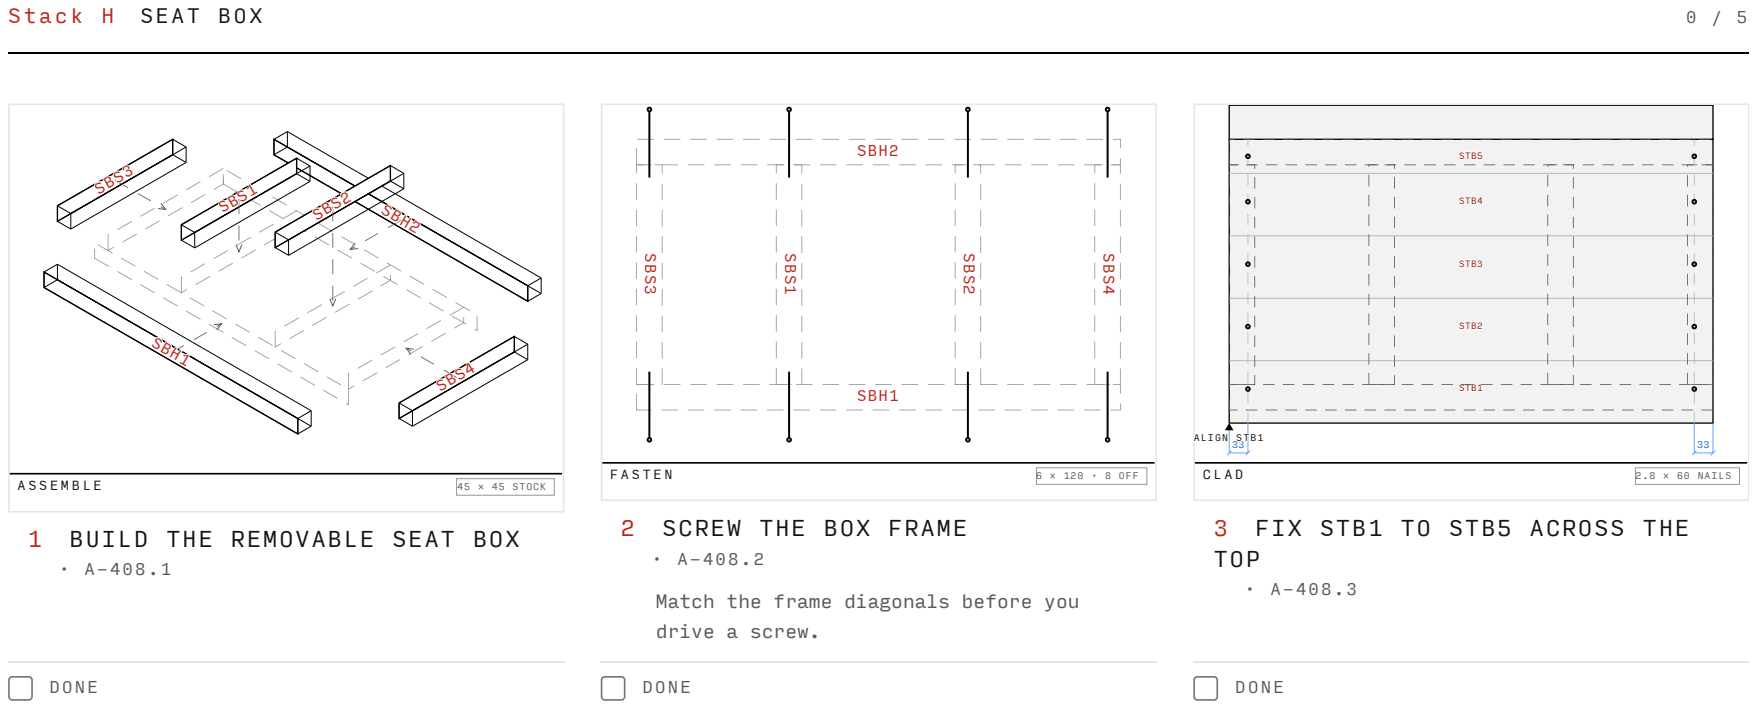
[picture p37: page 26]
Stack H SEAT BOX; SBH1; SBH2; SBS3; SBS4; SBS1; SBS2; 45 × 45 STOCK; DONE; SBS; 6 × 120 · 8 OFF; STB1; STB2; STB3; STB4; STB5; AALLIIGGNN; SSTTBB11; 2.8 × 60 NAILS

1 BUILD THE REMOVABLE SEAT BOX

2 SCREW THE BOX FRAME
Match the frame diagonals before you
drive a screw.

3 FIX STB1 TO STB5 ACROSS THE
TOP

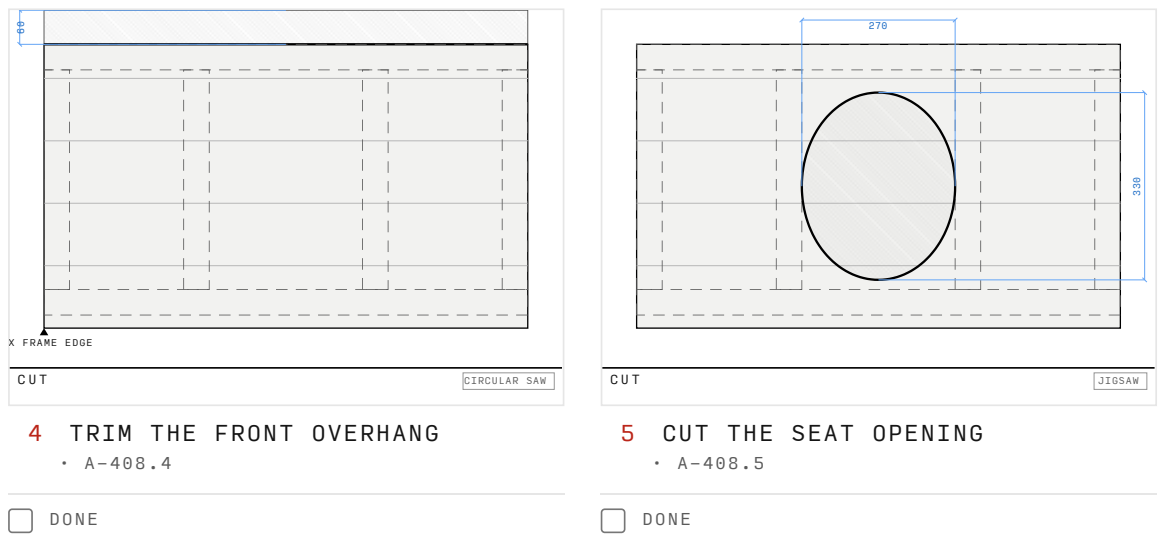
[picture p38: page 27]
CIRCULAR SAW; DONE; JIGSAW

X FRAME EDGE

4 TRIM THE FRONT OVERHANG

5 CUT THE SEAT OPENING

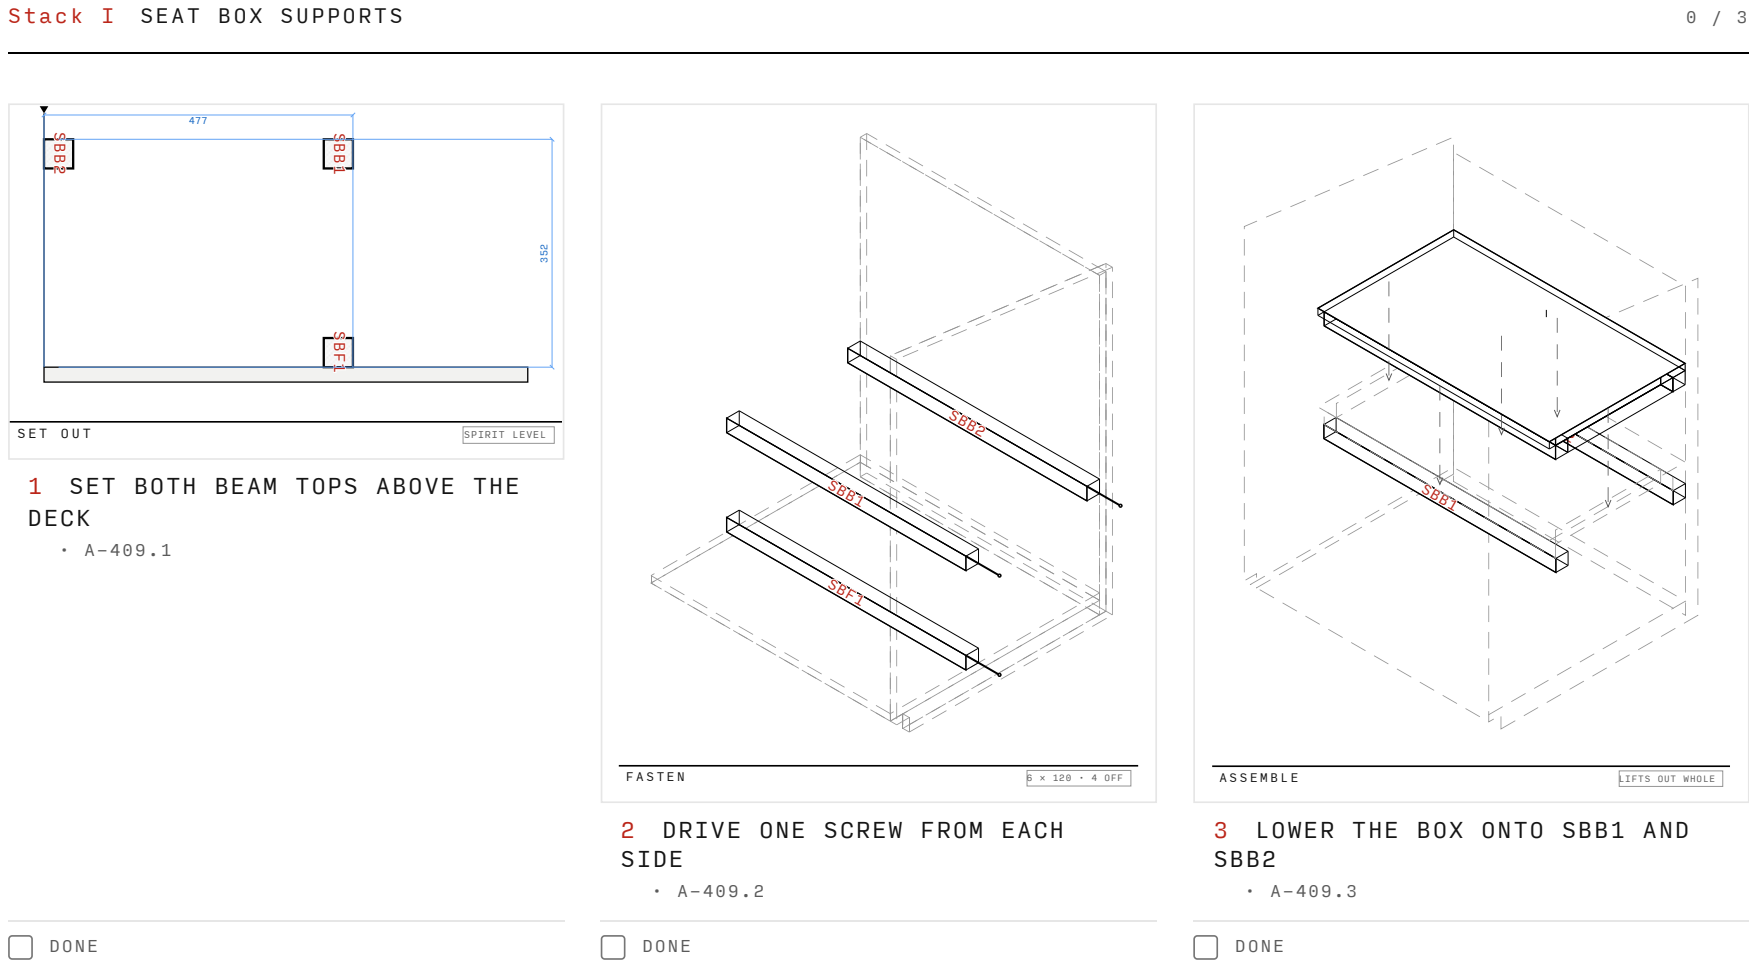
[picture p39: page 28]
Stack I SEAT BOX SUPPORTS; SBB1; SBB2; SBF1; SPIRIT LEVEL; DONE; 6 × 120 · 4 OFF; LIFTS OUT WHOLE

1 SET BOTH BEAM TOPS ABOVE THE
DECK

2 DRIVE ONE SCREW FROM EACH
SIDE

3 LOWER THE BOX ONTO SBB1 AND
SBB2

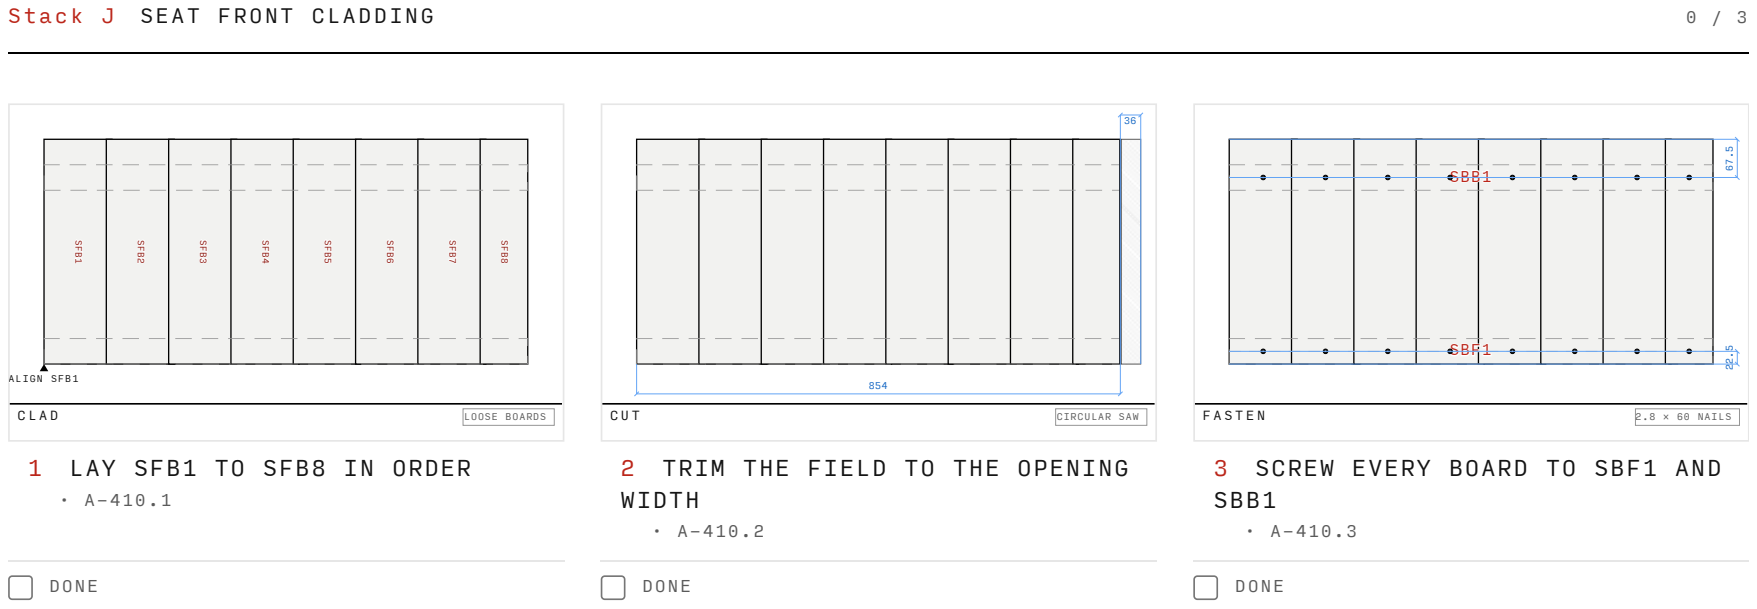
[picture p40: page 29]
Stack J SEAT FRONT CLADDING; SFB1; SFB2; SFB3; SFB4; SFB5; SFB6; SFB7; SFB8; AALLIIGGNN SSFFBB11; LOOSE BOARDS; DONE; CIRCULAR SAW; SBF1; SBB1; 2.8 × 60 NAILS

1 LAY SFB1 TO SFB8 IN ORDER

2 TRIM THE FIELD TO THE OPENING
WIDTH

3 SCREW EVERY BOARD TO SBF1 AND
SBB1

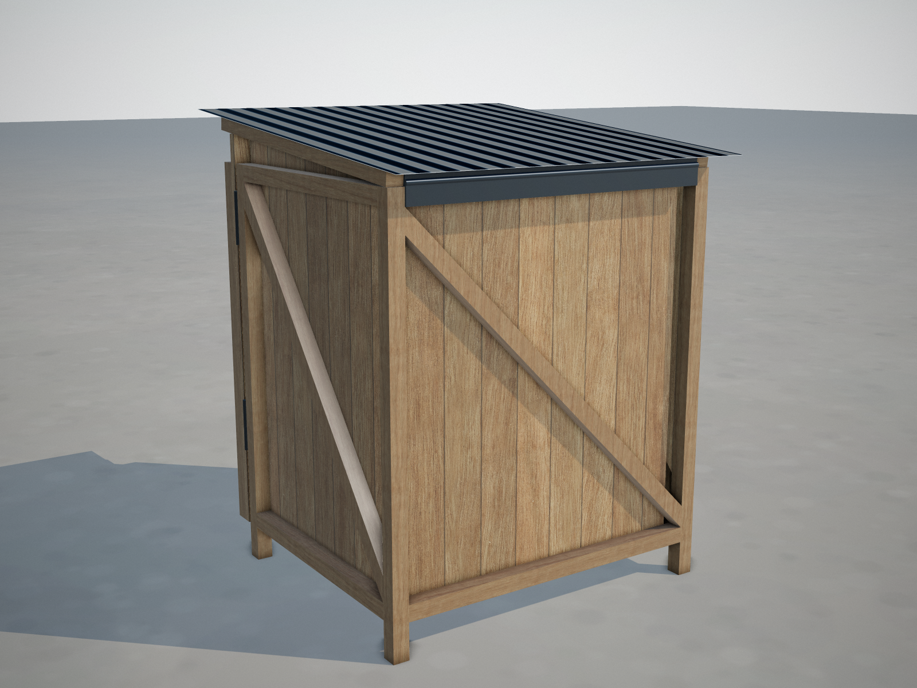
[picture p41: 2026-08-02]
build/renders/closed-rear-quarter.png

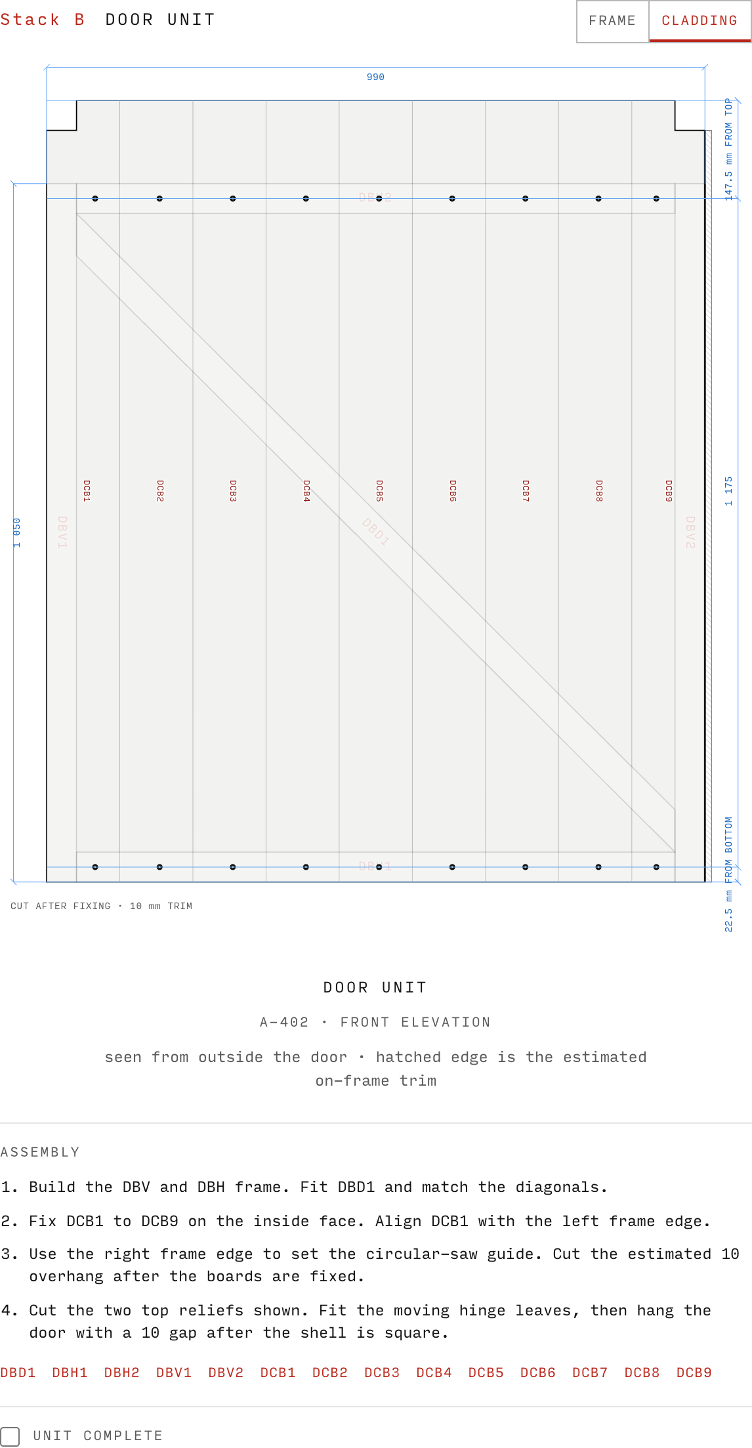
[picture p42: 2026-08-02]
docs/verification/guide/shots/unit-b-cladding-1440.png

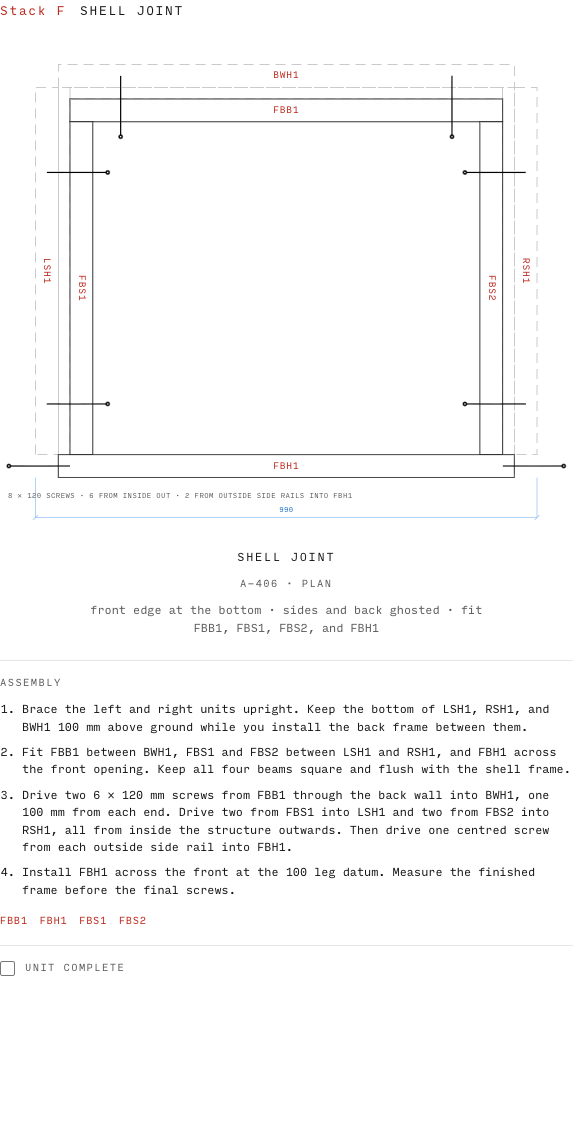
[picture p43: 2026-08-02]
docs/verification/guide/shots/unit-f-1440.png

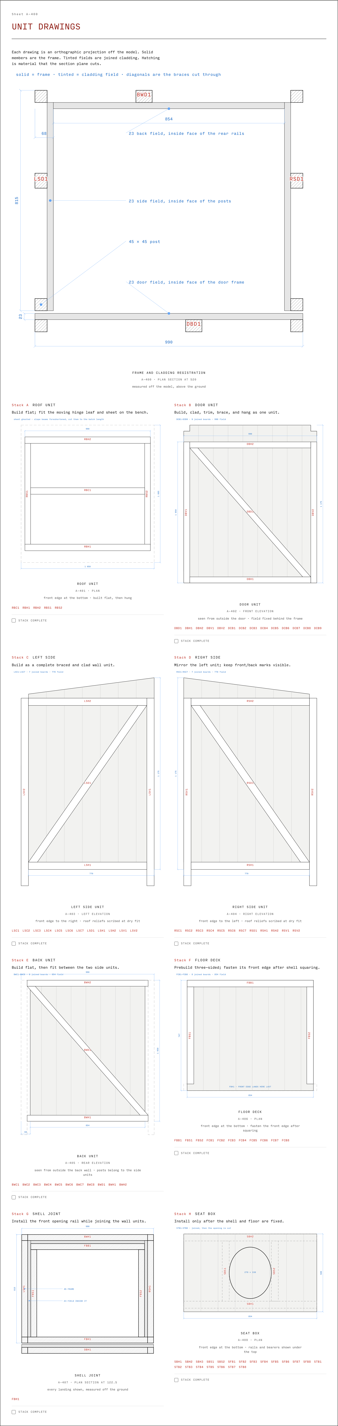
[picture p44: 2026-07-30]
docs/verification/guide/shots/stacks-1440.png

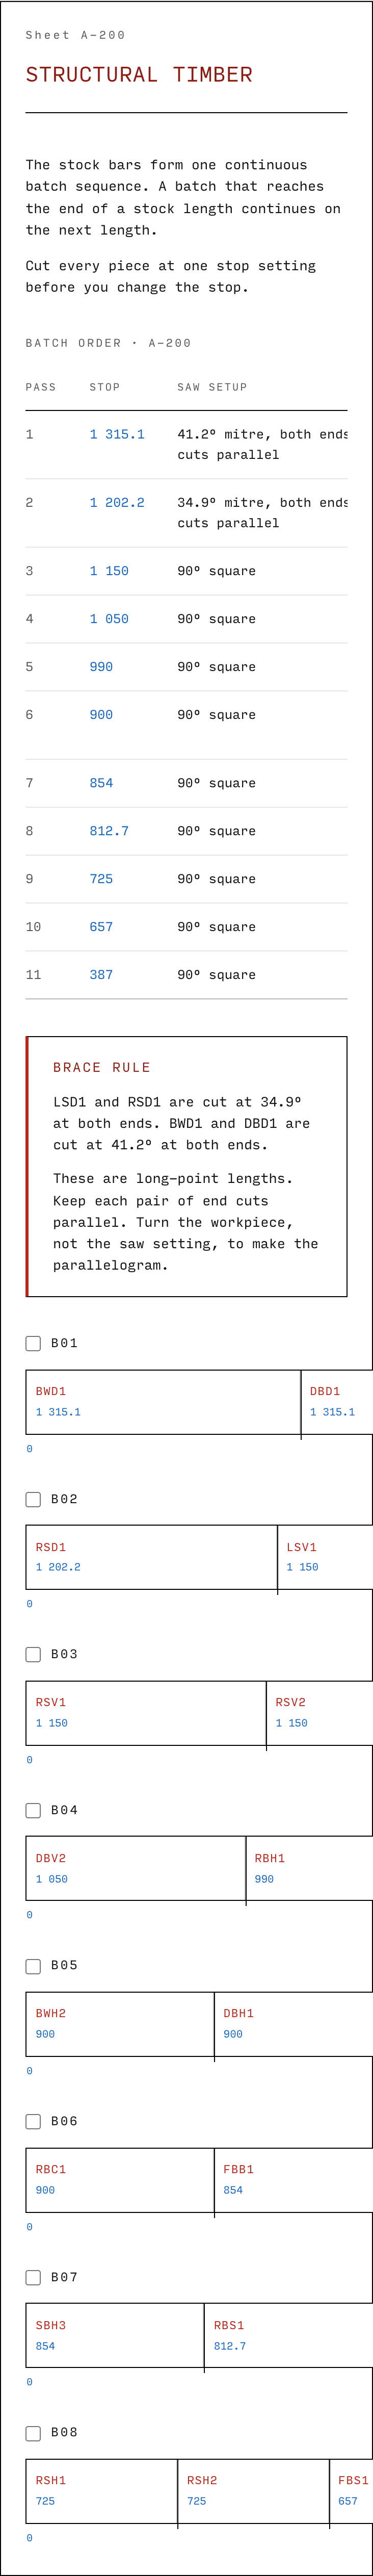
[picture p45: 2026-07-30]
docs/verification/guide/shots/beams-390.png

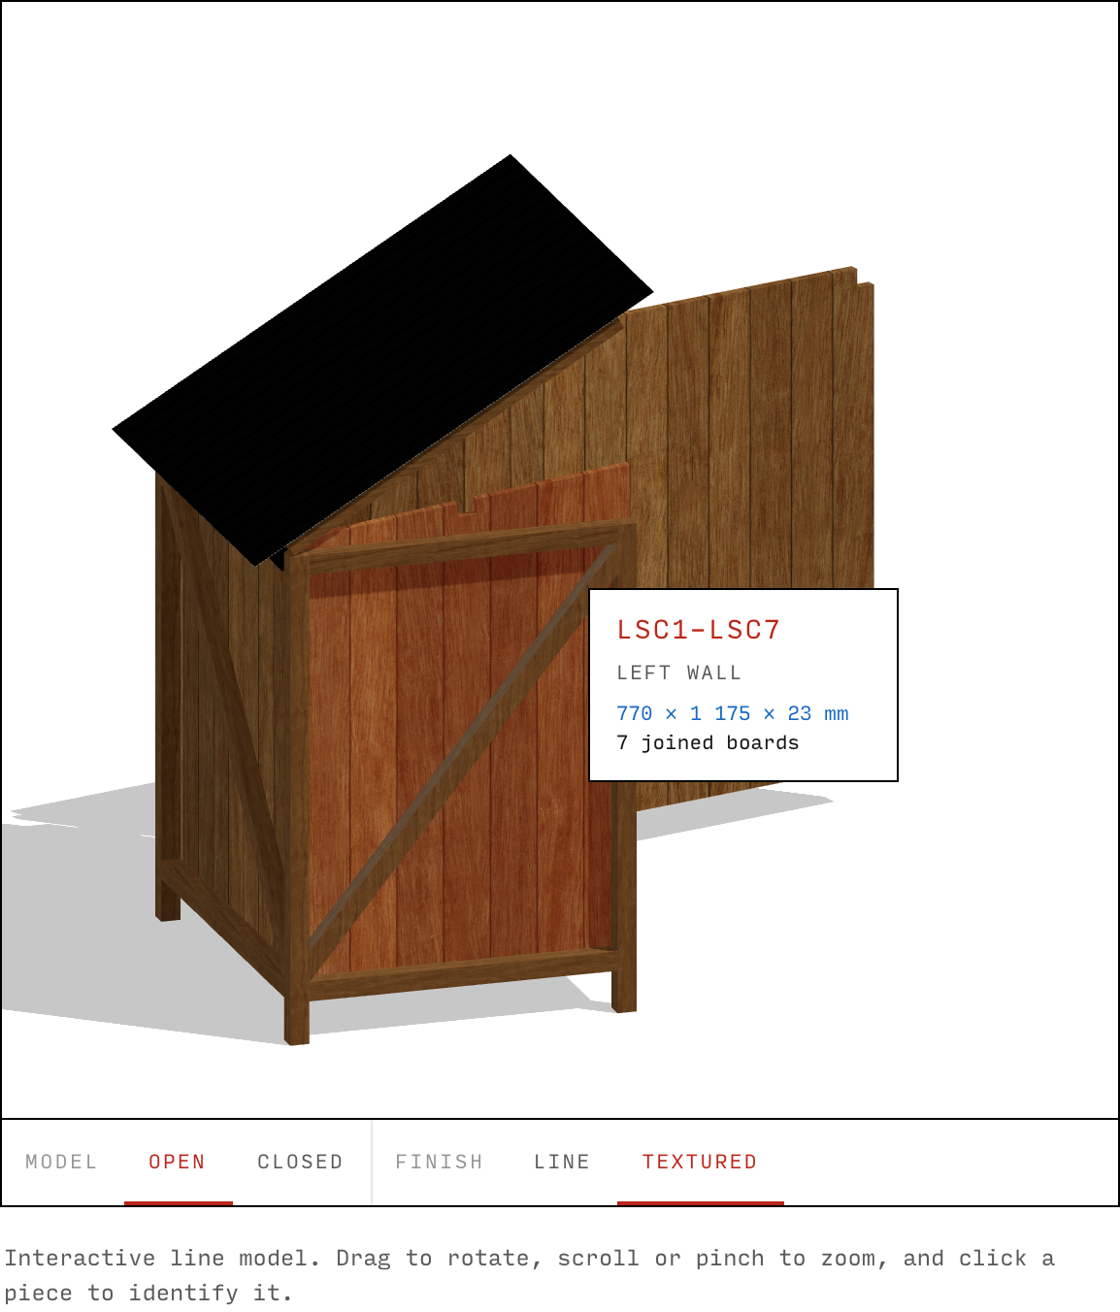
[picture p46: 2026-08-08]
docs/verification/guide/shots/viewer-textured.png

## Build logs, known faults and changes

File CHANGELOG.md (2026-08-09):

# Changelog

## 0.1.8 — The working drawing drops its Hold boxes · 2026-08-09

- Took the Hold boxes off the unit sheets. Each one sat between a unit's
  general arrangement and its first step, so a reader met a paragraph of
  deferred work before the drawing they came for. The sequences already show
  what each unit finishes with, and nothing that was held is numbered as a
  step.

## 0.1.7 — The model becomes a sheet of the set · 2026-08-08

- Put the model on a parallel projection in both finishes, at the elevation
  the unit sheets draw their assemblies on. The interactive model, both
  exported drawing renders, and the still that goes on paper now measure the
  same everywhere, so an edge carries the length it has on the building
  instead of shrinking with distance, and turning the material on no longer
  moves the building under the reader.
- Made timber white wherever it appears. The floor deck and the roof sheet
  were shaded for their material and read as grey beams beside the unit
  sheets; only a clad field carries a tone now, exactly as the sheets draw it.
- Took the photograph's film curve off the drawn model. It rolls white down to
  about four fifths, so on screen every white beam still landed grey against
  the sheet behind it and a timber barely told itself from a clad field. The
  drawing under the model changed the moment the model finished loading;
  drawn, it now carries the tones the exported drawing and the printed sheet
  carry, and nothing moves when it loads.
- Put the ground shadow back under the material finish. Its sun and its shadow
  map were switched on after the finish's shaders had already been built, so
  the shadow never reached the screen and the building floated; it stands on
  its shadow again.
- Gave the drawn model real line weights on screen. Its outlines were drawn
  one device pixel wide whatever weight they asked for, which is half a pixel
  on a retina display and left the object lines and the board joints
  indistinguishable; they are now drawn at their stated widths, so the edges
  and corners carry the drawing.
- Cleared those lines of the faces they edge. A drawn line is spread across the
  screen at the single depth its edge has, so where it lands on a face running
  away from the camera the depth test cut most of the stroke away. Inside the
  building, where every line meets a face at a shallow angle, the creases
  between the wall panels, the seat and the floor had faded to a broken
  hairline; they now carry the weight the exported drawing gives them.
- Cut the exported drawings around their own silhouette, at the heavier weight
  a sheet gives an outer edge, and filled that silhouette white. The drawings
  no longer depend on the colour of whatever they are laid over.
- Added measured dimensions to the drawn model: the ground the building
  covers, the side wall along it, and the door's width and height, drawn in
  the set's blue with architect's ticks. Every value is taken off the model as
  it is drawn, so no dimension can disagree with the geometry beside it.
- Cut the reference gallery back to the two photographs of the finished unit
  in its place. The studio renders, the drawing renders, and the six flat
  elevations were all the same geometry the reader can already turn in the
  viewer beside them.
- Cut the exported drawings to the drawing palette. The traced fills were
  carrying thousands of blended edge colours that no drawing ever asks for;
  they are now the flat tones of the set, which halved the file each reader
  downloads.

## 0.1.6 — Match the unit-drawing line finish · 2026-08-07

- Made the interactive line model and its exported drawing renders use white
  frame members, pale grey cladding, and lighter grey board joints so they
  read like the unit drawings.

## 0.1.5 — Unit drawings as a construction sequence · 2026-08-07

- Rebuilt sheet A-400 so every unit builds through its own numbered
  construction steps. Each step is a drawing of one operation rather than a
  line of prose: work already done drops back to a ghost, work the step
  touches goes solid, and a band under the drawing names the operation and the
  fastener or tool it takes. The steps replace about a thousand words of
  instruction with roughly three hundred.
- Kept a general arrangement only on the door and the two side units, which
  carry set-out no single step can show: the door reliefs, and the slope, trim
  and notch on either side. Every other unit is finished by its own last step,
  so its overall drawing was repeating what the steps already say. Dropped the
  repeated code strip under each unit for the same reason.
- Drew each frame coming together as an exploded isometric, with every member
  off its seat on the path it travels back down. Marking, cutting, fastening
  and setting-out steps stay orthographic, because a saw line, a trim and a
  notch lose precision in projection.
- Split the operations a single sentence used to carry. A side field is now
  clad, marked, gang-cut, trimmed and notched as five separate drawings, so
  no cut is made from a step that also asked for something else.
- Corrected the back unit build order: the back frame is clad and trimmed flat
  before it is set between the side units. Fitted first, the side skins stand
  in the way of the overhang the back field is cut from. The back frame also
  now states that nothing screws it together, since every fixing into it comes
  from a rear post.
- Corrected the floor deck order: the joined field is cut to the bearers
  before it is fixed, because once the boards are down there is no guide edge
  left to run the saw on.
- Added a screw step to the door, both side units and the seat box. A frame is
  driven, and checked square as it is driven, before anything is fixed to it.
  The seat box's eight beam screws are now drawn where they are made.
- Merged the two seat-support units, which drew the same bearers twice. The
  one that remains sets both beam tops off the finished deck and the inside
  back face, drives the outside screws, and then takes the box.
- Moved deliberately deferred work out of the numbered sequence into a hold
  pinned to its unit, so the roof reliefs and the hinge leaves can no longer
  be read as the next thing to do.
- Replaced the single unit checkbox with a tick per step and a progress count
  on each unit.
- Bound each general arrangement to the screen so a unit opens in one view,
  and stopped the layer toggle dimming a step drawing it was never aimed at.
- Reprinted the packet: a unit takes the sheets it needs, with its steps three
  across, no drawing split from its caption or its tick, and no empty sheet.

## 0.1.4 — Cladding screw clearance · 2026-08-02

- Centred cladding fixings on the material left after each field is trimmed,
  moving FCB8, STB5, and the other terminal-board screws away from cut edges.
- Shifted edge-board fixing marks and the seat-top screw lanes clear of the
  modeled beam-screw paths. The left and right side fields now move their first
  cladding fixings inward toward the second board.

## 0.1.3 — Matched model viewport · 2026-08-02

- Matched the interactive model's camera, scale, and position to the in-situ
  render beside it. The line, textured, fallback, and print views now use the
  same level perspective and bottom square crop as the photographed model.

## 0.1.2 — Isometric drawing completion · 2026-08-02

- Completed the removable seat-box frame with the missing SBH2-to-SBS3 and
  SBH1-to-SBS4 screws. Stack H now shows all eight beam screws around the four
  side supports, so every rail-to-support joint is explicit in the workshop
  drawing.
- Corrected Stack J to a true isometric projection and aligned the visible back
  panel face with the side panel exactly as modeled. The support installation
  view now preserves one projection and the built corner relationship.
- Changed the model's line view to the drawing-set palette and a true
  orthographic isometric camera. Added matching open and closed SVG renders;
  the open final view shows the door open and roof lifted with opaque parts,
  black outlines, and no part labels.

## 0.1.1 — Seat-box integrity update · 2026-08-02

- Rotated the seat-top boards from front-to-back to left-to-right. The schedule
  is now five STB boards at 852 mm with a 60 mm end trim, so the opening is
  carried by fewer, wider boards and is less likely to weaken during sawing.
- Added SBS3 and SBS4 as 387 mm outer side supports, matching SBS1 and SBS2,
  to close the removable seat-box frame. Added the two requested 120 mm frame
  screws at the new rail-to-support joints.
- Added FBH1 to the shell-joint assembly as an installed fourth beam, with
  centred outside-side screws, so the front opening rail has explicit support.
- Made the seat box removable at 852 mm wide and added SBB1, SBB2, and SBF1 as
  fixed shell supports. This keeps the box serviceable while supporting the
  front and rear seat edges.
- Added A-409 and A-411 support views, model-derived screw overlays, centred
  code labels, and the corresponding front-support dimensions. These make the
  workshop positions visible in the same guide as the geometry.
- Corrected diagonal brace ends and their screw paths after finding corner
  clashes. The braces now preserve the frame envelope and the audit reports
  the measured screw-path clearance.
- Added dated model notes and the model version summary to the progress page.

## 0.1.0 — Public release 001 · 2026-07-31

This records the current package version as the first public release.

- Added a model-derived frame fastening audit covering 42 beam-to-beam
  connections and 84 nominal screw marks. The current layout has no overlapping
  screw marks. Cladding remains outside the audit because its fasteners are
  handled separately.
- Moved diagonal screw marks 90 mm in from each end so they clear the existing
  rail and post screw rows. No frame geometry adjustment was needed.
- Added finished-frame angle checks. Measure the side pitch, roof pitch, and
  diagonal cut angle on the assembled frame before final fastening, using the
  drawing and model values as the guide and scribing to the measured result if
  the frame has moved.
- Added a workshop stock-end clean-up pass before cutting beams and cladding
  planks.

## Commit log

2026-07-30 feat(cad-viewer): vendor cad-viewer skill runtime
    Add the cad-viewer agent skill, including built prebuilt viewer assets
    (backend server, dist bundle), the cadjs/cadpy/implicitjs runtime
    packages, and the optional MoveIt2 conda-based server for SRDF IK and
    planning support.
    [beam-pieces.csv, cladding-pieces.csv, cutlist-side-by-side.csv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]
2026-07-30 feat(dass): support 45x45 frame / 120x20 cladding variant
    Add roof_connector_width/thickness params to Design so the roof
    connector profile follows the frame size instead of a hardcoded
    65x25 beam, and generalize generate_cutlists.py's beam_pieces filter
    and CLI to accept arbitrary --set overrides for any Design field.
    Include the generated build-45x45-120x20 output (STEP/GLB/PNG,
    cutlists, stock plan, and comparison-and-structural-check.md) showing
    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
    [beam-pieces.csv, cladding-pieces.csv, cutlist.csv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]
2026-07-30 feat(dass): add floor diagonal brace to 45x45/120x20 variant
    Reduces the mid-span floor board loading by shortening effective
    span near the centre, but leaves the two opposite corners near
    original span length since the diagonal approaches an existing
    support there. Also adds an exact branch-and-bound packing fallback
    in generate_cutlists.py so small beam schedules don't waste stock
    lengths when greedy bin-packing strands a short leftover piece.
    [beam-pieces.csv, cutlist.csv, dass-closed.step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]
2026-07-30 feat(dass): single-cut braces, lifted side panels, and seat supports
    Braces now take one angled saw cut per end. A bar centred on the
    corner-to-corner diagonal overshoots both boundaries at each corner, so
    clipping left a notched point built from two faces. Each brace is tilted
    off the diagonal by asin(size/span), putting one long face through each
    corner, so a single plane trims each end and the piece is a parallelogram
    prism of exactly six faces. Because both ends are mitred, the longest edge
    falls ~36 mm short of the stock needed, so the cut list now reports the
    long-point length sqrt(diagonal^2 - size^2): D1 1209.3, D2 1273.8.
    Side cladding no longer parallels the roof. The front edge s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
    [beam-pieces.csv, cladding-pieces.csv, cutlist-side-by-side.csv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]
2026-07-31 refactor: reorganize into src/ layout and prune build artifacts
    Move Python modules to src/dass/ package layout with a pyproject entry
    point (`serve-guide`) for the dev loop. Rename generate_cutlists.py to
    cutlists.py, generate_build_guide.py to build_guide.py, dass.py to
    model.py, render_photo.py to photo_render.py, add serve.py for
    build/serve/watch. Fold dass.md into README.md and update PRODUCT.md
    and AGENTS.md references.
    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
    [beam-pieces.csv, cladding-pieces.csv, cutlist-side-by-side.csv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]
2026-07-31 feat(dass): add social-card metadata to public pages
    Add Open Graph and Twitter Card tags plus canonical links to the
    cut-guide, how-it-started, and how-its-going pages via a shared
    social_head() helper, so shared links render title, description,
    and preview image. Deploy script now also copies how-it-started.html.
2026-07-31 fix(dass): stop diagonal-brace screw collisions at frame corners
    Diagonals previously ran full corner-to-corner, sharing the door,
    side, and back rail corners with vertical-member screws. A 120 mm
    screw from a vertical member into a rail could clash with the screw
    driven from that rail into the diagonal. Diagonals now mitre to the
    inner faces of the vertical members, keeping the long-point geometry
    while avoiding the shared corner. Adds a fastening model that records
    screw direction, station, and lane; a diagonal screw angle; and
    path-collision detection, regression-tested for all eight
    vertical-to-diagonal joins. Adds the model-derived fastening audit
    (42 connections, 84 screw marks, 0 coll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
    [beam-pieces.csv, cutlist-side-by-side.csv, cutlist.csv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]
2026-07-31 chore: add ruff, ty and pytest dev dependencies
    Pin all four exactly. ty is pre-1.0 and ruff changes its formatter between
    minor releases, so an unpinned upgrade would break the hooks and CI on an
    unrelated commit.
    Exclude .agents/, build/ and .cache/ from every tool. .agents/ is vendored
    skill code that ruff and ty would otherwise lint as if it were ours.
2026-07-31 style: format the codebase with ruff
    Formatting only. No logic changed: the cut schedules, the build guide, and
    both evolution pages regenerate byte for byte identical from the formatted
    and unformatted trees.
2026-07-31 chore: fix ruff lint findings
    Sort imports, parenthesise the implicit string concatenations inside the step
    tuples, drop two dead locals in the seat-box plate, and iterate the image cut
    list with .items().
    Both subprocess.run calls already inspect the return code themselves, so they
    are marked check=False rather than made to raise.
    The blind except in the build loop is deliberate and keeps a targeted noqa:
    a stage that raises must be reported without taking the watch loop down.
    The guide, the evolution pages, and the cut schedules regenerate byte for byte
    identical.
2026-07-31 fix: resolve ty type errors
    Sixteen of the twenty-six diagnostics were real and are fixed at the source:
    - serve.staging() read .loader off a spec that spec_from_file_location returns
    as None for any source it has no loader for, so a renamed stager raised an
    AttributeError that named neither the file nor the cause. It now raises an
    ImportError naming the path, with a regression test that fails on the old
    code with exactly the AttributeError it replaced.
    - A cut-list test compared finished_long with finished_short while both are
    optional, so a None would have crashed the test rather than failed it. The
    assertion now tests for that.
    - Pillow's bare Image.LANCZOS and Image.FLIP_* a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
2026-07-31 ci: pin the actions to exact releases
    setup-uv publishes v9.0.0 without a moving v9 tag, so the major alias did not
    resolve and every job failed in the set-up step. Pin both actions to the exact
    release, matching how the Python tools are pinned.
2026-07-31 feat(build-guide): add leg-extension dims to side/back unit plates
    Side and back unit drawings showed the front-frame leg but not the
    bottom overhang, leaving builders to infer the ground clearance. Add a
    100mm dimension line from post base to bottom edge on units C/D/E, and
    call out the 100mm ground clearance explicitly in the shell-joint
    assembly step instead of leaving it implicit.
2026-07-31 feat(dass): add the assembly hardware schedule
    Name the fastener for each joint class in the guide, the fastening report,
    PRODUCT.md and README.md, so the workshop is not left to infer them: 120 mm
    screws for frame beams and braces, 90 mm for beam-to-beam supports, and nails
    or 60 mm screws for cladding.
    Cladding was described as "nailed", which made the beam-screw warning read as
    though it were about nails specifically. It is about not carrying the cladding
    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
2026-08-01 test: cover every measured line and finish the annotations
    Take `src/dass` and `scripts` from 66% to 100% of lines and branches, and set
    `fail_under = 100` so the gate is binary rather than a ratchet.
    Nothing is omitted and the tree holds no `# pragma: no cover`. That is the
    point: an exclusion is how this number stays green while coverage rots, so the
    four modules that were at 0% -- the two audits, the overlay generator and the
    asset stager -- are tested rather than excluded, and so is the texture
    synthesis in photo_render.py, which is ordinary in-process Pillow work with a
    browser only at the far end of it.
    CLI entry points get the same treatment. Every `main()` is reached by injecting
    a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
2026-08-02 feat(dass): complete seat assembly drawings
    Add the fixed and removable seat supports, audited fastening details, updated field notes, and model-aligned interactive, fallback, and print views.
    [beam-pieces.csv, cladding-pieces.csv, cutlist-side-by-side.csv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]
2026-08-02 feat(dass): centre cladding screws on trimmed boards
    Fixings on terminal boards were placed by nominal cover width, so trimming shortened the material without moving the screw off the cut edge. Locate each cladding screw on the board's actual post-trim span instead, and nudge edge fixings and seat-top screw lanes clear of the modeled beam-screw paths. Left/right side fields now shift their first cladding fixing inward toward the second board to keep clearance.
    Bump version to 0.1.4 and regenerate the guide, changelog, and verification screenshots.
2026-08-07 feat(dass): rebuild unit drawings as construction sequences
    Rebuild sheet A-400 so every unit builds through numbered,
    single-operation steps instead of prose. Ghost prior work, solidify
    the step's own touch points, and label each step with its operation
    and fastener/tool in a band beneath. Keep a general arrangement only
    on the door and side units, which carry set-out no single step can
    show. Add exploded-isometric assembly steps with travel tracks, and
    orthographic marking/cutting/setting-out steps with datums and
    set-out lines.
    Correct the back unit build order (clad and trim flat before fitting
    between the side units) and the floor deck order (cut the joined
    field to the bearers before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
2026-08-08 feat(dass): restyle the model viewer as a drawing-set sheet
    The line model now projects orthographically at the plate elevation with
    plate linework (1.0px ink over 0.5px joints, 1.4px silhouette), white
    timber fills, and measured blue dimensions; the textured finish shares
    the same camera. Tone mapping now applies only to the textured finish,
    which also revives its ground shadow (shader rebuild on toggle picks up
    the shadow state that never compiled in before). The masthead gallery
    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
2026-08-09 feat(dass): drop the Hold boxes from the unit sheets
    Each Hold sat between a unit's general arrangement and its first step, so
    the sheet opened with a paragraph of deferred work instead of the drawing.
    The hinge and roof-relief work those boxes named is still absent from the
    numbered steps, so nothing invites a builder to do it early.
